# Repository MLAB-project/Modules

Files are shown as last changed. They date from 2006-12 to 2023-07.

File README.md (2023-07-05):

# MLAB hardware modules main repository

The MLAB Project was created to develop an universal kit to support hobbyist and professionals in the construction of simple or more complicated devices and instruments (robots, automation systems, testing kits and so on). It is primarily intended for engineers and scientists and it is in continuous development since 2003.

**This repository is archived because its contents have been split into separate repositories in the [MLAB-modules](https://github.com/mlab-modules/) organization. The development of new [MLAB](https://www.mlab.cz) components is still in progress and development has not been suspended. You can read about the reasons of the repository split on the [Discussions thread](https://github.com/orgs/MLAB-project/discussions/1).**

This repository is only a component of the [complete MLAB system](http://www.mlab.cz/)

## Modules

The principle of [Modular LABoratory](http://www.mlab.cz) is based on decomposition of complex systems into smaller cells or bricks (in MLAB called [modules](http://wiki.mlab.cz/doku.php?id=en:moduly)) such as communication interfaces, operational amplifiers, CPU modules, FPGA programmers and many other. Over years of development, [tenths of modules have been created](https://github.com/mlab-modules) - for easier orientation they are sorted into categories which are the first-level folders of this repository. Many modules are included as [repository submodules](https://git-scm.com/book/en/v2/Git-Tools-Submodules) in this parent repository. 



When creating modules, great emphasis is put on the quality of design and construction. The results can, therefore, meet the standards of even the most demanding users from the community of researchers, experimenters and innovators.

## How to start using MLAB

Further information can be found on [MLAB Wiki](http://wiki.mlab.cz/).

There is also a [Mailing list](https://groups.google.com/forum/#!forum/mlab-users) available for users and developers.

## Compatibility

Thanks to careful design, most of the modules are dimensionally and electrically compatible with many other products. Examples include the Arduino platform, the Merkur construction set, optical tables and DIN switchboard systems.

## Applications

See the [list of designs](http://home.mlab.cz/Server/GenIndex/GenIndex.php?path=%2FDesigns&lang=en) for an illustration of the wide spectrum of possible applications.

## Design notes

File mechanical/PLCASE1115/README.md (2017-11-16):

[Czech](./README.cs.md)
<!--- module --->
# PLCASE1115
<!--- Emodule --->

<!--- subtitle --->3D printable plastic case<!--- Esubtitle --->

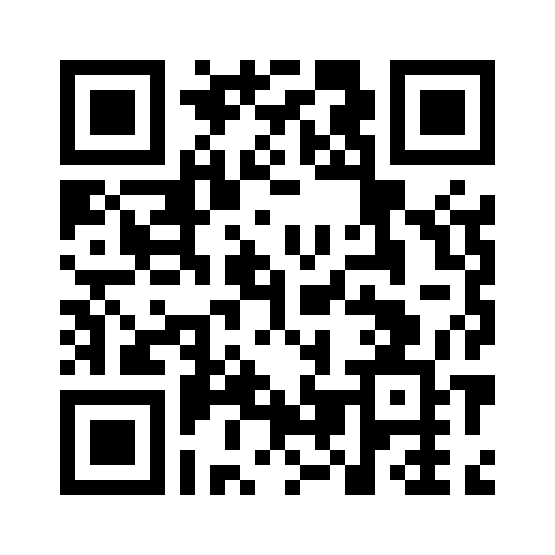
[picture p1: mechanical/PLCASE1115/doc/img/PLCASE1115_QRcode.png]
PLCASE1115


<!--- description --->Basic printable case for the base board with size 11x15 holes. <!--- Edescription --->

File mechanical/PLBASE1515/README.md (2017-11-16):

[Czech](./README.cs.md)
<!--- module --->
# PLBASE1515
<!--- Emodule --->

<!--- subtitle --->3D printable plastic base board<!--- Esubtitle --->

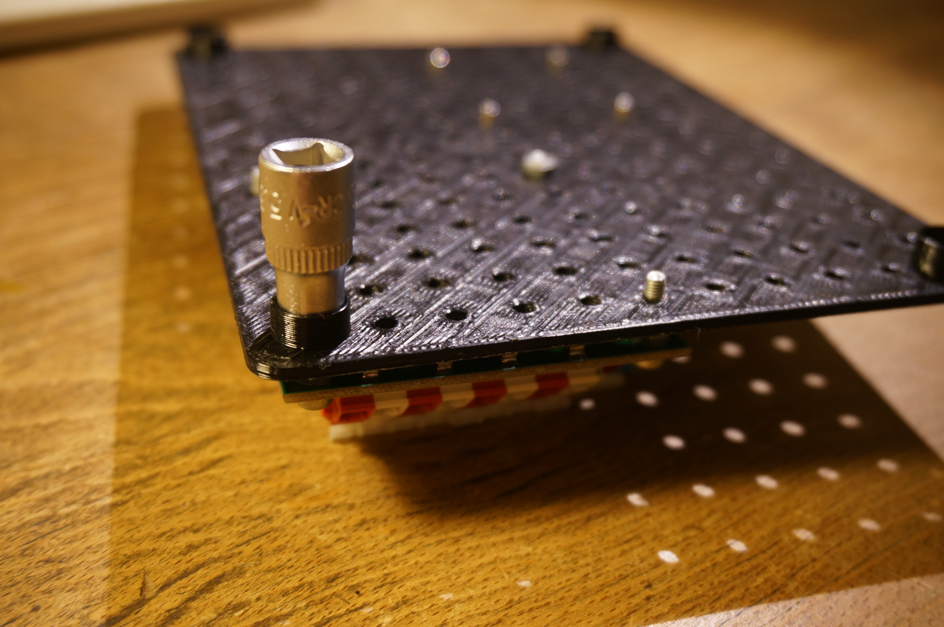
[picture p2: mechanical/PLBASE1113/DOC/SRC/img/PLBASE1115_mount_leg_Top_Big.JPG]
PLBASE1515


<!--- description --->This base board has size 11x15 holes and standard MLAB grid 400mils (10.16mm). It is especially suited for simple measuring instruments and mobile robots constructions. The board can be prited at almost any 3D printer.<!--- Edescription --->

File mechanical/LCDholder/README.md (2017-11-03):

[Czech](./README.cs.md)
<!--- module --->
# LCDholder
<!--- Emodule --->

<!--- subtitle --->3D printable LCD 16x2 holder for MLAB base boards<!--- Esubtitle --->

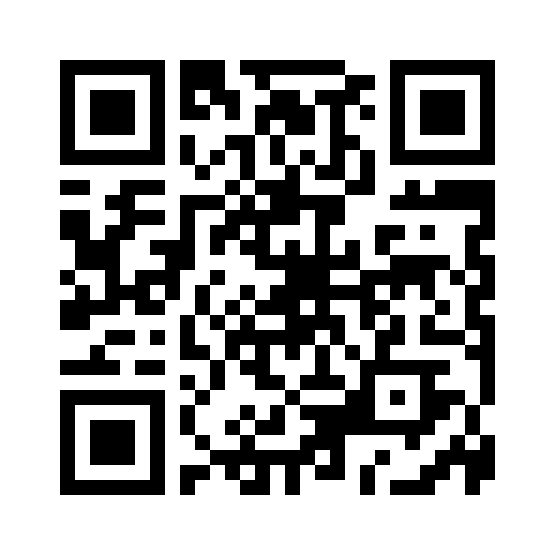
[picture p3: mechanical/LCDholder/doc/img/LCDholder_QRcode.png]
LCDholder


<!--- description --->The hodlder can be prited at almost any 3D printer.<!--- Edescription --->

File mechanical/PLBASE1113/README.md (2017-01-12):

<!--- PrjInfo ---> <!--- Please remove this line after manually editing --->
<!--- 00a56be08b96043df9e37d6aff7b6990 --->
<!--- Created:20170112-18:22: ---> 
<!--- Author:Mlab: ---> 
<!--- AuthorEmail:mlab@mlab.cz: ---> 
<!--- Tags:imported: ---> 
<!--- Ust:[End]: ---> 
<!--- Name:PLBASE1115: --->
#PLBASE1115 
<!--- LongName --->
3D printable plastic base board
<!--- ELongName ---> 

<!--- Lead --->
This base board has size 11x15 holes and standard MLAB grid 400mils (10.16mm). It is especially suited for simple measuring instruments and mobile robots constructions. The board can be prited at almost any 3D printer.
<!--- ELead ---> 

LeadImg 

<!--- Description --->
<!--- EDescription --->
<!--- Content --->
<!--- EContent --->

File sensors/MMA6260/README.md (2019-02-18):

<!--- PrjInfo ---> <!--- Please remove this line after manually editing --->
<!--- 00a56be08b96043df9e37d6aff7b6990 --->
<!--- Created:2019-02-18 14:38:43.239192: ---> 
<!--- Author:: ---> 
<!--- AuthorEmail:: ---> 
<!--- Tags:: ---> 
<!--- Ust:: ---> 
<!--- Label --->
<!--- ELabel ---> 
<!--- Name:MMA6260: --->
# MMA6260
<!--- LongName --->
## Simple 2axis analog accelerometer sensor
<!--- ELongName ---> 

<!--- Lead --->

<!--- ELead ---> 

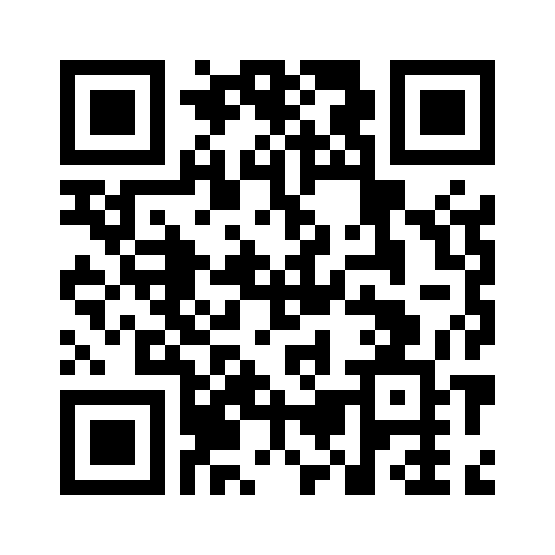
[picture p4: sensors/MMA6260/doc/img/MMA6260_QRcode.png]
MMA6260
 

<!--- Description --->
<!--- EDescription --->
<!--- Content --->
<!--- EContent --->
<sub><sup> Generated with [MLABweb](https://github.com/MLAB-project/MLABweb). (2019-02-18)</sup></sub>

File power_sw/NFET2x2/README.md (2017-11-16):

[Czech](./README.cs.md)
<!--- module --->
# NFET2x2
<!--- Emodule --->

<!--- subtitle --->2x2NFET Power Driver <!--- Esubtitle --->

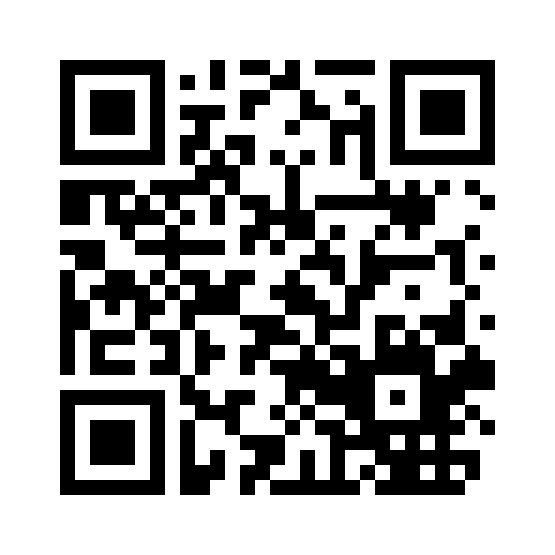
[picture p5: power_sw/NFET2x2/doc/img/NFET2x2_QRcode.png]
NFET2x2


<!--- description --->There are 4 NFETs switching to earth. Inductive load is allowed.<!--- Edescription --->

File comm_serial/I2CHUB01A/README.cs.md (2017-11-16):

[English](./README.md)
<!--- module --->
# I2CHUB01A
<!--- Emodule --->

<!--- subtitle ---> Hub pro sběrnici I2C (TWI) <!--- Esubtitle --->

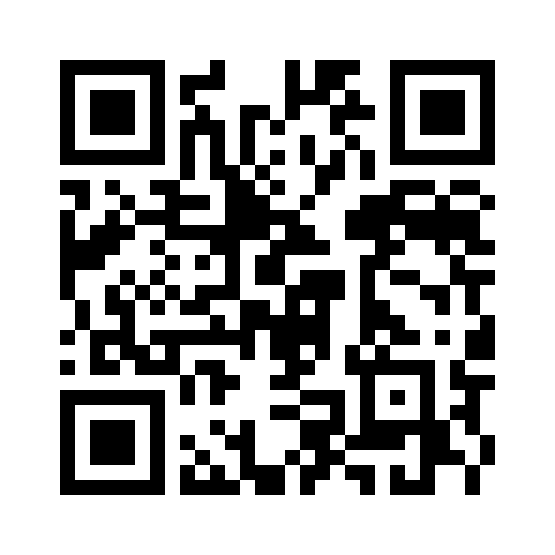
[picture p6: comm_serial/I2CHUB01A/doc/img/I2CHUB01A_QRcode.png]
I2CHUB01A


<!--- description ---> Umožňuje propojení většího počtu I2C zařízení. Neobsahuje žádnou konfigurovatelnou logiku.<!--- Edescription --->

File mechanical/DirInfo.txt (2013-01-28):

//
// Toto je popisný soubor pro popis obsahu adresáře
//

[InfoShortDescription.en]
  Mechanical

[InfoShortDescription.cs]
  Mechanické části
  
[InfoLongDescription.en]
  Universal boxes, base plates and other mechanical accessories.

[InfoLongDescription.cs]
  Univerzální krabičky, základní desky a další mechanické příslušenství.

[SortPreferences]

[End]

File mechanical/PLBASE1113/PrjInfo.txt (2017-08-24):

[InfoShortDescription.en]
3D printable plastic base board

[InfoShortDescription.cs]
3D tisknutelná základní deska

[InfoLongDescription.en]
This base board has size 11x15 holes and standard MLAB grid 400mils (10.16mm). It is especially suited for simple measuring instruments and mobile robots constructions. The board can be prited at almost any 3D printer.

[InfoLongDescription.cs]
Základní deska má 11x15 děr se standardní MLAB roztečí 400mils (10.16mm). Je vhodná pro malé konstrukce, jako jsou jednoduché meřící přístroje nebo základní mobilní roboti. Je tisknutelná téměř na každé 3D tiskárně.

[InfoBuyUST]

[End]

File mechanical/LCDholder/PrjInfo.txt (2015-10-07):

[InfoShortDescription.en]
3D printable LCD 16x2 holder for MLAB base boards

[InfoShortDescription.cs]
3D tisknutelný držák LCD 16x2 pro MLAB základní desky

[InfoLongDescription.en]
The hodlder can be prited at almost any 3D printer.

[InfoLongDescription.cs]
Držák je tisknutelný téměř na každé 3D tiskárně.

[InfoBuyUST]

[End]

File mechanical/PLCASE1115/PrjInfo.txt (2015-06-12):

[InfoShortDescription.en]
3D printable plastic case

[InfoShortDescription.cs]
3D tisknutelná krabička 

[InfoLongDescription.en]
Basic printable case for the base board with size 11x15 holes. 

[InfoLongDescription.cs]
Jednoduchá tisknutelná krabička na základní desku rozměru 11x15 děr.

[InfoBuyUST]

[End]

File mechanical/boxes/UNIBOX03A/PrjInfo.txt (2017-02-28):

[InfoShortDescription.en]
Permanent device housing box

[InfoShortDescription.cs]
Krabička pro permanentní konstrukce

[InfoLongDescription.en]
Universal metal module housing box with interchangeable front and back panels. Useful for housing construction of devices created from MLAB modules. With a pair of sidewalls printable 3D printer. Dimensions 220x160x51.5 mm. 

[InfoLongDescription.cs]
Univerzální kovová krabička pro zakrytování permanentních konstrukcí z modulů MLAB. S dvojicí tisknutelných bočnic na 3D tiskárně. Rozměry 220x160x51.5 mm.  

[End]

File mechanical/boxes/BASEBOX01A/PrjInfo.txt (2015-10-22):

[InfoShortDescription.en]
3D printable device housing box

[InfoShortDescription.cs]
3D tisknutelná krabička pro permanentní konstrukce

[InfoLongDescription.en]
The printed plastic parts are sandwiched between standard hole-grid plates which makes the enclosure very rigid. The box sides can be easily customized for individual project needs, or separately exchanged during an instrument development.

[InfoLongDescription.cs]
Univerzální krabička tisknutelná 3D tiskárnou pro zakrytování permanentních konstrukcí z modulů MLAB.  

[End]

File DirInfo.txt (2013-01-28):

//
// Toto je popisný soubor pro popis obsahu adresáře
//

[InfoShortDescription.en]
  Overview of MLAB Modules

[InfoShortDescription.cs]
  Přehled modulů MLAB
  
[InfoLongDescription.en]
  You can find an overview of MLAB Modules here. They are organised
  to groups by their function.
  
[InfoLongDescription.cs]
  Moduly jsou univerzální "kostky" do stavebnice MLAB. Protože jich je
  hodně, jsou dále rozčleněny po skupinách.

[SortPreferences]
  AVR
  ARM
  PIC
  CommIR
  CommRF
  CommSerial
  Clock
  TDC
  PowerSupply
  PowerSW
  H_Bridge
  Sensors
  HumanInterfaces
  Measuring
  Memory
  Audio
  OpAmps
  ADconverters
  Universal
  Mechanical

[End]

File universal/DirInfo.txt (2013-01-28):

//
// Toto je popisný soubor pro popis obsahu adresáře
//

[InfoShortDescription.en]
  Universal PCBs

[InfoShortDescription.cs]
  Univerzální desky
  
[InfoLongDescription.en]
  Universal soldering circuit boards and more.

[InfoLongDescription.cs]
  Univerzální pájecí plošné spoje a další.

[SortPreferences]

[End]

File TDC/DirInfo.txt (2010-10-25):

//
// Toto je popisný soubor pro popis obsahu adresáře
//

[InfoShortDescription.en]
  Time to Digital Converters

[InfoShortDescription.cs]
  Časově digitální převodníky
  
[InfoLongDescription.en]
  Modules for experimentation with time interval signals in digital systems. e.g. LASER ranging.

[InfoLongDescription.cs]
  Moduly pro digitalizaci časových intervalů. Hodí se pro experimenty, jako je například LASERové měření vzdálenosti.

[SortPreferences]

[End]

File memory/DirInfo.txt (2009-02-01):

//
// Toto je popisný soubor pro popis obsahu adresáře
//

[InfoShortDescription.en]
  Storage devices

[InfoShortDescription.cs]
  Paměťové prvky
  
[InfoLongDescription.en]
  Memory and data storage modules.

[InfoLongDescription.cs]
  Moduly určené k uchovávání dat.

[SortPreferences]

[End]

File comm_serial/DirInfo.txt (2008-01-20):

//
// Toto je popisný soubor pro popis obsahu adresáře
//

[InfoShortDescription.en]
  Serial communication

[InfoShortDescription.cs]
  Sériová komunikace
  
[InfoLongDescription.en]
  Serial communication includes ordinary RS232 and 
  USB, I2C and so on.
  
[InfoLongDescription.cs]
  Sériová komunikace zahrnuje přenos dat po RS232, ale 
  i přenos pomocí USB, I2C a podobně.

[SortPreferences]

[End]

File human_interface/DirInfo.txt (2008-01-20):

//
// Toto je popisný soubor pro popis obsahu adresáře
//

[InfoShortDescription.en]
 Human Interface Modules

[InfoShortDescription.cs]
  Moduly pro interakci s uživatelem
  
[InfoLongDescription.en]
  Modules for interaction with a user. Displays, indicators,
  switches, push buttons and so on.

[InfoLongDescription.cs]
  Jedná se o moduly displejů, indikátorů a vstupů od uživatele.
  Tlačítka, spínače a podobně.

[SortPreferences]

[End]

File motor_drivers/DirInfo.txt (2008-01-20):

//
// Toto je popisný soubor pro popis obsahu adresáře
//

[InfoShortDescription.en]
  H-Bridge Modules

[InfoShortDescription.cs]
  Moduly H-můstků
  
[InfoLongDescription.en]
  Modules for bipolar switching, mainly used for motor driving.

[InfoLongDescription.cs]
  Moduly umožňující bipolární spínání napětí, zejména pro 
  účely řízení motorů.

[SortPreferences]

[End]

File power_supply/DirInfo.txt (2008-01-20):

//
// Toto je popisný soubor pro popis obsahu adresáře
//

[InfoShortDescription.en]
  Power Supply

[InfoShortDescription.cs]
  Napájecí zdroje
  
[InfoLongDescription.en]
  You can find here power supplies, stabilisers and battery
  circuits.
  
[InfoLongDescription.cs]
  Zde jsou napájecí zdroje, stabilizátory a obvody s bateriemi.

[SortPreferences]

[End]

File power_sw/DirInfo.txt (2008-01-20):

//
// Toto je popisný soubor pro popis obsahu adresáře
//

[InfoShortDescription.en]
  Power Switches

[InfoShortDescription.cs]
  Výkonové spínače
  
[InfoLongDescription.en]
  Power Switches for switching of bigger voltages and currents
  which exceeded processor's capabilities.

[InfoLongDescription.cs]
  Výkonové spínače pro spínání proudů a napětí, které přesahují 
  možnosti samotných procesorů.

[SortPreferences]

[End]

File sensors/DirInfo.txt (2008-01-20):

//
// Toto je popisný soubor pro popis obsahu adresáře
//

[InfoShortDescription.en]
  Sensors

[InfoShortDescription.cs]
  Senzory
  
[InfoLongDescription.en]
  Sensors, mainly for robotics and measurement of the environment.

[InfoLongDescription.cs]
  Senzory, hlavně pro robotiku a měření prostředí.

[SortPreferences]

[End]

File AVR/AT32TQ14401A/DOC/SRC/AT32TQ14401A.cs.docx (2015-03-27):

Modul pro mikrokontroléry Atmel AVR32 řady AT32UC3A

Jakub Kákona

## Modul obsahuje potřebné součástky pro provoz mikrokontroléru Atmel AVR32 řady AT32UC3A.

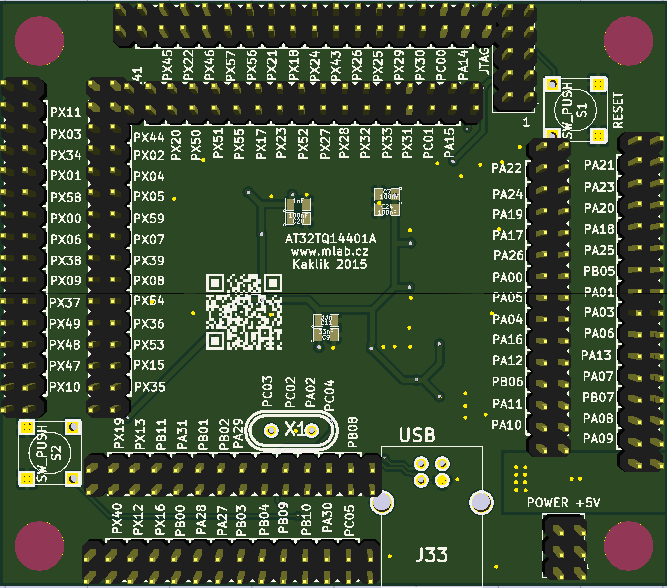
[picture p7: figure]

# 1. Technické parametry

Parametr | Hodnota | Poznámka
Napájení | 5 V
Rozměry | 80 x 70 x 16 mm | Výška nad základní deskou

# 2. Osazení a oživení

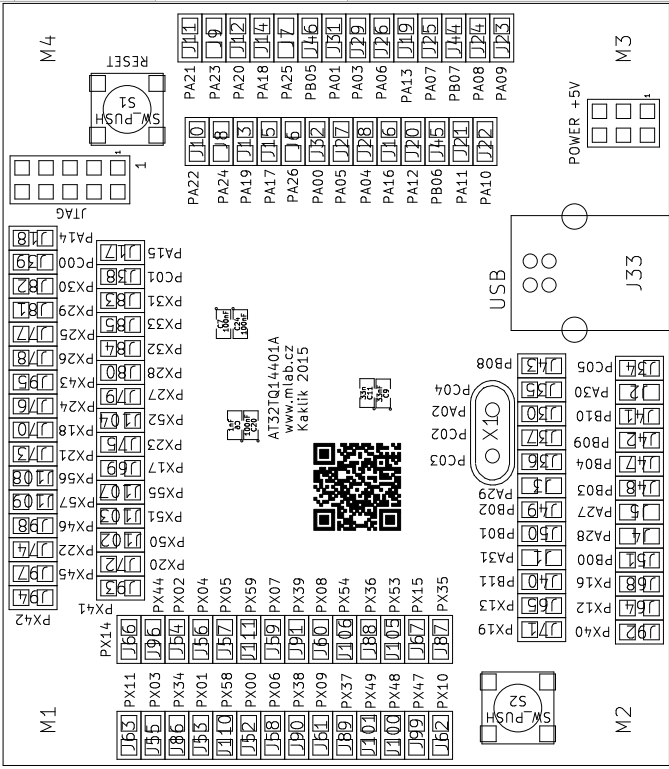
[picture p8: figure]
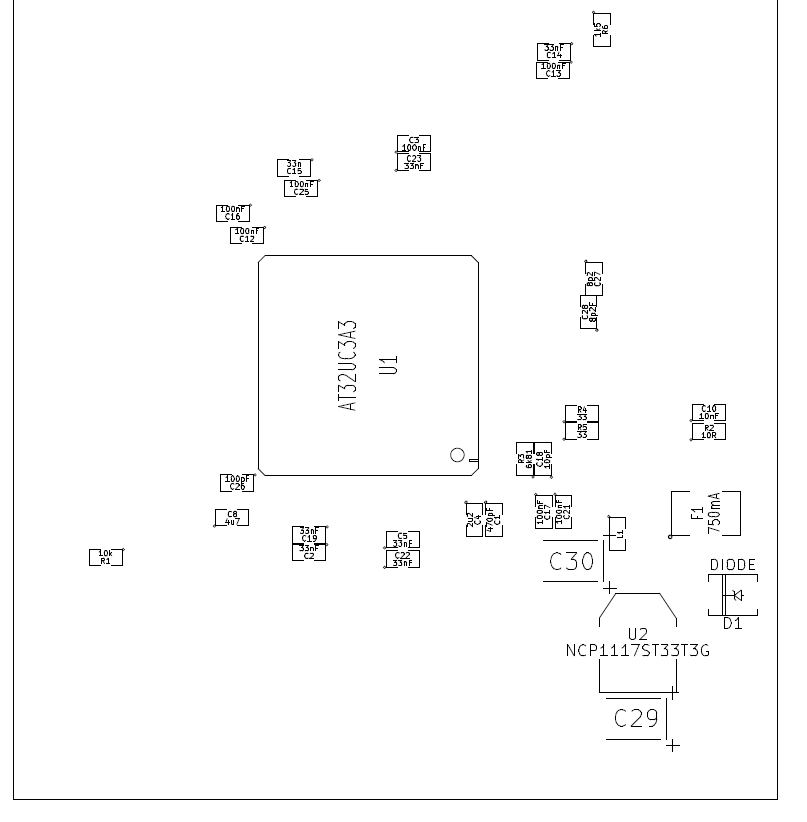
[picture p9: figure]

## 2.1. Osazení

Označení | Množství | Hodnota | Pouzdro
U1 | 1 | AT32UC3A3 | TQFP144
C1 | 1 | 470pF | SM0805
C2,C5,C9,C14,C19,C22,C23 | 7 | 33nF | SM0805
C3,C7,C12,C13,C16,C17,C20,C21,C24,C25 | 10 | 100nF | SM0805
C4 | 1 | 2u2 | SM0805
C6 | 1 | 1nF | SM0805
C8 | 1 | 4u7 | SM0805
C10 | 1 | 10nF | SM0805
C11,C15 | 2 | 33n | SM0805
C18 | 1 | 10pF | SM0805
C26 | 1 | 100pF | SM0805
C27,C28 | 2 | 8p2 | SM0805
F1 | 1 | 750mA | SM1812
J33 | 1 | USB | USB_B
R1 | 1 | 10k | SM0805
R3 | 1 | 6k81 | SM0805
R4,R5 | 2 | 33 | SM0805
R6 | 1 | 1k5 | SM0805
X1 | 1 | 12MHz | Crystal_HC49-U_Vertical
D1 | 1 | DIODE | DO-214AC(SMA)
J1 - J111 | 110 | JUMP_2_CONN | Pin_Header_Straight_2x01
L1 | 1 | BLM21PG300SN1 | SM0805
R2 | 1 | 10R | SM0805
U2 | 1 | NCP1117ST33T3G | SOT223
C29,C30 | 2 | 10uF | TantalC_SizeB_EIA-3528_Reflow
M1,M2,M3,M4 | 4 | HOLE 3mm | MountingHole_3mm
CON1 | 1 | AVR-JTAG-10 | Straight_2x05
J112 | 1 | HEADER_2x03 | Straight_2x03
S1,S2 | 2 | SW_PUSH | SW_PUSH_SMALL

AT32TQ14401A / 2015-03-27 / jacho/ http://www.mlab.cz 3 / 3

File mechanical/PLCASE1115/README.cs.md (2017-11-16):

[English](./README.md)
<!--- module --->
# PLCASE1115
<!--- Emodule --->

<!--- subtitle --->3D tisknutelná krabička <!--- Esubtitle --->

PLCASE1115

<!--- description --->Jednoduchá tisknutelná krabička na základní desku rozměru 11x15 děr.<!--- Edescription --->

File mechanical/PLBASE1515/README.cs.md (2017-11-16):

[English](./README.md)
<!--- module --->
# PLBASE1515
<!--- Emodule --->

<!--- subtitle --->3D tisknutelná základní deska<!--- Esubtitle --->

PLBASE1515

<!--- description --->Základní deska má 11x15 děr se standardní MLAB roztečí 400mils (10.16mm). Je vhodná pro malé konstrukce, jako jsou jednoduché meřící přístroje nebo základní mobilní roboti. Je tisknutelná téměř na každé 3D tiskárně.<!--- Edescription --->

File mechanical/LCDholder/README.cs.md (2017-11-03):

[English](./README.md)
<!--- module --->
# LCDholder
<!--- Emodule --->

<!--- subtitle --->3D tisknutelný držák LCD 16x2 pro MLAB základní desky<!--- Esubtitle --->

LCDholder

<!--- description --->Držák je tisknutelný téměř na každé 3D tiskárně.<!--- Edescription --->

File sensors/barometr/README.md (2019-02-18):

<!--- PrjInfo ---> <!--- Please remove this line after manually editing --->
<!--- 00a56be08b96043df9e37d6aff7b6990 --->
<!--- Created:2019-02-18 14:39:19.248198: ---> 
<!--- Author:: ---> 
<!--- AuthorEmail:: ---> 
<!--- Tags:: ---> 
<!--- Ust:: ---> 
<!--- Label --->
<!--- ELabel ---> 
<!--- Name:barometr: --->
# barometr
<!--- LongName --->
## Barometric sensor
<!--- ELongName ---> 

<!--- Lead --->

<!--- ELead ---> 

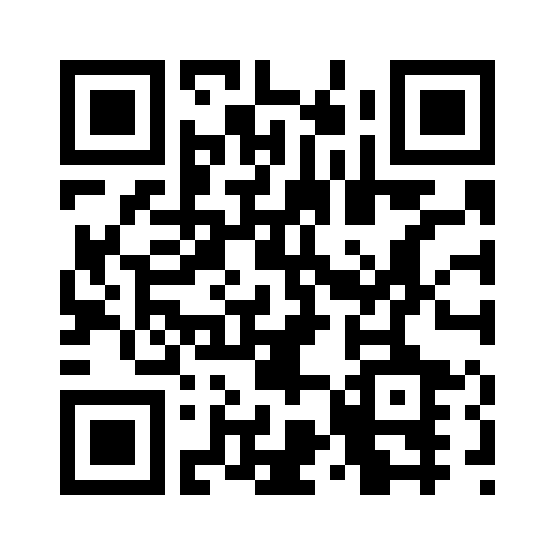
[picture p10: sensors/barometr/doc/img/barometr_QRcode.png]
barometr
 

<!--- Description --->
<!--- EDescription --->
<!--- Content --->
<!--- EContent --->
<sub><sup> Generated with [MLABweb](https://github.com/MLAB-project/MLABweb). (2019-02-18)</sup></sub>

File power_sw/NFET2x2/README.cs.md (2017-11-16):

[English](./README.md)
<!--- module --->
# NFET2x2
<!--- Emodule --->

<!--- subtitle --->2x2NFET výkonový budič<!--- Esubtitle --->

NFET2x2

<!--- description --->Modul slouží jako čtyřnásobný výkonový budič se spínáním dozemě. Spínaná zátěž může mít indukční charakter.<!--- Edescription --->

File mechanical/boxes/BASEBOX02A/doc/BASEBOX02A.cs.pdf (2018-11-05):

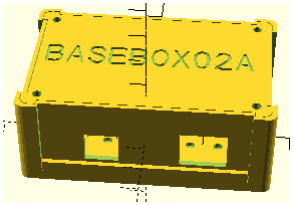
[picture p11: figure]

BASEBOX02A/ jacho / http://www.mlab.cz | 1 / 2

# Univerzální krabička

Jan Chroust

### Univerzální krabička pro trvalé konstrukce, která je tisknutelná na 3D tiskárnách. Krabička se skládá ze tří částí (dno s bokem, vrchní kryt, spodní kryt)

# 1.Technické parametry

Parametr | Hodnota | Poznámka
Rozměr | volitelný
Počet děr | volitelný
Rozteč děr | 10.16 mm

BASEBOX02A/ jacho / http://www.mlab.cz | 2 / 2

# 2.Výroba a použití

## 2.1.Úvodem

Jedná se o univerzální krabičku pro zařízení vycházející z MLAB modulů. Krabička se skládá ze tří částí. Dno krabičky s boky a vrchní kryt jsou potřeba vždy. Spodní kryt je potřeba pouze
v případech, kdy chceme schovat šrouby s matkami, které koukají ze dna boxu.

Rozměry krabičky jsou omezeny pouze vlastnostmi 3D tiskárny. K modifikaci krabičky je potřeba programu OpenSCAD. Tento program je volně ke stažení jak pro Linux, tak pro Windows.

Zdrojový kód boxu byl napsán tak, aby modifikace krabička byla co možná nejjednodušší.

## 2.2.Úprava krabičky

Nejprve je potřeba si nainstalovat program OpenSCAD.

Před zahájením úprav je potřeba si překopírovat celý obsah složky v CAD v SVN MLAB.

Popis stažených souborů a složek. Soubory uložené ve složce configuration nejsou určeny pro běžné uživatele. Soubory ve složce print_data jsou umístěny soubory, které jsou pro generování dat pro tisk. Běžný uživatel by měl pracovat především se soubory assembly, configuration, upravena_bocnice.

2.2.1.Soubor configuration

V tomto souboru se definují parametry boxu. Je dobré začít nastavením právě jich. Jedná se o nastavení rozměru krabičky a tlouštěk stěn atd. Popis je proveden v komentářích přímo v souboru.

2.2.2.Soubor assembly

V tomto souboru se generuje náhled na výsledný vzhled boxu.

### 2.2.3. Soubor uprava_bocnice

Zde je potřeba upravit bočnice boxu, aby měli požadované otvory.

Postupně budou vznikat nové otvory potřebné pro zakomponování modulů MLAB do boxu. Jejich knihovna je umístěna ve složce configuration v souboru otvory.

Je možné si vytvořit i vlastní otvory v rámci knihovny. Model počítá s tím, že počátek je v ose šroubu (osa X) a v úrovni základní děrované desky (osa Z).

V souboru uprava_bocnice je ukázáno použití otvorů z knihovny. Otvory se pohybují vždy se skokem o rozteči děr základní desky na moduly. Není předpokládáno, že by byl modul umístěn mimo otvory v desce.

## 2.3.Použití

Jakákoliv konstrukce dle uvážení.

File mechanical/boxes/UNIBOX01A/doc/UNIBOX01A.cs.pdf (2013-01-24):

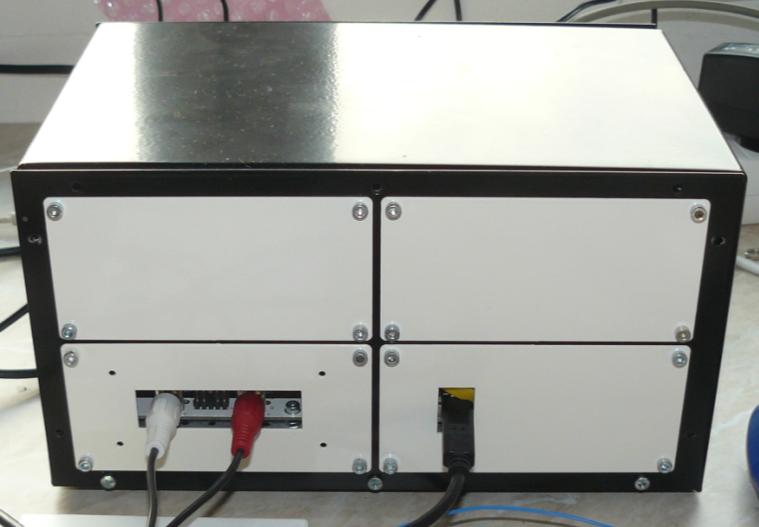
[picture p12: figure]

UNIBOX01A / jacho / 2013-01-24 / http://www.mlab.cz | 1 / 11
UNIBOX01A | MLAB

# Univerzální stavebnicová krabička

Jan Chroust

### Využití modulární stavebnice MLAB roste a už není dostačující umístění pouze na ALBASE (základní desce). Proto byla navržena univerzální krabička, nejenom pro stavebnici MLAB, ale i pro

jakékoli jiné konstrukce. Nejedná se o tradiční univerzální krabičku,

jaká je běžně dostupná v obchodech, ale o krabičku která umožňuje velkou variabilitu sestavení, tak jako sama modulární stavebnice MLAB. Uživatel si může vybrat z velkého množství již hotových čelních komponentů, které jsou připraveny pro montáž často využívaných prvků (tlačítka, potenciometry, konektory, vypínače…) a pro ty co si nevyberou je připraveno univerzální čelíčko, které je

možné si upravit podle své potřeby. Celá konstrukce je z duralu,

### který by měl zajistil odolnost konstrukce a dlouhá léta provozu bez

rezu.

# 1.Technické parametry

Parametr | Hodnota | Poznámka
Vnější rozměr | 250 x 140 x 160 mm

UNIBOX01A | MLAB

# 2. Úvodem

Univerzální stavebnicová krabička je předurčena pro veškeré konstrukce, které potřebují zajistit zvýšenou mechanickou odolnost a lepší vzhled.

UNIBOX01A | MLAB

# 3.Konstrukce

UNIBOX01-BC (Bottom Cover)

Spodní díl krabičky sloužící k uchycení montážní desky.

UNIBOX01-TC (Top Cover)

Horní díl krabičky sloužící k jejímu uzavření.

UNIBOX01-FP (Front Panel)

Přední nebo zadní pohledové čelo, do kterého budou umístěny ovládací prvky.

UNIBOX01-FPxx (Front Panel)

Malá přední nebo zadní čela. Každé hlavním čelo UNIBOX01-FP obsahuje 4ks těchto čel dle libovolného výběru.

UNIBOX01-MD (Mount Desk)

Základní montážní deska určená pro přímou montáž do krabičky.

UNIBOX01-BH (Bottom Holder)

Spodní držák krabičky určený k uchycení celé krabičky na rovnou plochu.

# 4.Dokumentace

## 4.1. UNIBOX01-BC (Bottom Cover)

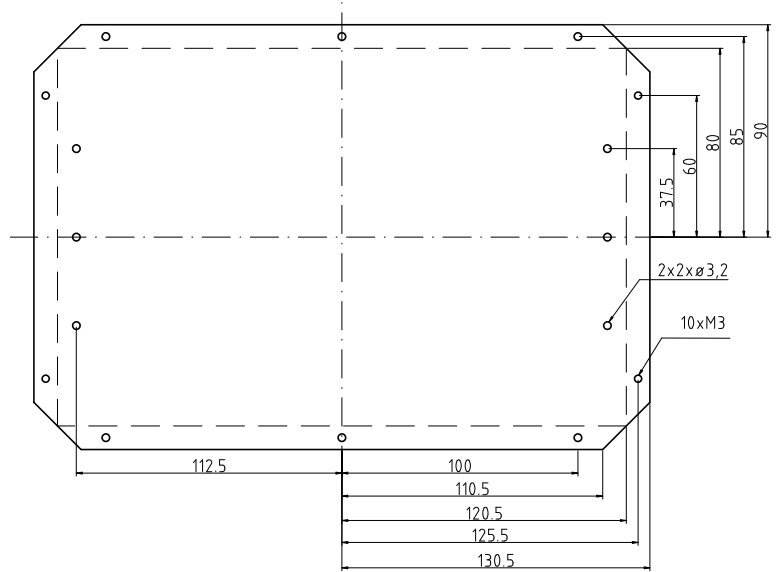
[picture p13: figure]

UNIBOX01A | MLAB

## 4.2.UNIBOX01-TC (Top Cover)

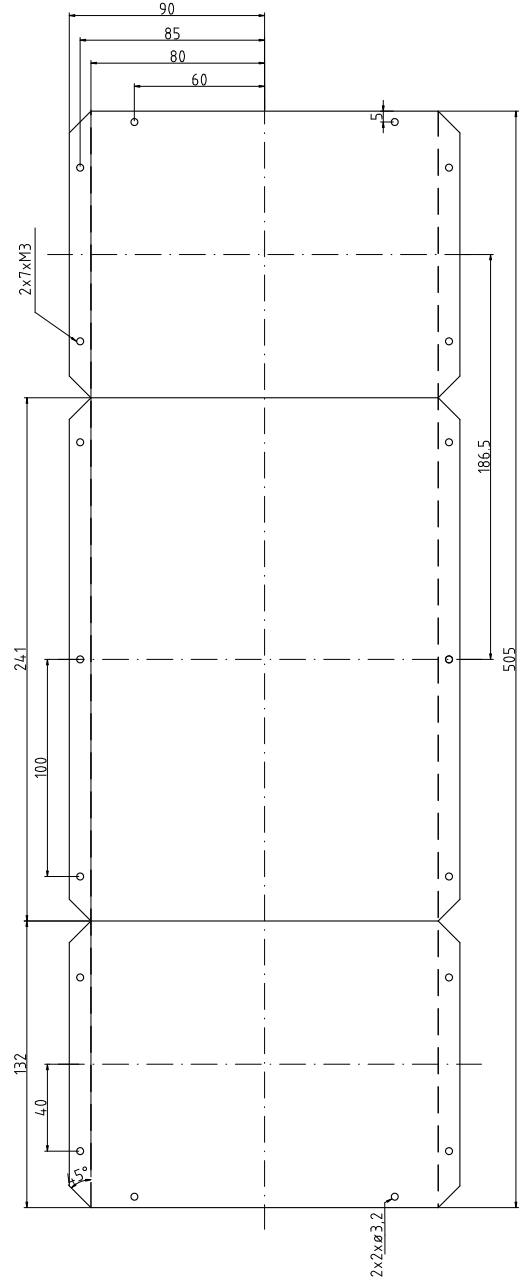
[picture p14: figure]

UNIBOX01A | MLAB

## 4.3.UNIBOX01-FP (Front Panel)

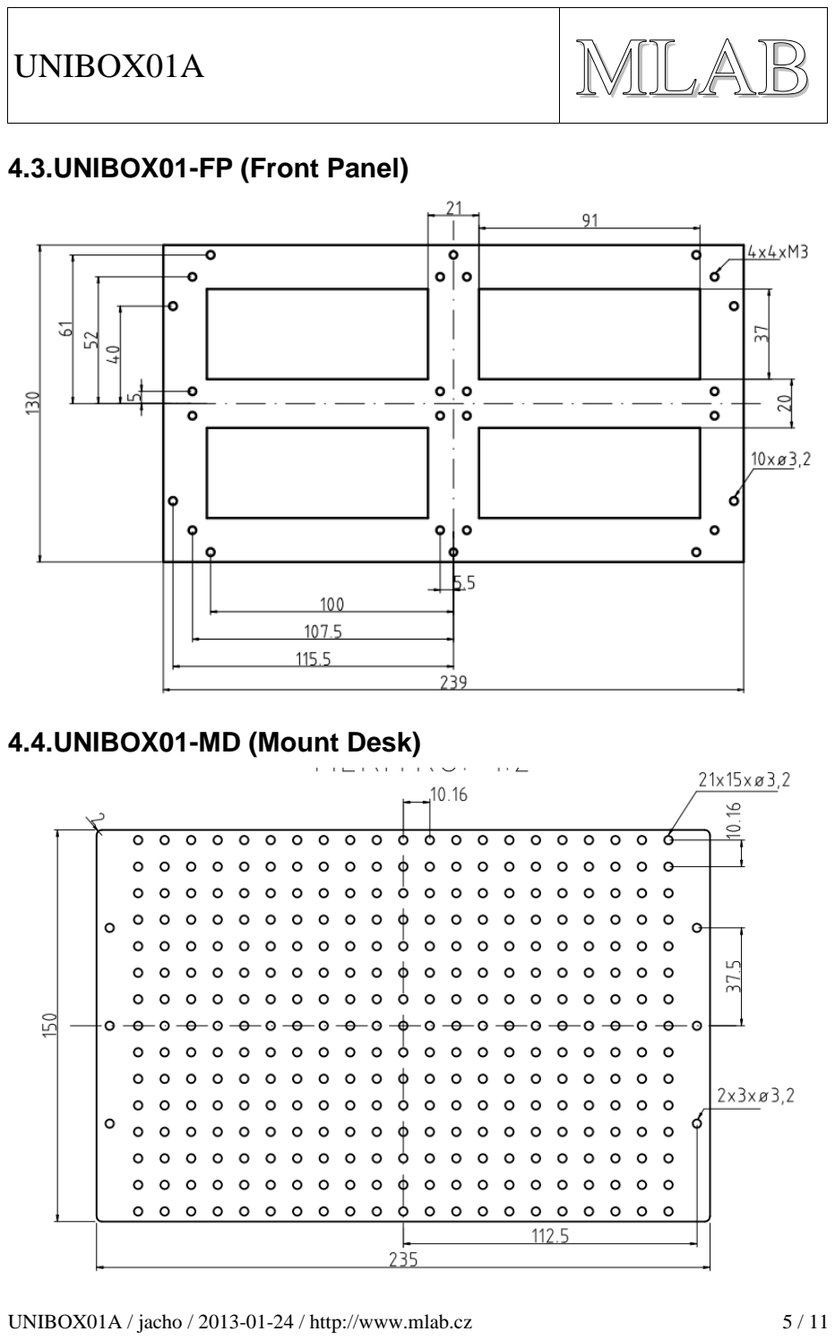
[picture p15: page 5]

## 4.4.UNIBOX01-MD (Mount Desk)

UNIBOX01A | MLAB

## 4.5.UNIBOX01-BH (Bottom Holder)

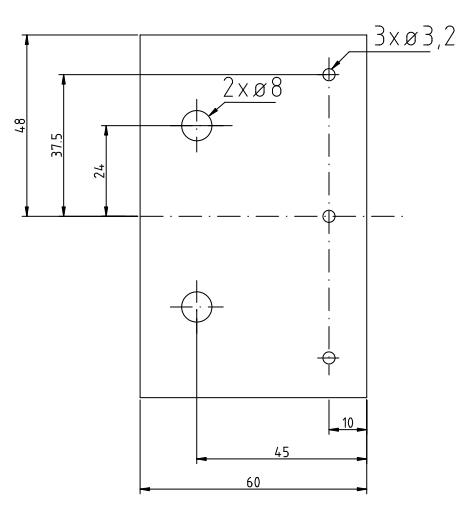
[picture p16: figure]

## 4.6.UNIBOX01-FPxx

Jedná se o malá čelíčka, která se montují na hlavní čelo. Níže jsou uvedené výkresy jednotlivých čelíček, pro snadný výběr. Uvedené využití je informativní a nebrání využit čelíčka pro jakýkoliv jiný účel. Materiál čelíček je dural síly 1mm. Barva je bílá. Není možné vyrábět čelíčka, která by vyhovovala každé realizaci. Naštěstí úprava čelíček dle vlastních potřeb je velmi snadná. Je možné vrtat, vyrážet a pilovat další otvory. V budoucnu budou přibývat další čelíčka, tak snad individuálních úprav bude ubývat.

UNIBOX01A | MLAB

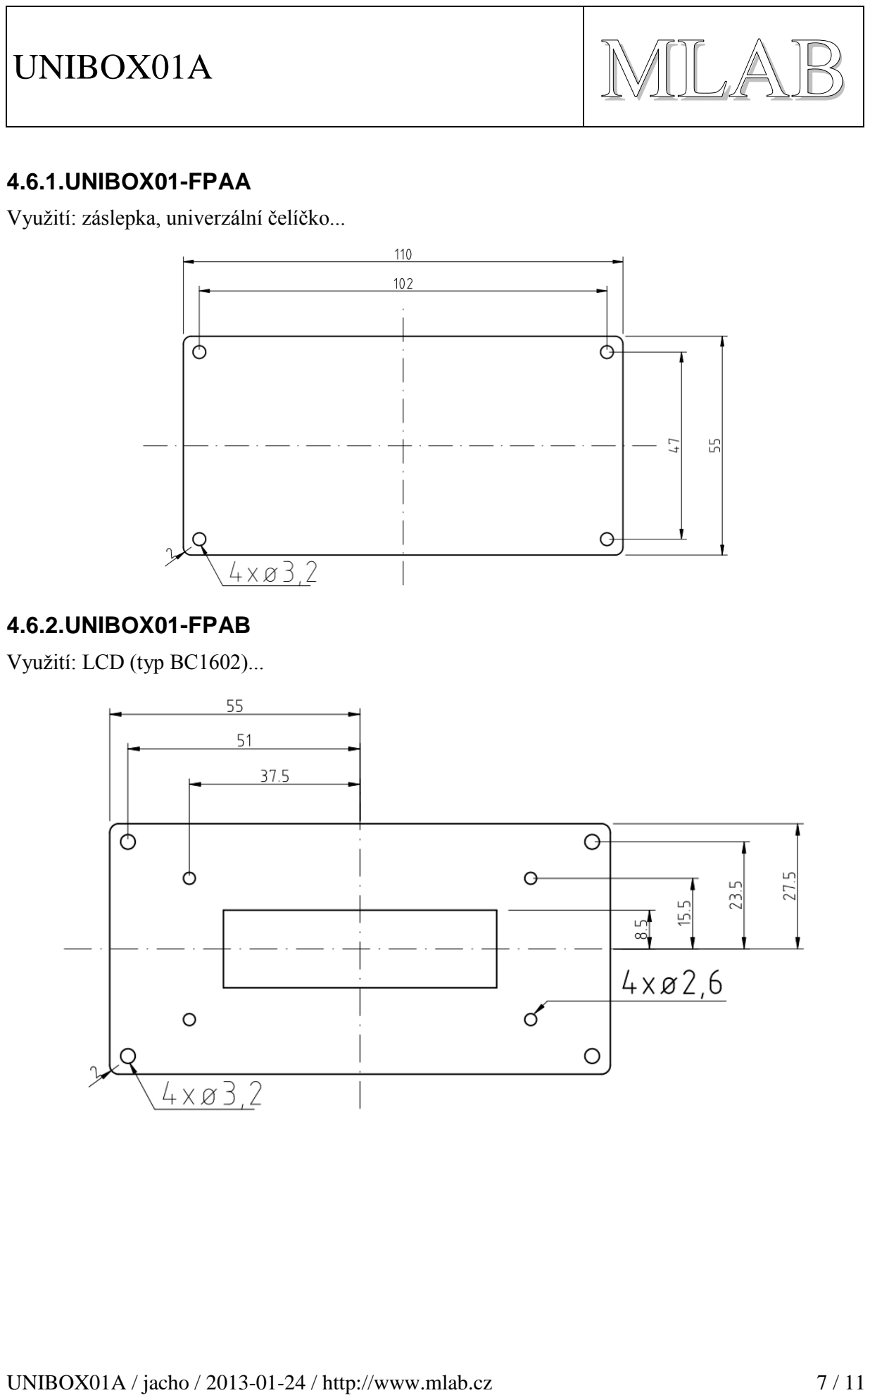
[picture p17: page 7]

4.6.1.UNIBOX01-FPAA

Využití: záslepka, univerzální čelíčko...

4.6.2.UNIBOX01-FPAB

Využití: LCD (typ BC1602)...

UNIBOX01A | MLAB

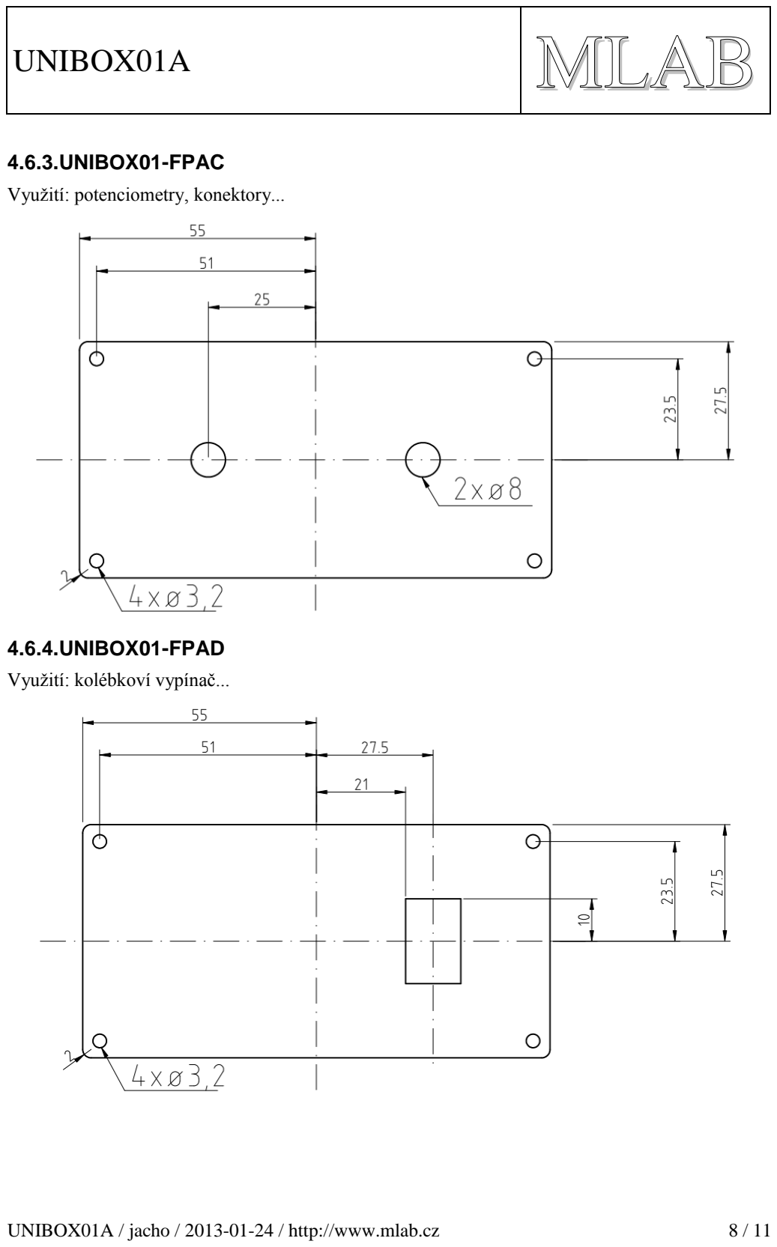
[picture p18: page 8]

4.6.3.UNIBOX01-FPAC

Využití: potenciometry, konektory...

4.6.4.UNIBOX01-FPAD

Využití: kolébkoví vypínač...

UNIBOX01A | MLAB

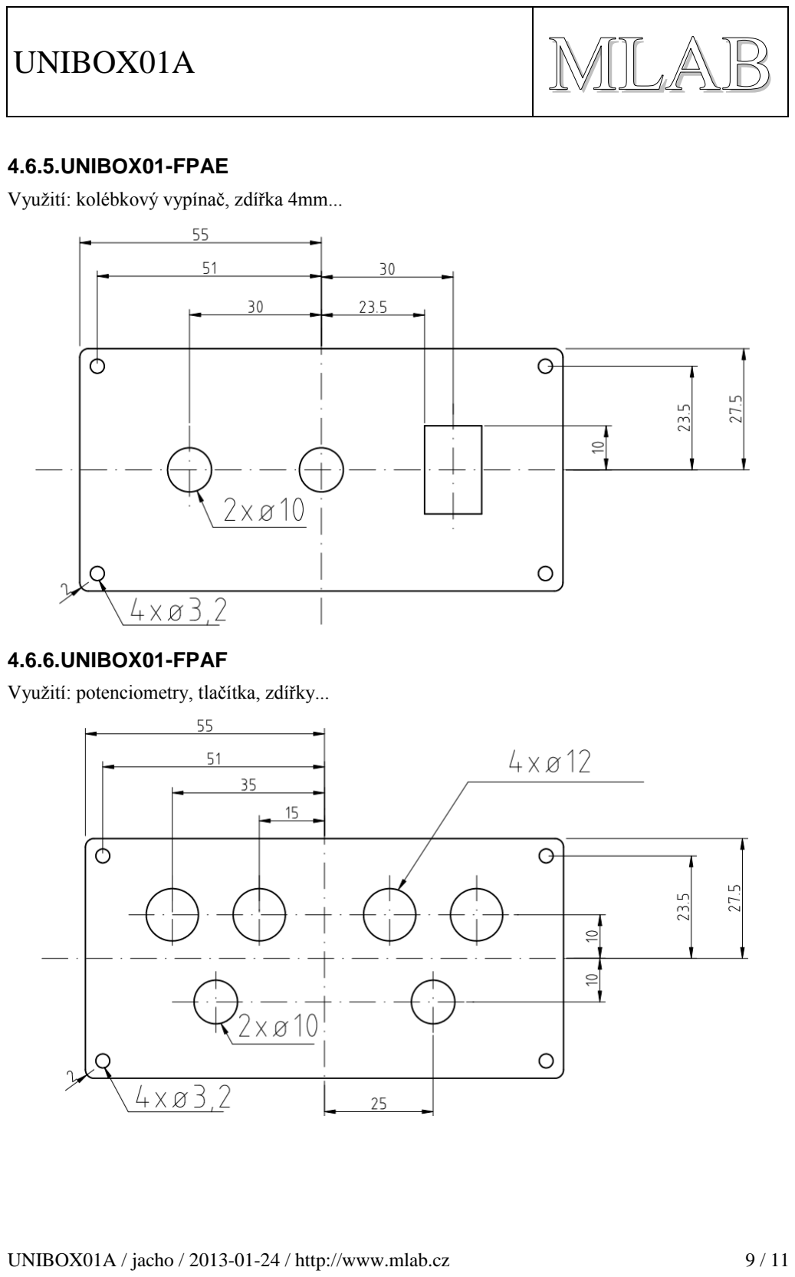
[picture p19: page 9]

4.6.5.UNIBOX01-FPAE

Využití: kolébkový vypínač, zdířka 4mm...

4.6.6.UNIBOX01-FPAF

Využití: potenciometry, tlačítka, zdířky...

UNIBOX01A | MLAB

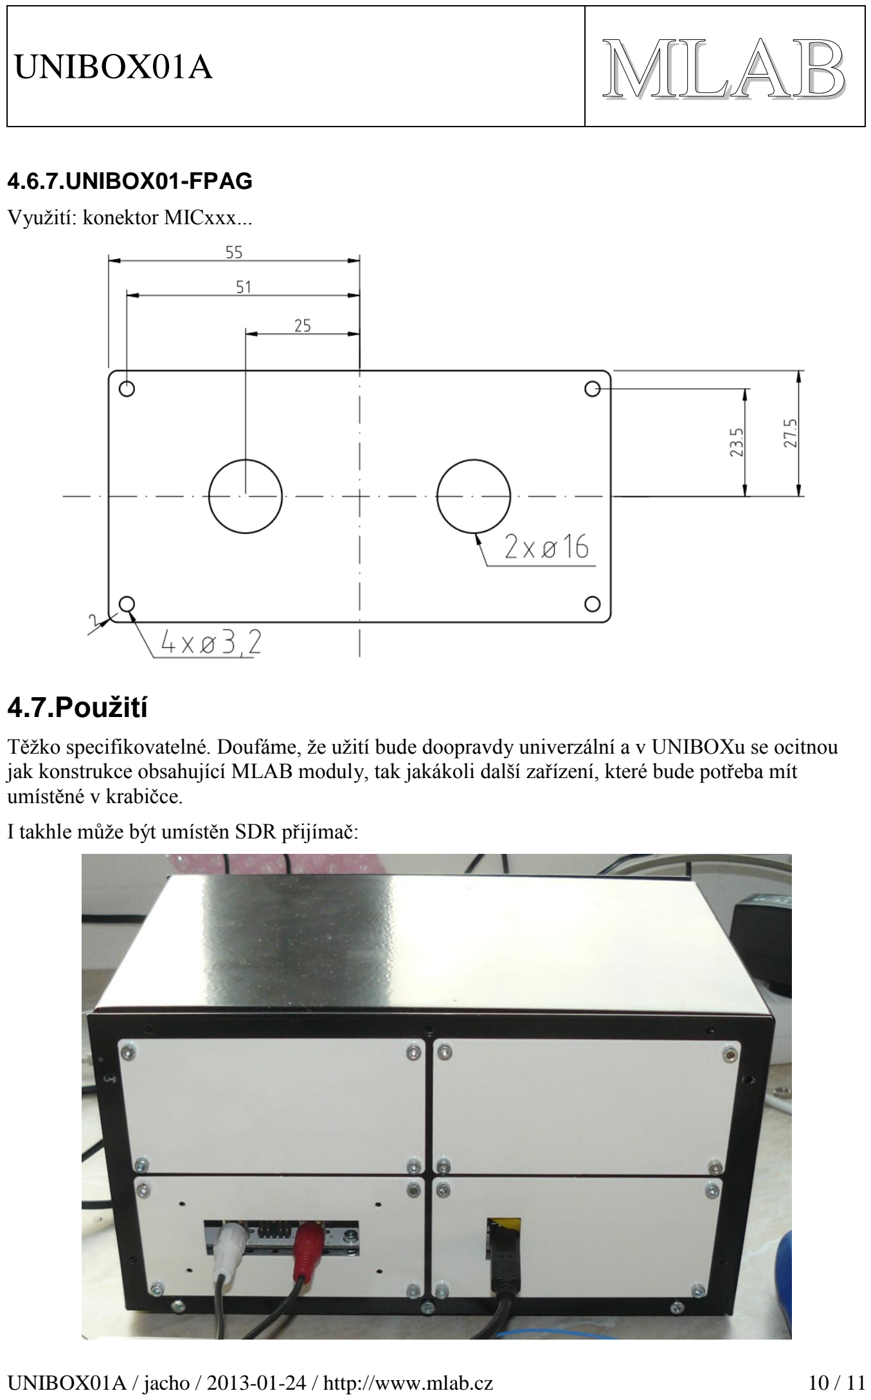
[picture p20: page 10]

4.6.7.UNIBOX01-FPAG

Využití: konektor MICxxx...

## 4.7.Použití

Těžko specifikovatelné. Doufáme, že užití bude doopravdy univerzální a v UNIBOXu se ocitnou jak konstrukce obsahující MLAB moduly, tak jakákoli další zařízení, které bude potřeba mít umístěné v krabičce.

I takhle může být umístěn SDR přijímač:

UNIBOX01A | MLAB

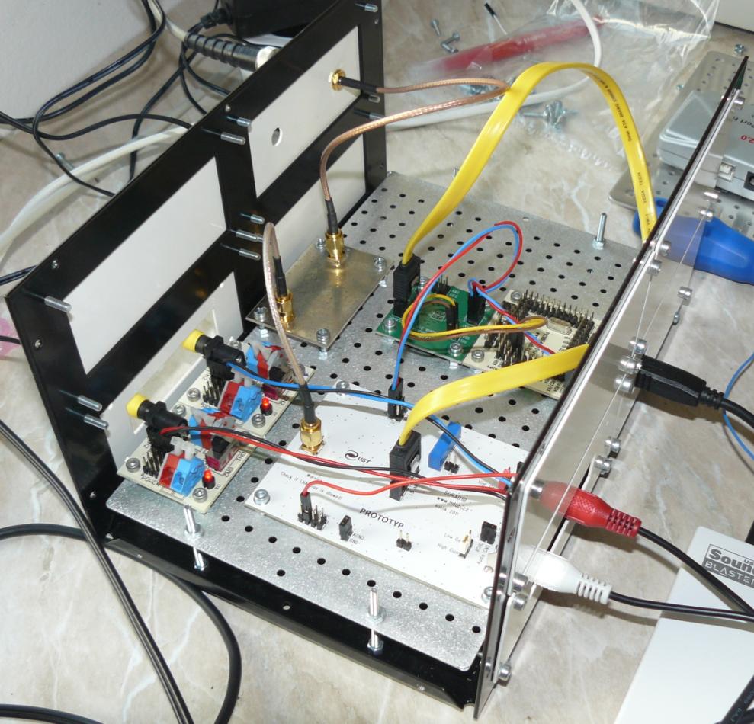
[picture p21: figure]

Také jste využili UNIBOX01? Podělte se s ostatními o Vaše zajímavá uplatnění.

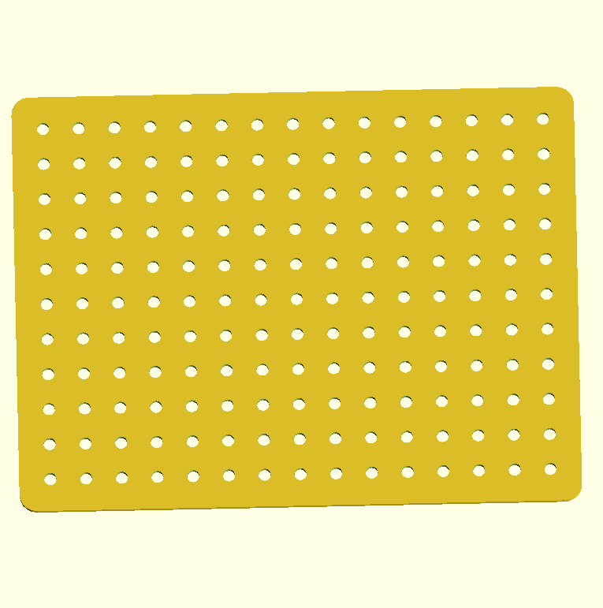
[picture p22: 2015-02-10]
mechanical/PLBASE1113/DOC/SRC/img/PLBASE1115_Top_Big.png

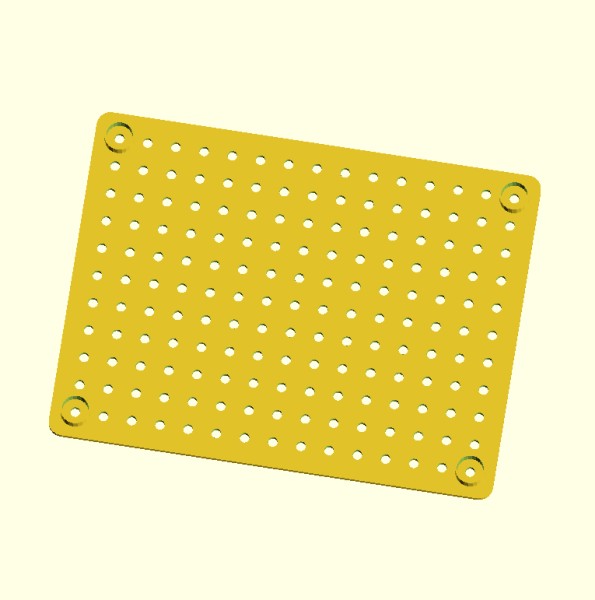
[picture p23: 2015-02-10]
mechanical/PLBASE1113/DOC/img/PLBASE1115_Bottom_Small.jpg

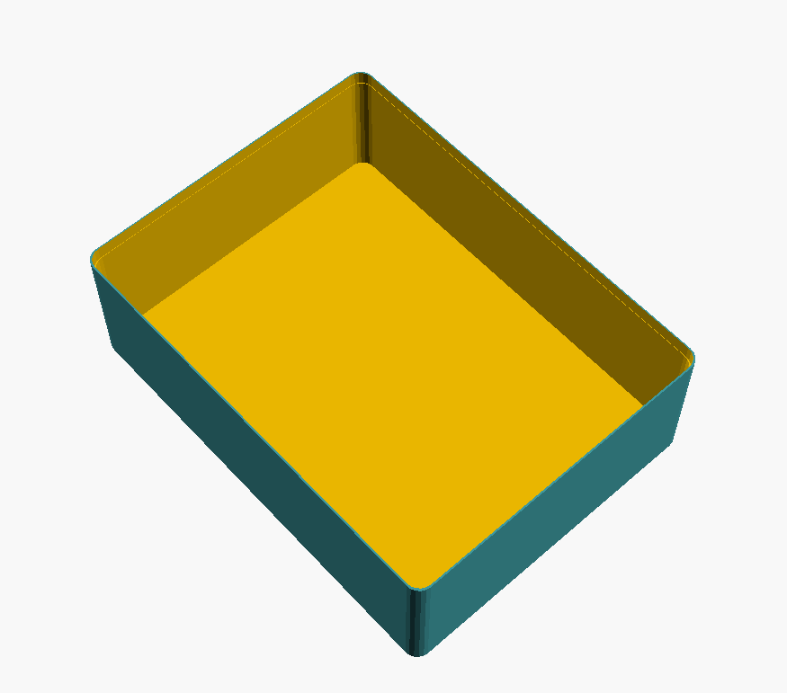
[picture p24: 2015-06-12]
mechanical/PLCASE1115/doc/img/PLCASE1115_big.png

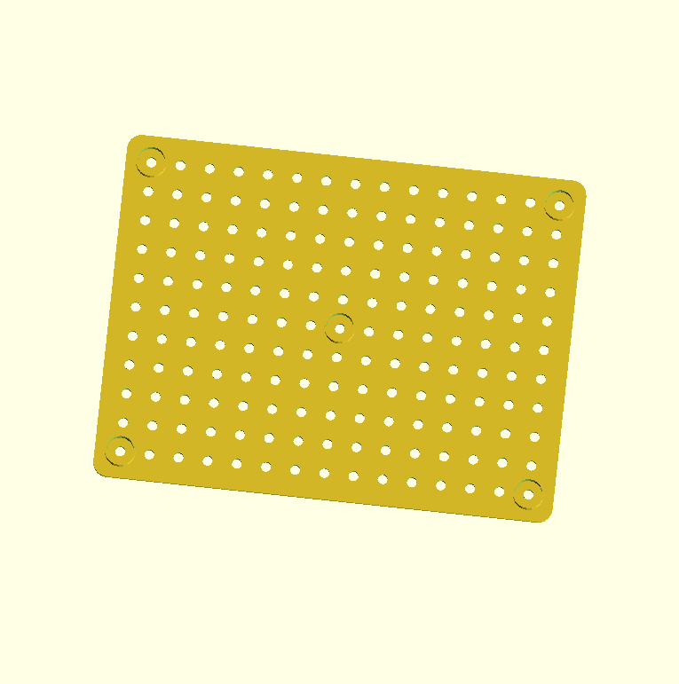
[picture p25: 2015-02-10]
mechanical/PLBASE1113/DOC/SRC/img/PLBASE1115_Bottom_Big.png

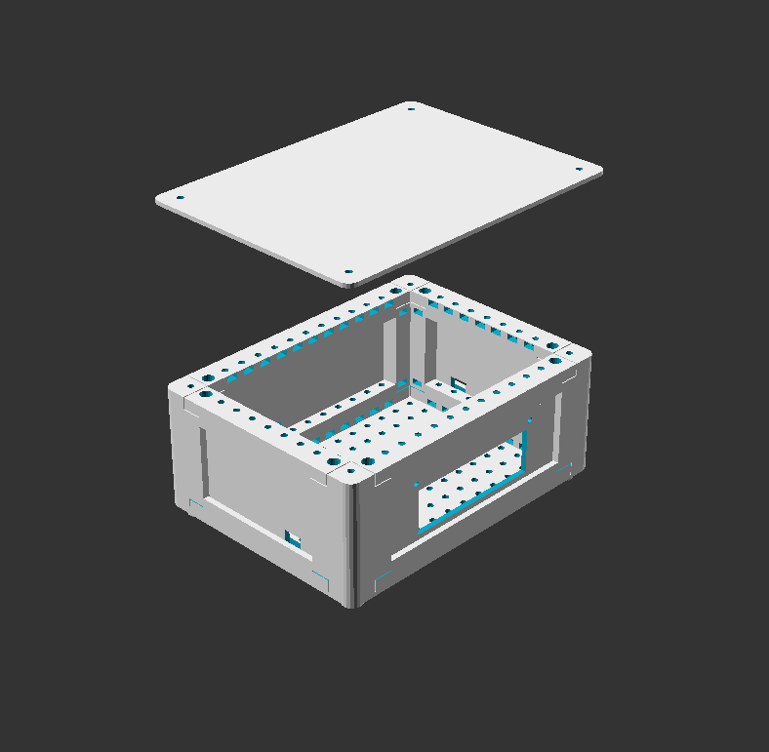
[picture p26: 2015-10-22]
mechanical/boxes/BASEBOX02A/doc/img/Box_view.png

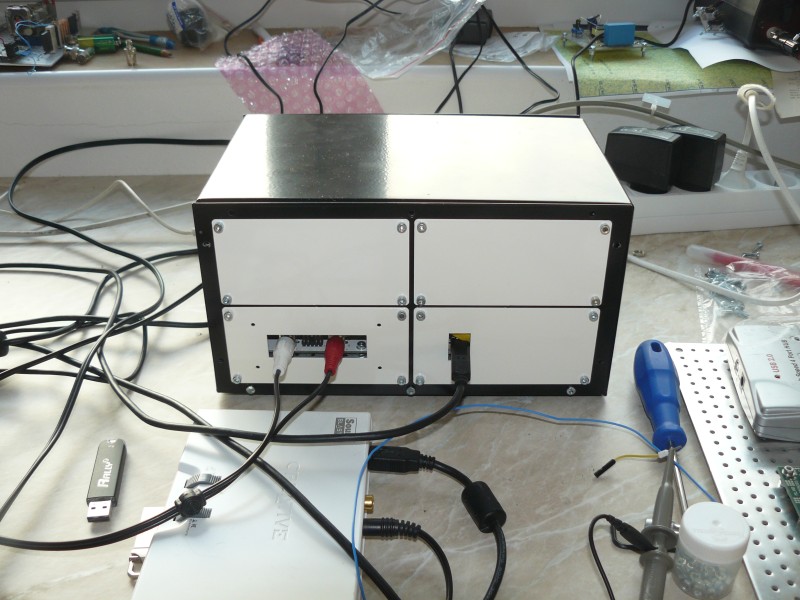
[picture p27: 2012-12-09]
mechanical/boxes/UNIBOX01A/doc/img/UNIBOX01A_small.jpg

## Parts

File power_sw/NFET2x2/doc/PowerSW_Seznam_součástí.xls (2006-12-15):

Power SW
Počet | Reference | Název | Pouzdro | Název GM | Obj. číslo GM | Cena zhruba | Popis
5 | D1 - D5 | 1N5818 | DO41 |  |  | co dům dá | Libovolná spínací nebo shottkiho dioda
1 | J1 | JUMP2X1 | JUMP2X1
1 | J2 | JUMP2X4 | JUMP2X4
4 | J3 - J6 | ARK210/2 | ARK210/2 |  |  | 2.5
2 | Q1, Q2 | SO8_2xNFET_9926 | SO8_2FET |  |  | 14 | Dvojitý NFET s nízkým threshodl (např CEM9926 nebo IRF7301)
4 | R1 - R4 | 47 | R0805
4 | M1 - M4 | HOLE_M3 | HOLE_M3 |  |  |  | Šroubky, podložky a matičky jako u každého modulu

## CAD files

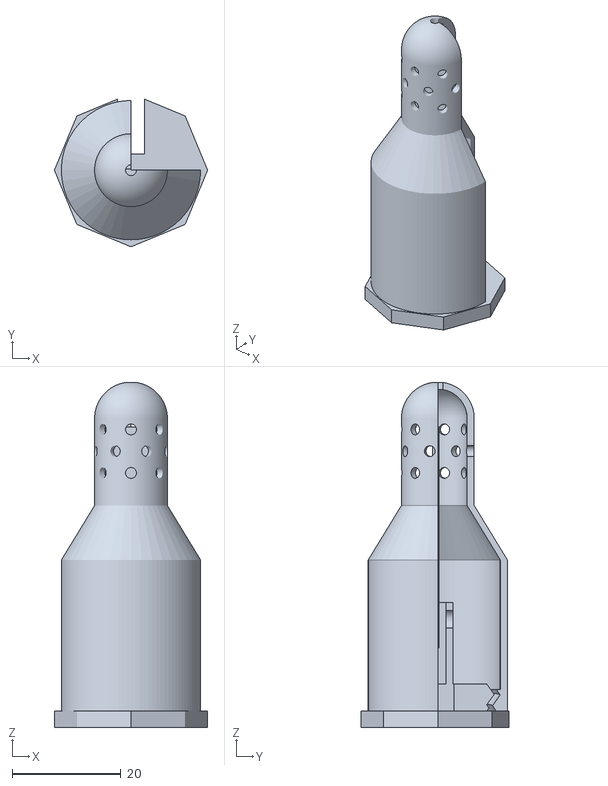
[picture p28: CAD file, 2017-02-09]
mechanical/boxes/SHTBOX01A/amf/SHTBOX01A_assembly.stl
28.2 x 27.2 x 63.5

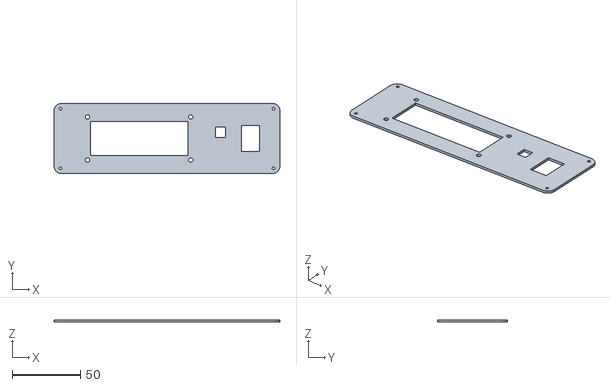
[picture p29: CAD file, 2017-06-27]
mechanical/boxes/UNIBOX03A/cad/print_data/assembly.stl
165.0 x 51.1 x 1.60

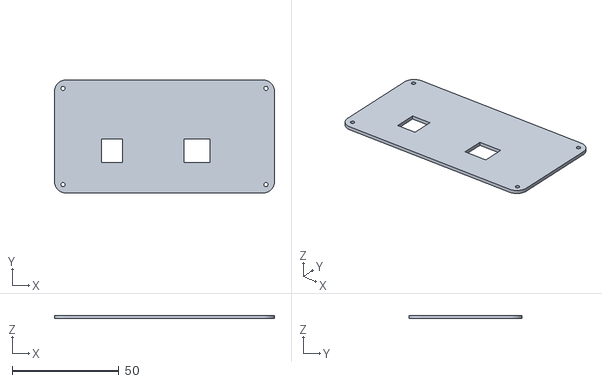
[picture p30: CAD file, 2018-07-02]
mechanical/boxes/UNIBOX04A/cad/print_data/assembly.stl
103.0 x 53.0 x 1.60

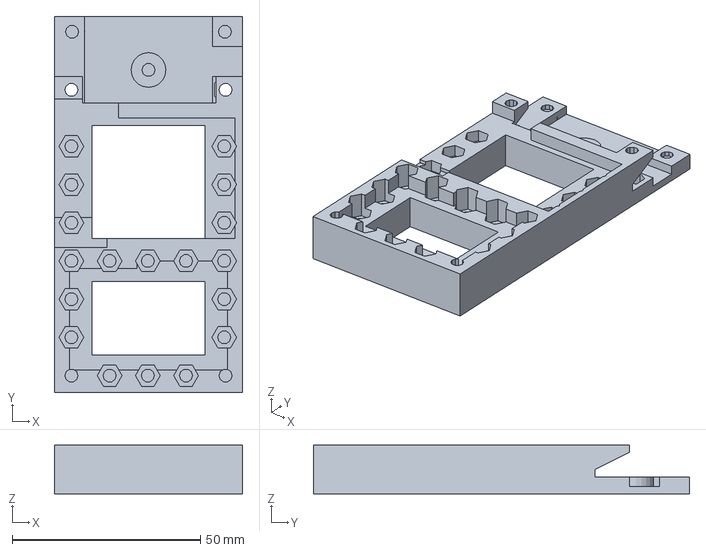
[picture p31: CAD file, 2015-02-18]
ARM/ODROID-U3/CAD/ODROID-U3_breakout_frame.amf
50.0 x 100.0 x 13.0 mm

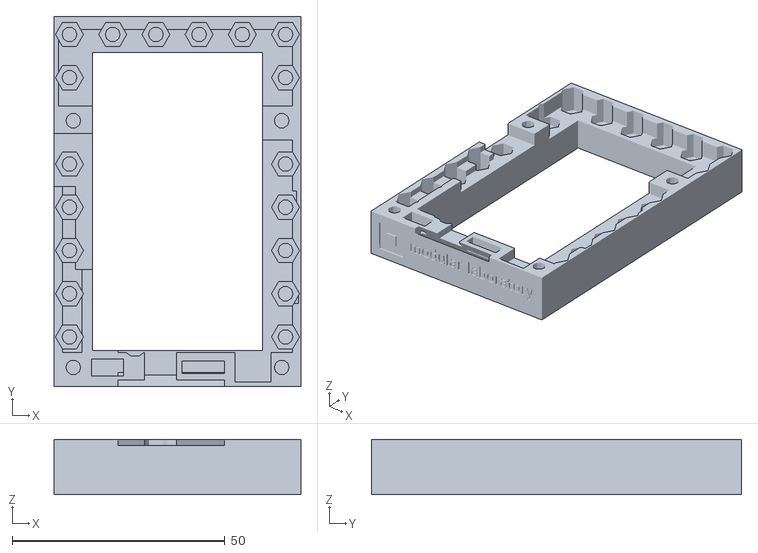
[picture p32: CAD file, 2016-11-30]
MCU_CPU/ARM/ODROID-C1/cad/ODROID-C1+_MLAB_breakout_frame.stl
58.0 x 87.0 x 13.0

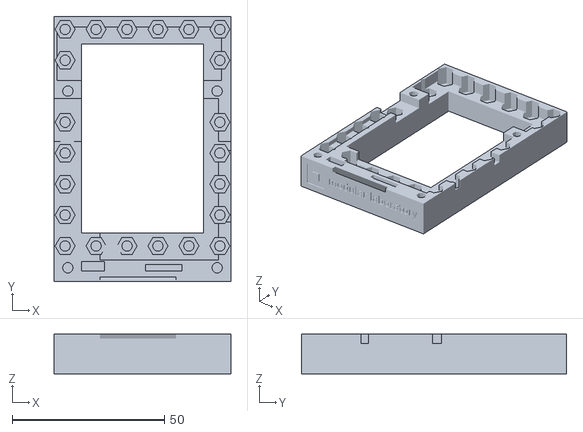
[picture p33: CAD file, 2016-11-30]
MCU_CPU/ARM/ODROID-C2/cad/ODROID-C2_MLAB_breakout_frame.stl
58.0 x 87.0 x 13.0

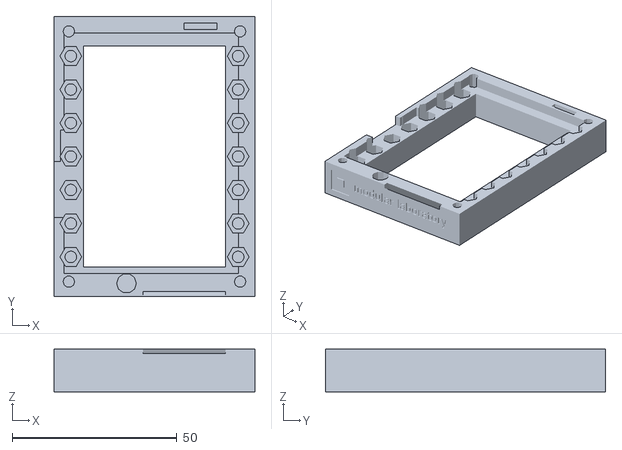
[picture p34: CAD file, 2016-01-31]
MCU_CPU/ARM/ODROID-XU4/cad/ODROID-XU4_MLAB_breakout_frame.stl
61.0 x 85.0 x 13.0

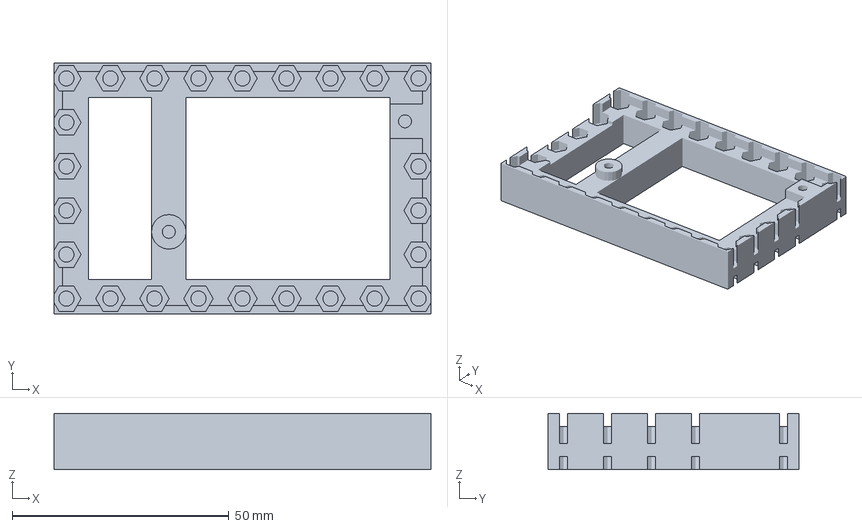
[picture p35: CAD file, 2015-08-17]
MCU_CPU/ARM/Raspberry/RPi/cad/RaspiAB_breakout_frame.amf
87.0 x 58.0 x 13.0 mm

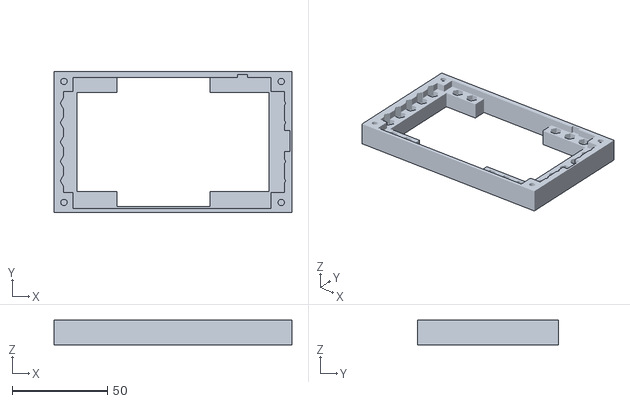
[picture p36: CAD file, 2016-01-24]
MCU_CPU/x86/Galileo/cad/Intel_Galileo_MLAB_breakout_frame.stl
125.0 x 74.0 x 13.0

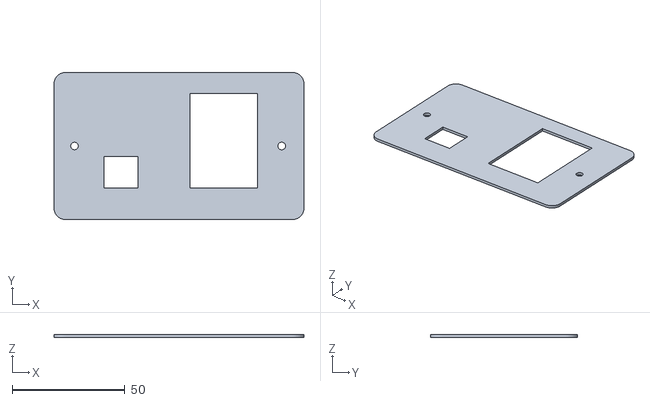
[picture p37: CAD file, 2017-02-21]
mechanical/boxes/AWSBOX01A/amf/AWSBOX01A_D04.stl
111.0 x 65.2 x 1.30

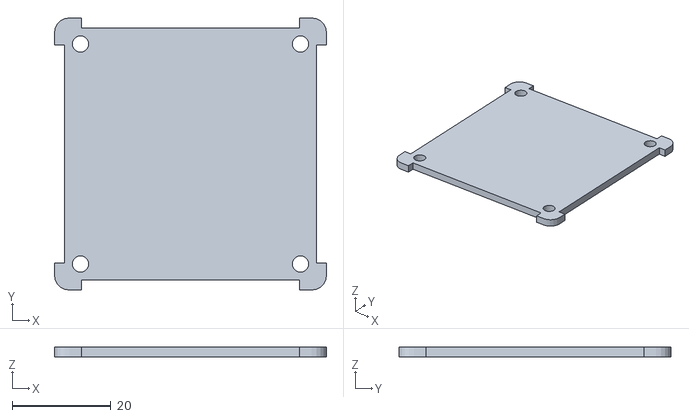
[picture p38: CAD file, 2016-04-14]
mechanical/boxes/BASEBOX02A/amf/BASEBOX02A_PLBASE_top.stl
55.2 x 55.2 x 2.00

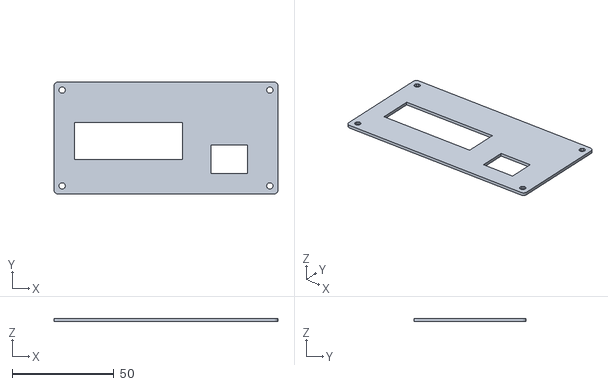
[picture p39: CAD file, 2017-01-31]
mechanical/boxes/UNIBOX01A/amf/small_panel.stl
110.0 x 55.0 x 1.50

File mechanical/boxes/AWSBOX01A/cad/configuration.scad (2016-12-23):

$fn=40; // model faces resolution.

//OBECNE PARAMETRY 
//----------------------------------------------------------------
//----------------------------------------------------------------

//pro PLBASE
pocet_der1=11; //x 11
pocet_der2=6; //ovlivňuje výšku krabičky 6
radidus_hrany=5;
vzdalenost_der=10.16;
vzdalenost_od_okraje=vzdalenost_der/2;
prumer_sroubu=3.4;
tloustka_plbase=2;
prekryti_der=-2;

//WINDGAUGE02A_D02 //uchyt na sloup
D02_sila_materialu=5; //nefunguje
D02_vyska_uchytky=40;
D02_prumer_obruby=27; //3/4 trubka
D02_delka_celeho_uchytu=60;
D02_dotahova_vzdalenost=1.5;
D02_prumer_uchytneho_sroubu=4.2;
D02_sirka_matky=9.2; //pro M4
D02_vyska_matky=3;




D02_vyska_boxu_pod_plbase=6;
D02_vyska_boxu_nad_plbase=50;
D02_zapusteni_spodniho_krytu=10;
D02_sila_materialu=1.2;
D02_dolerance_na_zasunuti=0.8; //tolerance je pro obě strany

drzak_sroubu_hloubka=15;
drzak_sroubu_vyska=10;
matka_vyska=3;

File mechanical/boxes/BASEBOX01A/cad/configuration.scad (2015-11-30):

//Název boxu (zařízení)
box_jmeno="BASEBOX01A";


//ALBASE1115
//------------------------------------------------------------
///*
vzdalenost_der = 10.16; //rozteč děr mezi sebou
radidus_hrany = 5; //radius zaobleni sloupku

//parametry lišty
vzdalenost_od_okraje = 8.88; //vzdalenost stredu upevnovaci diry od kraje desky

//mala hrana
pocet_der1 = 8; //pocet der desky, ponížené o 3

//velka hrana
pocet_der2 = 12; //pocet der desky, ponížené o 3
//*/


//OBECNE PARAMETRY KRABICKY
//------------------------------------------------------------
vyska = 60;  //vyska celeho sloupku, pro zjisteni celkove vysky krabicky je potreba k teto vysce pricist tloustku 2xALBASE, nebo 2xPLBASE

//PLBASE PARAMETRY
//------------------------------------------------------------
tloustka_plbase = 2; //tloustka plbase
prekryti_der=0.3; //sila materiálu, který překrývá díry

//PRIPADNA VYSKA NOZICEK
//------------------------------------------------------------
vyska_nozicky=5;

//Rozmery loga MLAB
//------------------------------------------------------------
logo_vyska=0.2;
logo_sirka=0.2;

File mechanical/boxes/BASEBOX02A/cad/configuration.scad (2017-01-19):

//Název boxu (zařízení)
box_jmeno="BASEBOX02A";

vzdalenost_der = 10.16; //rozteč děr mezi sebou
radidus_hrany = 3; //radius zaobleni sloupku
vzdalenost_od_okraje = 5.2; //vzdalenost stredu upevnovaci diry od kraje desky
pocet_der1 = 10; //pocet děr v ose y
pocet_der2 = 11; //pocet der v ose x



//OBECNE PARAMETRY KRABICKY
//------------------------------------------------------------
//BOCNICE
vyska_bocnice=40;
tloustka_bocnice=3;


//PLBASE PARAMETRY
//------------------------------------------------------------
tloustka_plbase = 2; //tloustka plbase - dna
prekryti_der=0.2; //sila materiálu, který překrývá díry, aby nebyli vidět

plbase_tolerance_horni=0.5; //pro zvětšení tolerance aby tam šlo dát  horní čelíčko


//Rozmery loga MLAB
//------------------------------------------------------------
logo_vyska=0.15;
logo_sirka=0.15;

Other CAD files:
MCU_CPU/ARM/ODROID-U3/cad/ODROID-U3_MLAB_breakout_frame.stl
MCU_CPU/ARM/Raspberry/RPi3/cad/Raspi3_breakout_frame.stl
mechanical/boxes/BASEBOX01A/cad/configuration/text/Letters.dxf
mechanical/boxes/BASEBOX02A/cad/src/text/Letters.dxf
mechanical/boxes/BASEBOX03A/cad/src/text/Letters.dxf
mechanical/boxes/UNIBOX01A/hw/cam_profi/UNIBOX01-MD.dxf
mechanical/boxes/BASEBOX03A/cad/configuration.scad
ARM/ODROID-U3/CAD/Board_support.amf
MCU_CPU/ARM/ODROID-C1/cad/ODROID-C1_MLAB_breakout_frame.amf
MCU_CPU/ARM/ODROID-C1/cad/src/ODROID-C1+_MLAB_breakout_frame.scad
MCU_CPU/ARM/ODROID-C1/cad/src/ODROID-C1_MLAB_breakout_frame.scad
MCU_CPU/ARM/ODROID-C2/cad/src/ODROID-C2_MLAB_breakout_frame.scad
MCU_CPU/ARM/ODROID-U3/cad/ODROID-U3_MLAB_breakout_frame.amf
MCU_CPU/ARM/ODROID-U3/cad/src/ODROID-U3_MLAB_breakout_frame.scad
MCU_CPU/ARM/ODROID-XU4/cad/src/ODROID-XU4_MLAB_breakout_frame.scad
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

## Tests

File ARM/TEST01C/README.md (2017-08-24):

<!--- PrjInfo ---> <!--- Please remove this line after manually editing --->
<!--- 00a56be08b96043df9e37d6aff7b6990 --->
<!--- Created:Time: ---> 
<!--- Author:Mlab: ---> 
<!--- AuthorEmail:mlab@mlab.cz: ---> 
<!--- Tags:imported: ---> 
<!--- Ust:None: ---> 
<!--- Label --->
<!--- ELabel ---> 
<!--- Name:module: --->
#module 
<!--- LongName --->
module description
<!--- ELongName ---> 

<!--- Lead --->
module lead text
<!--- ELead ---> 

LeadImg 

<!--- Description --->
<!--- EDescription --->
<!--- Content --->
<!--- EContent --->

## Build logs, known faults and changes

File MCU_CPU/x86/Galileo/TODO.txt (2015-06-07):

Na Breakout frame chybí dírka na provlečení kablíků pro wifi anténu. Stačí jen po obovdu (na okraji rámečku co přiléhá k desce Galiea) dát občas mezerku tak asi na 2mm x 4mm. Nejlíp 2x na delší straně a 1x na kratší. Ale snadno se to udělá i pilníkem (akorát že vrstvy se při pilování mají tendenci ulomit). Kablík má průměr cca 1.5mm (a jsou dva).

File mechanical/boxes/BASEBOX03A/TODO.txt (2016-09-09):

Ze statistiky 25 vytisknutych krabicek vyplyva, ze lidi tuhle krabicku nedovedou skladat. 
Je potreba, aby kapsy pro matky byly dostupne z delsi strany.  Jeden clovek i navrhoval matice strkat do kapes z vnejsi strany skrz stenu. 
To by byla mozna nejlepsi moznost, protoze by nedochazelo k vypadavani maticek pri montazi vicka. 

-dodělat zakritit dna
-nesimetrycké úchyty na dně
-lištičku na zadržení albase
-pridat ve spodu 1mm jako rezervu na sroubky

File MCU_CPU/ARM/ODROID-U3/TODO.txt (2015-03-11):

Zoptimalizovat tisk prevysu. (zmensit tloustku vrstvy)

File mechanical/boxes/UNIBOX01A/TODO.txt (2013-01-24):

Zakulatit rohy na UNIBOX01-FP (BP)  Duvod je, aby rohy neprecnivaly pres ohnute a kulate okraje. 

UNIBOX01-BH ma byt prohnuty a montazni diry maji byt podlouhle aby bylo mozne vyrovnat torelance vrtanych der. Zakulatit rohy, aby nebyly tak nachylne na poskozeni.. a nebezpecne pri zachazeni.. 

- Predni cela maji ve vetrikalni rovine vetsi mezeru, nez v horizontalni 

Promyslet pouziti narazecich matic. možná matice dát hlavně na namáhané závity.

Promyslet postup namontovani montazni desky a zavity ve spodnim krytu.
Montažní deska by mohla mít zahnuty lem misto použití distančnich sloupků.

Vady 1. serie:

- Na cernych dilech jsou stopy bile barvy
- Chybi zavity
- Na UNIBOX01-TC jseou male bocni diry pro srouby
- celo krabicky UNIBOX01-FP sedi s krytem UNIBOX01-TCpouze na 6ti sroubech z 10ti.  (bocni 4 nesedi)
- Tloustka barvy je nerovnomerna na cele plose krabicky (vevnitr je tlustsi vrstva, nez venku) coz je dusledek spatneho zaveseni pri nanaseni prasku. 
- celo UNIBOX01-FPAG je cerne a ne bile. 
- dil UNIBOX01-FP neni symetricky

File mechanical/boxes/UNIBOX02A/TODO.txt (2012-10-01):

Velikost 130x102X57mm

èela z velke krabicky uvazit moznost cela i z vrchu. 

Do krabicky dát 1/4 velke desky

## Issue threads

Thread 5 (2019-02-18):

Měřící modul napětí a proudu VCAI2C02A

kaklik, 2019-02-18:
Nový měřící modul by měl umožňovat měření proudů v rozsahu 0.1 až 50A a napětí do 50V.

Modul by měl vycházet z existujícího návrhu modulu [VCAI2C01A](http://www.mlab.cz/module/VCAI2C01A), ze kterého může převzít zvolený typ ADC, volbu OZ pro analogové vstupy.

Naopak by měl být rozšířen o [měřící transformátor](https://cz.mouser.com/ProductDetail/838-L01Z050S05) a umožňovat osazení, či použití více alternativních typů transformátorů.

Zapojení konektorů pro připojení I²C a volbu adresy by mělo zůstat zachováno.

kaklik, 2019-02-18:
Měřící vstup pro připojení měřeného napětí by mohl být realizován konektorem [XT-30](https://www.tme.eu/cz/details/xt30pw-m/konektory-dc/amass/).

Zároveň by bylo vhodné, aby měřené napětí nemělo společnou zem se zapojením modulu potažmo se zařízeními připojenými na modul. Z tohoto důvodu je potřeba na vstup použít [izolační zesilovač](https://www.analog.com/media/en/technical-documentation/data-sheets/ADuM3190.pdf) (příklad).

kaklik, 2019-02-18:
@ChroustJan  Nemáš už náhoudou pro THT variantu konektoru XT-30 nakreslený KiCAD footprint?

ChroustJan, 2019-02-19:
Nemám

kaklik, 2019-02-19:
Díky potřebě napájení oddělené části izolačního zesilovače z měřeného zdroje může být měřený rozsah napětí pouze cca 3 až 50V.
Tento limit by ale bylo možné vyřešit zavedením možnosti připojit izolovaný napájecí zdroj, jako je například baterie CR2032.

VCO34, 2019-02-19:
Ten měřící transformátor viz. link je pro 5V 15mA - Pro zjednodušení bude použito i 5V I2C ?, nebo tam bude i externí napájení ?

kaklik, 2019-02-19:
Pokud měřící trasformátor vyžaduje 5V napájení, tak je zřejmě potřeba, aby bylo použito 5V i²C. To je myslím omezení se kterým se dá vydržet.  Ten minulý modul [VCAI2C01A](http://www.mlab.cz/module/VCAI2C01A) to má v podstatě obdobně.
Pokud bude jedinná omezující součáska ten transformátor, tak možná pak někdy půjde najít měřící transformátor, který funguje i na 3.3V.  Teď to ale není potřeba.

kaklik, 2019-03-14:
Myslím,že by alespoň jeden adresní bit ADC měl být konfigurovatelný jumperem.
 - pull-up rezistory na I2C by bylo zřejmě lepší použít 10k, jednak jsou to pouze dva rezistory na PCB jiné hodnoty a potom je zbytečné na modulu mít tak tvrdé pull-upy, když pravděpodobně budou už i na ostatních modulech připojených na sběrnici
 - nejsem si jistý, jestli testpointy na vstupu ADC nejsou náhodou plýtvání místem
 - Měřící transformátor by u napájecího vstupu mohl mít blokovací kondenzátor, neboť má ratiometrický výstup a napájení ADC blokováno je.
 - chybí kondenzátor na Vreg2
 - Mám pochybnosti o tom, že odporový dělič na vstupu umožňuje měřit napětí i od nízkých hodnot. Neboť parametr Input Common-Mode Range začíná na 0.35V. Zřejmě je proto nutné vstupní napětí posunout pomocí VREf výstupu, jak to ostatně i provádějí ve Figure 34. DOSA Module datasheetu.
 - Podobné posunutí hodnoty napětí je zřejmě potřeba udělat i na výstupu, neboť output voltage range je 0.2 až 2.7  V.

kaklik, 2019-03-14:
Myslím si, že vstup ADC CH2- je třeba připojit k REFout výstupu, aby bylo možné využít celý rozsah ADC pro měření výstupního napětí.

EAout2 není potřeba zapojovat a ani k němu nemusí být přivedeny rezistory R7 a R21.

VCO34, 2019-03-15:
@kaklik zapracoval jsem upravy. je to na gitu. Přemýšlím zda má smysl tam mít ty dva vstupní děliče. také jsem tam přidal compensation network co mají v datasheetu

kaklik, 2019-03-15:
Dobře, aby se dalo zjistit, jestli tam ty dva měniče jsou potřeba by bylo vhodné zkusit udělat simulaci té odporové sítě.

VCO34, 2019-03-27:
Nějaké výhrady nápady ? všechny součástky krom LED jsou ze spodní strany

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

ChroustJan, 2019-03-28:
@VCO34 my dáváme LED standardně z druhé strany s tím, že se osadí opačně.  [Pro ilustraci je to vidět zde.](http://mlab.cz/module/LED01A)

Používáme [pouzdro 1206, toto](https://github.com/MLAB-project/kicad-mlab/blob/master/footprints/Mlab_D.pretty/LED_1206.kicad_mod)

VCO34, 2019-03-28:
@ChroustJan @kaklik  commitnul jsem DPS rev1, LED jsem upravil dle podmětu, doplnil popisky atd. Pokud nebude nic jiného můžeme pustit do výroby.

ChroustJan, 2019-03-28:
Koukal jsem na to:
-bylo by dobré doplnit přesnější typ tohoto IO ADUM3190 nebo je jedno která verze se tam dá? [Možnosti](https://cz.mouser.com/Analog-Devices-Inc/Isolation-Amplifiers/ADUM3190-Series/_/N-1yyh4l4Z4fs2kZ1yxyufm)

-tady také dovyplnit typ aby to bylo jasné [MCP3423](https://cz.mouser.com/Search/Refine?Keyword=MCP3423)

-Doplnit typ který budeme osazovat standardně L01ZxxxS05 a pak do schéma dát rozpis variant (stačí v textu), které je tam možné osadit a jaké to má parametry.

-byl nějaký důvod mít R a C v 0603? Protože mi máme spoustu hodnot v 0805:( v 0603 máme malé zásoby.

kaklik, 2019-03-28:
Já bych tam asi navrhoval standardně osazovat tu 100A verzi L01Z100S05.

Jinak ty přesné typy by měly být v poli MFPN, podle návodu tady: https://wiki.mlab.cz/doku.php?id=cs:tools&#schema_-_pojmenovani_soucastek

VCO34, 2019-03-29:
@kaklik  - měřící transformátor má pro všechny rozsahy stejné pouzdro - do pole MFPN přidána varianta 100A
@ChroustJan - ADUM - doplněn, MCP doplněno, transf. typ doplněn do MFPN
- 0603 - používám standardně na všem - jsou malé, levné a ještě dobře osaditelné
- po domluvě s Jakubem K. - nahrazeny 0805

nová verze v gitu

ChroustJan, 2019-04-08:
@VCO34  bylo by možné zařadit tento modul do máster větve? Provedl jsem kontrolu a vytvořil výrobní data.

VCO34, 2019-04-08:
hotovo

ChroustJan, 2019-04-14:
@VCO34 tento týden by měli přijít PCB:) Jen bych se chtěl zeptat, jak se stalo, že ten modul je jen přes 3šrouby? Jakub mi říkal, že jste byli domluvení na 4 šrouby. Nešel nám ten PCB pak složi s ostatními a musel se nechat vyrobit samostatně. V zásadě mi jde o zjištění, zda to byl záměr, nebo došlo ke špatnému pochopení, jak se daný rozměr počítá a bude potřeba návod vylepšit.

VCO34, 2019-04-15:
@ChroustJan @kaklik Hoj, nějak si nevybavuju, že bych to měl jako podmínku, každopádně je možné, že původně byl na 4 a já ho optimalizací z redukoval na 3. Co se týče rozteče děr, vycházím z toho co je na wiki a to 400mil a je jedno kolik děr zaberu. Pokud to tam je napsané tak jsem si toho nevšiml. Měl si se ozvat ještě před výrobou - upravil bych to.

ChroustJan, 2019-04-15:
@VCO vyhodnotili jsme to jako zbytečné, to upravovat a menší je lepší:)

ChroustJan, 2019-04-16:
@VCO34 mám problémy sehnat 40k a 17k nejsou nikde moc skladem. Není možné přepočtení na hodnoty které jde koupit? Ideálně v TME a Mouser.

VCO34, 2019-04-16:
@ChroustJan Hoj, to vypadlo ze simulace - jakou řadu máte ? zkusím to trochu pošolichat.

ChroustJan, 2019-04-16:
@VCO34  jde tam dát cokoliv, co je skladem tady:
https://www.tme.eu/cz/katalog/rezistory-smd-0805_100549/
https://cz.mouser.com/Passive-Components/Resistors/Film-Resistors/Thick-Film-Resistors-SMD/_/N-7gz42?P=1yzmou0

VCO34, 2019-04-18:
@ChroustJan Hoj, tak můžeme nahradit 40.2k a 16.9k (1%) vybíral jsem z E48

ChroustJan, 2019-04-24:
@VCO34  je potřeba dodělat PCB tak, aby si šlo vytisknout osazovací předpis. Tedy vrstvy F.Fab a B.Fab.

VCO34, 2019-04-24:
@ChroustJan  @kaklik  Máš to v masteru - jinak co takhle nějaký checklist před výrobou, který by všechny tyhle dodělávaky zkontroloval ? - já svoje plošnáky osazuju z F.silk nebo je osazuje automat - takže tyhle vrstvy standardně neupravuji. :)

ChroustJan, 2019-04-24:
Checklist aktuálně nemáme. Máme popis v [návodu.](https://wiki.mlab.cz/doku.php?id=cs:rules&s[]=navrhnout&s[]=modul#vrstvy)
Správně by mělo být v F.Silk a B.Silk jen to co se dá nechat vyrobit na PCB. F.Fab a B.Fab by měl sloužit pro dokumentaci. Aktuálně podle této vrstvy osazujeme, když to děláme ručně.

kaklik, 2019-04-29:
Jistá verze checklistu [existuje](https://wiki.mlab.cz/doku.php?id=cs:rules&s%5B%5D=navrhnout&s%5B%5D=modul#check_list_pred_vyrobou) je ve stejném návodu jako posílal @ChroustJan  na konci.

kaklik, 2019-04-29:
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

VCO34, 2019-04-29:
vypadá to dobře - už jste zkoušeli funkčnost ?

kaklik, 2019-04-29:
@VCO34  To čeká na tebe. :D

VCO34, 2019-08-01:
Oki, myslím, že se nám podařilo najít lepší variantu zapojení pro měření napětí na tomto modulu. Zenerovu diodu vyměníme za stabilizátor S1142D500I-E6T1U. Ověřil jsem s ním zapojení a funguje skvěle.

Minimální napětí na vstupu je 3,3V == 0,396V na výstupu izolačního zesilovače.
Pro 50V == 1,404V.
Teplota stabilizátoru při 50V a cca 5min provozu 42,4°C okolí cca 25°C.

Rozdíl vstupu a výstupu isolačního zesilovače je cca 1mV

kaklik, 2020-02-18:
@VCO34  jaké úpravy jsou potřeba, aby se se současnou verzí modulu dalo měřit?
Existuje nějaký fungující?

VCO34, 2020-02-18:
Hoj, bylo třeba vyřešit napájení pro izolační zesilovač, zenerova dioda nefungovala dobře, což jsme vybrali a vyzkoušeli, že funguje jeden z LDO obvodů. též nám tam chyběl 1uF kondík na Vdd2. Ale stejně napětový vstup nefungoval dle tvých představ, já nenašel na tvoje požadavky řešení. Proudová větev fungovala dobře hned, upravil se akorát vstupní dělič na 18k 0,1%
Takže mám tu 4moduly originál, ztoho jeden experimentální na kterém jsem dělal pokusy.

kaklik, 2020-02-18:
Dobře a chystáš se na tom nějak pokračovat?

VCO34, 2020-02-19:
Zásadně nechystám, protože nemám řešení k tvým požadavkům a také jste ho do teď nepotřebovali :)

kaklik, 2020-02-19:
Dobře a mohl by jsi prosím nějak zdokumentovat tu aktuální nejlepší funkčnost, které se podařilo dosáhnout?

VCO34, 2020-02-19:
však píšu výše, čeho jsem dosáhl a co je třeba dořešit, opravit. Zbytek jsou poznámky ve schématu. Více k tomu nemám. Jo vlastně ještě jsem měřil linearitu, tenkrát jsem ti ji posílal do chatu, ale chápu, že to je ztraceno :). Ted bude celkem kumšt to pullnout do gitu. Poslední verzi mám samozřejmě u sebe.

roman-dvorak, 2023-07-05:
Ahoj, lze tohle issue prosím nějak dovyřešit?

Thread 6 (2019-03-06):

COILSW01A

kaklik, 2019-03-06:
- V potisku chybí označení napájecích svorek a svorek pro připojení cívky
- Je nešikovné, že ovládací hřebínek nedodržuje konvenci a nemá dvojitý pin pro EN a dvojitý pin pro GND.

VCO34, 2019-10-11:
Hodnoty součástek neodpovídají popisu ve schématu "Rpeak a Rhold for 3A". Hodnota Rsense je příliš malá. Hodnota Rpeak a Rhold jsou na max - což znamená nejmenší možný reakční a hold proud. Viz. datasheet.

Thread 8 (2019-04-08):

Držák kabelů k desce ALBASE

kaklik, 2019-04-08:
Je potřeba tištěný díl pro uchycení kabelů různých průměrů na desce ALBASE.  Jeho účelem je umožňit připojení tlustých špatně ohebných kabelů k modulům MLAB.

Typické využití takového vývodu je u měřících stanic této konstrukce:

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

Kde vlevé části obrázku vede tlustý kabel s průměrem 10mm, který by měl být přichycený k základní desce před tím, než bude připojen k modulu.

Konstrukce držáku může vycházet z [existujícího modelu](https://github.com/ThunderFly-aerospace/TF-R1/blob/master/CAD/src/cable_clamp.scad) pro uchycení kabelů ke startovací desce.
Využití tohoto modelu je výhodné, neboť již řeší parametričnost počtu kabelů a jejich průměrů.

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

Je pouze nutné tento úchyt upravit tak, aby jej bylo možné přišroubovat na tento okraj [modulární desky ALBASE](https://github.com/MLAB-project/Modules/blob/master/mechanical/ALBASE1521/hw/cam_ama/ALBASE1521.pdf):

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

Model by měl být umístěn ve složce desky, ke které má pasovat.
https://github.com/MLAB-project/Modules/tree/master/mechanical/ALBASE1521/hw

roman-dvorak, 2019-06-17:
Držák by měl fungovat tak, že se definuje vzdálenost a průměr připevňovacích šrubů.

Jednotlivé vodiče budou definovány polem, který bude obsahovat pole s průměry jednotlivých vodičů. Skupina vodičů bude následně pod jedním protikusem přidělaným pomocí dvou šroubů ve správném rastru.

Definice pak bude moct vypadat následovně:
```
wires = [[10, 10, 10, 5]];   // 4 vodiče pod jedním protikusem
wires = [[10, 10], [5, 4, 4]]; // 2 protikusy. První bude držet dvojici 10 mm kabelů. Další bude mít 3 tečí kabely
wires = [[10], [5], [5], [3]]; // 4 kabely. Každý bude samostatně připevněný.
```

Vygenerovaný STL soubor musí obsahovat základní díl, tak i všechny příchytky vedle sebe. Tak, aby to bylo možné vytisknout vše najednou.

Příchytky musí být možné generovat samostatně - to samé platí o základním dílu.

JakubMares96, 2019-06-28:
Ahoj, mám dotaz, jaké šrouby se použijí pro připojování jednotlivých kabelových modulů? Budou to šrouby M3 se šestihrannou hlavou a čtvercovou matičkou? Pro připojení k desce ALBASE bude M3 s válcovou hlavou a šestihrannou matkou?

Zde je pracovní verze s těmito parametry wires =  [[2,8,5],[5,20],[10,10]];
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

kaklik, 2019-06-28:
Mě přijde rozumné tam všude používat stený typ šroubů tj. M3  DIN 912 - válcová inbus hlava.

JakubMares96, 2019-07-01:
@kaklik @ChroustJan
Zde je nejaktuálnější podoba.
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

Closed 2019-08-02.

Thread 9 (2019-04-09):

Distanční sloupek pro desku ALBASE

kaklik, 2019-04-09:
V některých aplikacích je vhodná montáž více desek ALBASE nad sebe.
Příkladem jsou [detekční stanice sítě Bolidozor](https://github.com/bolidozor/RMDS).

V současné době jsou desky spojovány použitím závitových tyčí M5 řezaných na délku 120mm.
Každá deska je pak na závitovou tyč uchycena dvojicí matic a podložek.
Toto řešení je však výrobně nepraktické, neboť vyžaduje precizní začištění každého řezu závitové tyče, aby bylo možné matici na závit nasadit.

Zlepšením může být použití 3D tištěného sloupku. Do kterého se vloží klasické šestihranné matice M5 a desky se připevní šrouby.

Podoba sloupku by zřejmě měla, taková jak je na následujícím obrázku.

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

Zde je šestihranný sloupek, který má průměr na 13 klíč pro podržení při šroubování.  Uprostřed sloupku je šestihranná dutina, která je symetricky na dvou stranách otevřena.
Sloupek je konstruován tak, aby umožnil tisk jak na stojato, tak i při položení na otevřenou stranu ještiúhelníku.

Pro tisk na stojato jsou konce do kterých pasují matky opatřeny šikmým náběhem, aby nedocházelo k tisku vodorovného převisu. Strop kapsy na matku je navíc zaslepen jednou vrstvou materiálu, aby před tiskem díry byl nejdřív otvor pro matku zaslepen mostem.
Jedna vrstva materiálu v díře pro šroub se propíche šroubem během montáže.

Otvor na matici musí být mírně kónický, aby matice neměla tendenci vypadnout při vyšroubování šroubu.

Délka sloupku bude hlavním parametrem modelu.

ChroustJan, 2019-04-12:
@kaklik neměla by ta kapsa na matku být z boku? Tak jak to děláme u krabiček? Podle mě se tam bude pěkně blbě vkládat a bude nám vypadávat při montáži. Případně je to potřeba více rozkreslit. Není to úplně jasné:(

JakubMares96, 2019-05-28:
Po schůzce s @kaklik jsem udělal návrh distančního sloupku #9, viz:
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
Mohl bych poprosit o radu kam a pod jakým názvem to nahrát na git?
Prosím o názor a připomínky.

kaklik, 2019-05-29:
Patří to do [tohoto souboru](https://github.com/MLAB-project/Modules/blob/master/mechanical/ALBASE1521/cad/src/888_1001.scad).

Kóty se dají vytvářet i v modelech openscadu, je zbytečné kreslit nákres v jiném nástroji. http://www.cannymachines.com/entries/9/openscad_dimensioned_drawings

kaklik, 2019-05-29:
Taky by se hodilo odebrat zbytečný materiál ve vnitřní části sloupku.  Zde může být odečten klidně šestihran odpovídající minimálně průměru matice.
Prosté odečtení ale způsobí že matice bude bez šroubu zapadávat do sloupku, což je nežádoucí stav.

kaklik, 2021-11-12:
Vyřešeno hliníkovými distančními sloupky.

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

Closed 2021-11-12.

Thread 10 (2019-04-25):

WINDGAUGE03A - Tolerance rozměrů krytu

kaklik, 2019-04-25:
Draft verze kapkovitého krytu se vytiskne v pořádku.

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

Plošný spoj pohodlně pasuje do krytu

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

Kapkovitý kryt, ale nejde nasadit na spodní část

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

JanKott, 2019-04-26:
Opravil jsem přičítání parametru R03_global_clearance tak, že se přičítá jen do výřezu ve víčku, nikoliv všude kde se počítá s velikostí PCB dílů. Aktuálně to příčítá jen k šířce a výšce PCB. Hloubku jsem zatim nepřidával, protože tam nesedí plastové díly na sebe a navíc předpokládám že by dotažením šroubů mělo dojít k přitažení senzoru na tesnící kroužky.

_______________________________________________________________

commit 28204a6e2ed4a827844ff4992fe4bf1a81f965cc (HEAD -> master, origin/master, origin/HEAD)
Author: Jan Kott <jan.kott.88@gmail.com>
Date:   Thu Apr 25 20:51:42 2019 +0200

    WINDGAUGE03A #10 - Printing tolerance is now added only in the lid cut-out, not on tube platform. Lid cut-out cube size doubled.

kaklik, 2019-04-26:
Ok, vidím, že ta oprava ovlivnila oba díly, jak R03 tak i R04.  To víčko můžu přetisknout hned, protože jeho jemnou variantu ještě vytištěnou nemám. Ale s dílem R03 asi počkám, až bude opraveno víc komplikací.

JanKott, 2019-04-26:
R04 bude ale sedět až se přetiskne R03, protože se ve skutečnosti zmenšila plošina na R03 a R04 zůstala stejná. Mělo by to ale teď jít tisknout ve vyšší kvalitě.
Naíc budu ještě měnit R04 v rámci issue #13 kde vyměnim závity za válce.

kaklik, 2019-05-04:
Aktuální verze krytu po přišroubování při vloženém PCB nedoléhá na spodní část modelu. Důvodem je nízká hloubka otvoru vzhledem k tloušťce PCB. Navíc při tisku dochází k "propadnutí" stropu, které dále snižuje prostor pro PCB.
Na aktuálně vytištěném modelu je po datažení šroubů mezera pod krytem ~ 0.75mm

Closed 2019-09-03.

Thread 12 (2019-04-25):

WINDGAUGE03A - Poloha těžiště

kaklik, 2019-04-25:
K tomu, aby se anemometr mohl volně otáčet je potřeba, aby těžiště bylo přímo nad osou rotace slip-ringu.

Tak jak je naznačeno na tomto obrázku:
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

Aktuálně je příliš těžká zadní část s gridfiny.

Řešením by mohlo být vytvoření kapsy na spodním okraji přední části, do které se vloží závaží.

Potřebný rozsah závaží je přibližně vidět z této fotografie:
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

JanKott, 2019-04-28:
Nerozumim přesně jak si tu kapsu představuješ. Můzeš mi sem prosím přidet nějaký nákres?

kaklik, 2019-04-28:
Ta kapsa by měla být otvor v místě toho obdélníku a měla by pokračovat dovnitř modelu.

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

Cílem je, aby se do kapsy dala vložit takováto závaží.

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

JanKott, 2019-05-03:
Přidal jsem díru pro závaží. Šířka a výška se dají upravit parametry R03_balance_shelf_width a R03_balance_shelf_height. Hloubka je vždy maximální možná.

JanKott, 2020-04-07:
Hele co mi to tu zavíráš, kam si to teď commitnu? :-P

JanKott, 2020-04-07:
Po vyvážení rotačních částí je výsledek tento:
('Assembly COG is:', 0.0, -0.2, 197.63)
('Desired  COG is:', 0, 0, 198)

kaklik, 2020-04-15:
Další pokračování tohoto issue zřejmě je automatické vyvážení.

JanKott, 2020-04-16:
[https://github.com/mlab-modules/WINDGAUGE03/commit/849317cc40f68245581605f89a428111d993d3f9](url)

JanKott, 2020-04-17:
Pro účely anemometru to, zdá se, slouží. Otázka je, jestli to má smysl dál vyvíjet kvuli jiným projektům? Pokud jsou řádově komplikovanější, tak je možné, že to vůbe použít nepůjde.

Prosím @kaklik podívej se na to a napiš jak chceš abych pokračoval.

kaklik, 2020-04-21:
Zkoušel jsem to spustit a dostal jsem tohle:

```
git/MLAB/WINDGAUGE03/cad$ make
# Update dependencies and make no-draft version of model in AMF.
openscad -D "draft = false" -m make -o ../amf/WINDGAUGE_S04.amf -d  ./dep/WINDGAUGE_S04.deps src/WINDGAUGE_S04.scad
# Remove absolute paths in dependencies.
sed -i "s|/media/kaklik/91d64ab1-13dc-4023-87e9-e53e8433a489/git/MLAB/WINDGAUGE03/cad/||"  ./dep/WINDGAUGE_S04.deps
# Sort deps file to keep git changes to minimum.
sort -bf  ./dep/WINDGAUGE_S04.deps -o  ./dep/WINDGAUGE_S04.deps
sed -i 's|[^\]$|& \\|'  ./dep/WINDGAUGE_S04.deps
# Add modifiers to AMF files.
./merge_modifiers.sh -v -a ../amf/WINDGAUGE_S04.amf -s src/WINDGAUGE_S04.scad
./merge_modifiers.sh: 18: ./merge_modifiers.sh: function: not found
./merge_modifiers.sh: 21: ./merge_modifiers.sh: Bad substitution
Makefile:29: recipe for target '../amf/WINDGAUGE_S04.amf' failed
make: *** [../amf/WINDGAUGE_S04.amf] Error 2
/git/MLAB/WINDGAUGE03/cad$
```

Vzhledem k tomu, že make spouštím ze stejné složky, ve které je skript 'merge_modifiers.sh', tak se mi během několika minut nepodařilo zjistit, kde je problém.

```
$ ls -la
total 56
drwxr-xr-x 4 kaklik kaklik 4096 dub 22 00:33 .
drwxr-xr-x 7 kaklik kaklik 4096 dub 19 22:03 ..
-rw-r--r-- 1 kaklik kaklik 4039 dub 18 21:11 assembly.scad
-rw-r--r-- 1 kaklik kaklik 6931 dub 15 16:34 configuration.scad
drwxr-xr-x 2 kaklik kaklik 4096 dub 22 00:33 dep
-rwxr-xr-x 1 kaklik kaklik 9575 dub 18 21:11 get_cog.py
-rw-r--r-- 1 kaklik kaklik 2356 dub 22 00:33 Makefile
-rwxr-xr-x 1 kaklik kaklik 9347 dub 18 21:11 merge_modifiers.sh
drwxr-xr-x 3 kaklik kaklik 4096 dub 15 16:34 src
/git/MLAB/WINDGAUGE03/cad$
```

kaklik, 2020-05-18:
Podle Yagv je otočný díl anemometru zřejmě vyvážený.

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

Po prozkoumání gkódu se však ukazuje, že vyvažovátko vůbec nešetří materiálem. Osa Y je tak v podstatě vyvážena modifikátorem Z.
Ovšem díky tomu, že modifikátor Z je podstatně blíže osy rotace, tak jeho hmota musí být podstatně větší, než kdyby stejná nerovnováha byla vyvážena modifikátorem Y.

Tato skutečnost tak vede k neefektivnímu využití materiálu.

Řešením by zřejmě bylo modifikátor Z buď zrušit, nebo vzhledem k jeho nízké účinnosti na vyvážení Z mu přidělit pouze minimální prioritu.

kaklik, 2020-05-18:
Napadlo mě, jak zvýšit účinnost Z modifikátoru a provedl jsem úpravu jeho polohy a rozměrů.  Takto upravený modifikátor by snad neměl přispívat k vyvážení v ose Y. Tím pádem by tiskový materiál mohl být využit efektivněji.

Closed 2020-05-31.

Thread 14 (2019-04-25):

WINDGAUGE03A - Těsnění přívodů vzduchu

kaklik, 2019-04-25:
Vývody vzduchu ke snímači je potřeba upravit tak, aby konec kónického tvaru obsahoval zub proti kterému se zmáčkne okroužek nasazený na snímač.

Na snímači budou nasazené kroužky rozměru 1.5x1 mm

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

Tyto kroužky by měly zapadnout do zapuštění o tomto tvaru. (nakreslena jedna ze dvou trubic)

Snímač se v důsledku převrácení fotografie zasouvá ze spodní strany - do díry, která má pravoúhlé stěny. Obě díry jsou válcové.

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

JanKott, 2019-05-01:
Upravil jsem díry pro senzory. Díra pro senzory má teď průměr 3.5mm (parametr R03_sensor_diameter) a hloubku 2.5mm (parametr R03_sensor_depth) přechod do vzduchové trubice má 1.5mm (parametr R03_sealing_ring_thickness) a postupně se rozšiřuje na šířku vzduchové trubice (R03_air_tube_diameter).

kaklik, 2019-05-07:
Gumové o-koužky rozmeru 1.5x1 mm doléhají a jsou stlačovány při dotažení PCB.

Closed 2019-05-07.

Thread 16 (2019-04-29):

WINDGAUGE03A - Magnetická varianta montáže

kaklik, 2019-04-29:
Nejspodnější díl nohy by bylo vhodné upravit tak, aby umožňoval montáž na střechu auta magnety zasazenými v otvorech modelu.

Magnety by měly být tři symetricky na okolo středu. Do vytištěného modelu se budou vkládat z vrchní strany. Aby mezi kovovou střechou a magnetem bylo několik vytištěných vstev.  Vytištěné vrstvy by měly snížit riziko pošklábání laku kovovými díly.

ChroustJan, 2019-04-30:
@kaklik  bylo by dobré počítat s tím, že mezi střechu a tištěný díl bude muset přijít nějaká látka (filc). Ty laky se strašně snadno poškrábou.

kaklik, 2019-04-30:
V takovém případě je možná dobré tam spíš použít magnet se šroubem.
https://www.unimagnet.cz/659-HS-13-magneticky-uchyt.html

Důsledkem bude, že magnet bude mít lépe uzavřené magnetické pole. Ale zas může být našroubovaný zespodu. Takže mezi střechou a magnetem bude jen vrstva filcu.

ChroustJan, 2019-04-30:
To by bylo dobré. Ideální by bylo, kdyby ten magnet měl průměr jako samolepící filc pod židle:
https://www.hornbach.cz/shop/Plstena-podlozka-pod-nabytek-Tesa-samolepici-16x/7653785/artikl.html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

kaklik, 2019-05-04:
@ChroustJan  Tohle má úplně zanedbatelný průměr.  Filcovou podložku budeme muset vystřihnout, protože by zřejmě měla být přes celou plochu toho spodního držáku. Tedy přes celou spodní stranu tohoto dílu:
https://github.com/MLAB-project/Modules/blob/master/mechanical/WINDGAUGE03A/amf/P_WINDGAUGE03A_D02.stl

kaklik, 2019-05-04:
[Magnetické úhychy M5](https://www.unimagnet.cz/659-HS-13-magneticky-uchyt.html) by měly být v trojúhelníku okolo středového šroubu (který se bude do dílu montovat pouze v případě fixního uchycení, nebo uchycení na nemagnetický materiál).

Středový šroub M6 by měl mít šestihranné zapuštění pro hlavu, aby jej při dotahování nebylo potřeba džet klíčem.

Matice M5 šroubů od magnetů by měly být taktéž částečně zapuštěny.  Magnety ze spodní strany budou zapuštěny úplně a do modelu se zašroubují tak, že budou namagnetovány na tyčku, nebo hlavu roubu, se kterou se bude otáček pro dotažení do zapuštěné matice.

Výsledné konstrukční řešení je zachyceno na následujícím obrázku:

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

JanKott, 2019-05-05:
1) Jsem přepsal názvy proměnných do angličtiny a trochu jsem upravil odsazení v kódu. Původní proměnné jsem v souboru configuration.scad zachoval s odkazem na nové, kvůli případné kompatibilitě.
2) Zapuštění středové matice jsem přesunul na opačnou (vnitřní) stranu základny.
3) Přidal jsem díry na magnety HS-13 M5 na spodní část s extra rezervou 1.5 x D02_global_clearance kvůli tisku do vzduchu + díry na šroub M5 a kapsy pro zapuštění matek (do půlky jejich výšky) do vnitřní strany základny.

kaklik, 2019-05-07:
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

Ve vytitštěném dílu nevychází tolerance otvoru pro magnet a magnet tam nejde zasunout.

Otvor pro magnet by se hodilo překrýt jednou tištěnou vrstvou materiálu, která se pak po vytištění modelu propíchne. Podstatně to zlepší kvalitu výtisku.  K tomuto účelu je využíván [tento parametr](https://github.com/ThunderFly-aerospace/TF-R1/blob/c42b452ed2c369f34fbee3830a4b5310c39054a7/CAD/parameters.scad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).

kaklik, 2019-05-07:
Asi by taktéž bylo zlepšení, kdyby magnety byly umístěny na větším poloměru.  Podstavec by pak byl stabilnější.

JanKott, 2019-05-07:
Přidal jsem toleranci global_clearance k průměru základny magnetu. Přidal jsem tenkou vrstvu layer_thickness nad základnu magnetu pro zlepšení tisku. Díry na magnet jsem dal co nejblíže k okraji základny tak, aby tam stále šly umístit matky shora.

kaklik, 2019-06-05:
Tolerance otvorů i rozmístění magnetů nyní vyhovuje.

Closed 2019-06-05.

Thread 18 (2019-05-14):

Standardizace metod pro renderování OpenSCAD modelů

kaklik, 2019-05-14:
- Modely je potřeba umět přegenerovávat pomocí Makefile na základě změn na sobě závislých souborů
- STL bude primárně využíváno pro náhledy modelů  (github má pro STL integrovánu relativně kvalitní prohlížečku)
- Vypadá to, že není schůdné slučovat tiskový soubor s modelovým souborem, protože  na tiskový soubor a na zdrojový soubor modelu jsou různé požadavky. (tato záležitost se týká hlavně metadat a tvorby sestav)
- Obrázkové náhledy by bylo lepší generovat z již vygenerovaných tiskových souborů, aby nedocházelo k vícenásobnému renderování
- Soubor sestavy může být složen z vyrenderovaných tiskových souborů, aby se tak podstatně zkrátil čas renderování sestavy.

JanKott, 2019-05-15:
TLDR:
1) Upravil jsem makefile aby generoval jen PRINT (noDRAFT) verze a respektoval závislosti.
2) Soubory bez prefixu P_ jsem nahradil soubory s prefixem P_ a ty pak smazal (takže už jsou jen ty bez prefixu v plném rozlišení)
3) Obrázkové náhledy se generují přímo z již vygenerovaných modelů.
4) Soubor sestavy se skládá přímo z vygenerovaných modelů, ale bude zřejmě třeba to ještě odladit. Aktuálně mi po vyrenderování některé části zmizí a mám problém udělat výřez do modelu.
__________________________________________________________________________________________________________

Long story:
1) Upravil jsem makefile tak, aby respektoval změny v závilsých souborech. Make sám neumí dohledat závislosti, ale většina překladačů toto umožňuje. OpenSCAD není výjimkou, používá se pro to atribut -d. Tímto způsobem jsem tedy nechal vygenerovat soubory se závislostmi pro každý generovaný zdrojový soubor (soubory .deps v nové složce dep). Ty se následně includují v Makefile.
Jako zdroj informací jsem použil https://www.gnu.org/software/make/manual/make.html

2 + 3) Soubory, které se dříve generovaly s prefixem P_ se nyní generují bez prefixu. Všechny zdrojové soubory obsahují parametr draft nastavený na true. V tomto režimu se renderují v nízkém rozlišení (aktuálně nastavuju fn = 20, nahrazuju screw za cylinder a curvedPipe nepoužívám pro odečet) pro práci v grafickém režimu openSCAD.  V režimu draft = false se model renderuje ve vysokém rozlišení a posunutý/otočený do tiskové pozice. Make automaticky přepisuje proměnnou draft (příznakem -D "draft = false"). Všechny soubory s prefixem P_ a celou složku print_data jsem smazal.

4) Upravil jsem makefile tak, že při přegenerování obrázku PNG vytvoří dočasný soubor tmp.scad, který obsahuje pouze příkaz import("../amf/WINDGAUGE_XXX.stl") a ten použije pro vygenerování obrázku. Tím pádem není potřeba znovu renderovat model. Navíc jsem změnil závislost obrázků ze SCAD na STL soubory, ale to je spíše kosmetická změna.

5) Upravil jsem soubor assembly.scad tak, aby používal pouze již vygenerované modely. Tohle budu muset ještě ověřit, protože se mi aktuálně po přerenderování ztratí některé části modelu a mám problém, s generováním průřezů.

kaklik, 2019-05-15:
Pokusil jsem se novou úpravu použít a vypadá to, že je nějaká potíž s absolutními cestami, které zřejmě někde zůstaly.

```
kaklik@popelnice:/media/kaklik/91d64ab1-13dc-4023-87e9-e53e8433a489/git/MLAB/Modules/mechanical/WINDGAUGE03A/cad$ make
make: *** No rule to make target '/Users/jkt/playground/OpenSCAD/kaklik/Modules/mechanical/WINDGAUGE03A/cad/src/lib/copyFunctions.scad', needed by '../amf/WINDGAUGE_R05.stl'.  Stop.
kaklik@popelnice:/media/kaklik/91d64ab1-13dc-4023-87e9-e53e8433a489/git/MLAB/Modules/mechanical/WINDGAUGE03A/cad$

```

JanKott, 2019-05-15:
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

Jé, na to jsem zapomněl. Opravim to ručně a pak doplnim nějakej skript, kterej to vždycky opraví.

JanKott, 2019-05-15:
Opraveno. Je otázka, kde všude ještě chceš abych to měnil?
Našel jsem ještě 2 Makefile, které pracují se *.scad soubory:
./Modules/mechanical/AWSCREEN01A/cad/Makefile
./Modules/mechanical/WINDGAUGE02A/cad/print_data/Makefile

kaklik, 2019-05-15:
Já si myslím, že by se na tenhle systém mělo přejít všude. Protože je to změna, ktrá by mohla značně zpřehlednit i jiné mnohem rozsáhlejší návrhy.

Teď jsem si ale zkoušel v aktualizovaném repozitáři spustit make.  Trochu mě překvapilo, že změny, které git vidí jsou rozsáhlejší než bych očekával.  Konkrétně to vypadá takhle:

	$ git status
	On branch master
	Your branch is up to date with 'origin/master'.

	Changes not staged for commit:

	  (use "git add <file>..." to update what will be committed)

	  (use "git checkout -- <file>..." to discard changes in working directory)

	modified:   ../amf/WINDGAUGE_R03.stl
	modified:   dep/WINDGAUGE_D02.deps
	modified:   dep/WINDGAUGE_R01.deps
	modified:   dep/WINDGAUGE_R03.deps
	modified:   dep/WINDGAUGE_R04.deps
	modified:   dep/WINDGAUGE_R05.deps
	modified:   dep/WINDGAUGE_R06.deps
	modified:   dep/WINDGAUGE_S01.deps
	modified:   dep/WINDGAUGE_S03.deps
	modified:   dep/WINDGAUGE_S04.deps
	modified:   ../doc/img/WINDGAUGE_D01.png
	modified:   ../doc/img/WINDGAUGE_D02.png
	modified:   ../doc/img/WINDGAUGE_R01.png
	modified:   ../doc/img/WINDGAUGE_R03.png
	modified:   ../doc/img/WINDGAUGE_R04.png
	modified:   ../doc/img/WINDGAUGE_R05.png
	modified:   ../doc/img/WINDGAUGE_R06.png
	modified:   ../doc/img/WINDGAUGE_S01.png
	modified:   ../doc/img/WINDGAUGE_S03.png
	modified:   ../doc/img/WINDGAUGE_S04.png

Přitom bych očekával, že jak soubory .deps, tak i soubory .png budou vygenerovány jako identické. Tj. git nepozná změnu. Je ale možné, že to souvisí s nějakým obsahem časových razítek, nebo něčím podobný nezajímavým.  Pro změnu  ../amf/WINDGAUGE_R03.stl ale nemám vysvětlení vůbec.

roman-dvorak, 2019-05-15:
Nebylo by dobré tento Makefile přesunout do vlastního repozitáře a na všechny další místa, kde se bude používat, importovat jen submodul? Už se používá na docela dosti místech :)

Nebo vymyslet nějaký jiný způsob, jak udržovat tento makefile aktuální skrze více repozitářů a umístění.

kaklik, 2019-05-15:
@roman-dvorak  Tenhle makefile je dost novinka. Takže se používá zatím u WINDGAUGE03A.  Pak bych samozřejmě chtěl, aby se používal i na více místech. Spíš než submodul s makefile je asi lepší zvážit submodul ze složky lib a do této složky přesunout i parametry některých obecněji používaných součástek, jako jsou třeba šrouby a matice.

kaklik, 2019-05-15:
@JanKott  tak diff na ten deps soubor dopadne takhle:

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

vypadá to, že se to liší pořadím.

JanKott, 2019-05-16:
Přidal jsem sortování *.deps souborů. OpenSCAD ovšem vygeneruje poslední záznam bez escapovaného konce řádku (bez zpětného lomítka) a ten se pak může dostat doprostřed. Proto jsem navíc přidal, že se zpětné lomítko doplní na řádek, na kterém chybí.

kaklik, 2020-04-15:
> Nebylo by dobré tento Makefile přesunout do vlastního repozitáře a na všechny další místa, kde se bude používat, importovat jen submodul? Už se používá na docela dosti místech :)
>
> Nebo vymyslet nějaký jiný způsob, jak udržovat tento makefile aktuální skrze více repozitářů a umístění.

Tohle je již aktuální záležitost.

@JanKott  z makefilu, který tu vznikl je odvozen i úplně [nový makefile](https://github.com/ThunderFly-aerospace/TF-G2/blob/master/utils/Makefile), který už [používá processor3D](https://github.com/ThunderFly-aerospace/processor3D)  a obsahuje přípravu pro automatické zpracování modelů.

roman-dvorak, 2020-04-15:
@JanKott nedokázal bys udělat nějaký AMFsorter? Je tam stejný problém jako u STL. Že pokud se vygenerují dva AMF soubory tak se liší. A pak to dělá problém GITu. Což je předevšim problém u toho automatického generování výrobních souborů.

roman-dvorak, 2020-04-15:
Navrhoval bych ten makefile přesunout do toho repozitáře [OpenSCAD_stdlib](https://github.com/ThunderFly-aerospace/Openscad_stdlib)

kaklik, 2020-04-15:
> @JanKott nedokázal bys udělat nějaký AMFsorter? Je tam stejný problém jako u STL. Že pokud se vygenerují dva AMF soubory tak se liší. A pak to dělá problém GITu. Což je předevšim problém u toho automatického generování výrobních souborů.

Roman myslí AMF alternativu tohoto: https://pypi.org/project/stlsort/

Po zběžném prohledání webu se mi nepodařilo najít alternativu pro AMF.

kaklik, 2020-04-15:
> Navrhoval bych ten makefile přesunout do toho repozitáře [OpenSCAD_stdlib](https://github.com/ThunderFly-aerospace/Openscad_stdlib)

Nad tím jsem taky přemýšlel. Ale nevím jak ten make nějak rozumně spouštět, aby se nemuselo lézt kdoví jak hluboko do toho projektu. Nějakým bashovým skriptem?

JanKott, 2020-04-16:
@roman-dvorak Já tohle nepozoruju. Vygeneroval jsem si 5x WINDGAUGE_R05.amf a všechny jsou stejné. Můžeš mi dát příklad kde se ti to děje?

JanKott, 2020-04-16:
> > Navrhoval bych ten makefile přesunout do toho repozitáře [OpenSCAD_stdlib](https://github.com/ThunderFly-aerospace/Openscad_stdlib)
>
> Nad tím jsem taky přemýšlel. Ale nevím jak ten make nějak rozumně spouštět, aby se nemuselo lézt kdoví jak hluboko do toho projektu. Nějakým bashovým skriptem?

Pořád nerozumim v čem je problém. Zkoušel jsem si například toto na anemometru - přesunul jsem makefile uplně mimo WINDGAUGE složky a zavolal make s cestou
:
`jkt@ntb:~/playground/OpenSCAD/kaklik/WINDGAUGE03/cad> make --dry-run --always-make -f ../../makefile_folder/Makefile`

JanKott, 2020-04-16:
> Navrhoval bych ten makefile přesunout do toho repozitáře [OpenSCAD_stdlib](https://github.com/ThunderFly-aerospace/Openscad_stdlib)

@roman-dvorak Jinak to asi nebude složitý, to bude hezká pythoní úloha ;-)

načteme soubor, vertexy si uložíme do listu listů:
>>> a = [[-70, 0, 0], [-69, 3, 5], [-69, 2, 7], [-69, 2, 3], [4,5,6]]
zjistíme pořadí:
>>> [b[0] for b in sorted(enumerate(a),key=lambda i:i[1])]
[0, 3, 2, 1, 4]

A pak to podle toho sesortíme.

Otázka zůstává - je to opravdu potřeba? Mě to připadá už sesortěný (používám OpenSCAD 2020.02.16.nightly (git 5696d07))

kaklik, 2020-04-16:
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

Ano, ale tady je problém, že ten příkaz je závislý na tom projektu. Což je hodně nepříjemný pro dokumentaci, neboť to vyžaduje, aby si uživatel sám upravil ten příkaz podle toho, jak to zrovna má.

kaklik, 2020-04-16:
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

Je možný že se to týká jen rozdílných verzí openscad. Vytvořil jsem na to nové issue https://github.com/ThunderFly-aerospace/Openscad_stdlib/issues/3

Taktéž jsem vytvořil nové issue na tu záležitost s makefile: https://github.com/ThunderFly-aerospace/Openscad_stdlib/issues/2

kaklik, 2020-04-16:
Tohle issue začalo vypadat poměrně chaoticky, navíc není zřejmě úplně vhodně umístěno. Vytvořil jsem proto nová issue obsahující zde nevyřešené záležitosti v [repozitáři s knihovnami](https://github.com/ThunderFly-aerospace/Openscad_stdlib/issues).

Closed 2020-04-16.

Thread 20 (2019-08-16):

Schéma k I2CADC02A nenajde knihovny

povik, 2019-08-16:
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

kaklik, 2019-08-16:
Tohle ale není problém jen tohoto schéma ale celého způsobu se zacházením KiCADu s knihovnami.
Ten projekt by bylo potřeba přeuložit s novými knihovnami, aby to zas fungovalo.

Closed 2019-08-16.

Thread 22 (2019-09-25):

PROGLOG01A

povik, 2019-09-25:
PROGLOG01A by měl být modul malého hradlového pole ICE40UP5K od Lattice. Pozoruhodné na tomto poli je, že lze programovat open-source nástroji.

povik, 2019-09-25:
Ve schématu je třeba ještě alespoň

- určit velikost flash paměti
- zajistit hranu na RESET pinu po připojení napájení, a asi přidat resetovací tlačítko
- rozmyslet zapojení programovacího hřebínku
- zajistit nástup napájení ve správném pořadí

K poslednímu mám otázku: Čím spínat 3V3 napájení, které je z vnější přivedeno k modulu a které má na hradlovém poli nastoupit až po regulovaných 1V2? Jak zajistit minimální úbytek?

kaklik, 2019-09-25:
Možná by ti mohlo pomoci řešení [tohoto modulu](https://github.com/MLAB-project/Modules/blob/master/power_supply/BATPOWER05A/hw/sch_pcb/BATPOWER05A.pdf) který kreslil @ChroustJan.

Další možnost jsou [power sequencers](http://www.ti.com/power-management/sequencers/overview.html#), nebo [powerpath controllers](https://www.analog.com/en/products/monitor-control-protection/powerpath-ideal-diodes-load-switches.html#)

kaklik, 2020-10-24:
Tohle mi přijde jako již vyřešené.

Closed 2020-10-24.

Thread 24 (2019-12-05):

AWSCREEN01A - optimalizace tisku

kaklik, 2019-12-05:
Úchyt pro senzor má nevhodnou tloušťku stěny, která nevychází na počet perimetrů.

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

Kulatý oblouk krytu pro konektor, není pro tisk úplně nejlepší. Vhodný by byl například lichoběžník, nebo trojúhelník. Takhle je v horní části klenby problém s kvalitou tisku mostu a model je náročný na chlazení.

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

Closed 2023-07-05.

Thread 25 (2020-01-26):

ISM01A - Chybí rezistor na bázi tranzistoru Q1 a Q2

kaklik, 2020-01-26:
Tranzistory Q1 a Q2, které ovládají LED D2 a D3, nemají na bázi rezistor, který by omezoval vstupní proud.
Díky tomu je možné tranzistory velmi snadno zničit připojením napájecího zdroje na jejich vstupní hřebínek.

kaklik, 2020-06-11:
Přesunuto do: https://github.com/mlab-modules/ISM01/issues/1

Closed 2020-06-11.

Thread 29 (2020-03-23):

WINDGAUGE03A - umístění rezervní délky kablíků

kaklik, 2020-03-23:
Rezervní délku kablíků, která vzniká kvůli celkové montáži je potřeba umístit okolo PCB se senzory anemometru. Přibližně takto:

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

Díky tomu je však potřeba upravit horní kryt tak, aby mezi výstupkem na kterém leží PCB a kapkovým krytem byla mezera do které se vodiče umístí.

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

Closed 2020-03-25.

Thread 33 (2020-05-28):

GPS01C - revize

kaklik, 2020-05-28:
@ChroustJan  Prohlížel jsem si nově navržený modul [GPS01C](https://github.com/MLAB-project/Modules/tree/master/sensors/GPS01C) určený pro RTK navigaci.

Nerozumím několika záležitostem:

1. Jak má fungovat toto zapojení:
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
Přijde mi, že zenerova dioda tam nemá prakticky žádnou jinou funkci než, jako standardní dioda, která zabraňuje tomu, aby se kondenzátor vybil do napájení +3V3.

1. V téhle části se mi zdá, že je tam jeden z napájecích konektorů navíc:
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
Není mi zároveň jasná funkce přepínacího jumperu napájení. Očekával bych, že modul je buď napájen z USB, nebo z externího zdroje. Myslím že nedává smysl, aby byl napájen z externího zdroje a zároveň připojen na USB. Předchozí modul GPS01B rozlišoval stav, napájeno z USB a vypnuto USB na tomto modulu nevidím žádný snímací pin, který by to umožňoval rozlišit.
Pokud ale ubrání jednoho hřebínku nevede ke zmenšení, nebo zjednodušený modulu, tak to asi není potřebné řešit.

Neměl by se modul jmenovat spíše GPS02A? Když používá dost jinou řadu uBlox čipů?

ChroustJan, 2020-05-29:
1. Chápeš to dobře. Vzal jsem to z předchozího modulu. Podle mě jsme jí tam dali kvůli tomu že jí máme skladem a měla možná menší úbytek než M4 a byla menší.

2. Modul umí odpojit USB. Je to hřebínkem USBON na PCB. Já to v zásadě udělal zas jak u předchozí verze. A je možné že to nikdy nevyužíváme a je to zbytečné. Nevím zda může nastat stav, že by jsme měli zastrčené USB a chtěli to napájet z hřebínku.

U názvu jsem vycházel z toho, že je to náhrada předchozího.

roman-dvorak, 2020-05-29:
> Myslím že nedává smysl, aby byl napájen z externího zdroje a zároveň připojen na USB.

Tak tohle si úplně nemyslím. Protože třeba při posledním testu jsme zpozorovali, že je možné, že nějaké USB zařízení bylo odpojeno kvůli napájení. Byl tam asi problém, že zřejmě modem bere více než o sobě říká. Ale tento problém by šlo také vyřešit tím, že do GPS by se přivedlo externí napájení a USB by fungovalo.

kaklik, 2020-05-29:
> > Myslím že nedává smysl, aby byl napájen z externího zdroje a zároveň připojen na USB.
>
> Tak tohle si úplně nemyslím. Protože třeba při posledním testu jsme zpozorovali, že je možné, že nějaké USB zařízení bylo odpojeno kvůli napájení. Byl tam asi problém, že zřejmě modem bere více než o sobě říká. Ale tento problém by šlo také vyřešit tím, že do GPS by se přivedlo externí napájení a USB by fungovalo.

Ano, ale USB nemůže fungovat dobře, pokud tam existují zařízení, která si říkají o nepravdivý odběr.
Takže tohle je potřeba řešit na úrovni modemu, nikoliv externím napájením jiných zařízení.  Tohle je velmi specifický případ a neměl by nastávat.

kaklik, 2020-05-29:
>     1. Chápeš to dobře. Vzal jsem to z předchozího modulu. Podle mě jsme jí tam dali kvůli tomu že jí máme skladem a měla možná menší úbytek než M4 a byla menší.

Z hlediska napěťového úbytku je tam myslím vhodné zvolit nějakou shottkyho diodu.
Třeba tohle vypadá použitelně: https://www.vishay.com/docs/85510/bas85.pdf (pokud nevadí to kulatý pouzdro)

>
>     2. Modul umí odpojit USB. Je to hřebínkem USBON na PCB. Já to v zásadě udělal zas jak u předchozí verze. A je možné že to nikdy nevyužíváme a je to zbytečné. Nevím zda může nastat stav, že by jsme měli zastrčené USB a chtěli to napájet z hřebínku.

Já si myslím, že by taková situace neměla nastat.  Záležitost, kterou zmiňuje Roman musíme vyřešit na modemu, nikoliv na GPS.

>
>
> U názvu jsem vycházel z toho, že je to náhrada předchozího.

Náhrada to je, ale není to oprava návrhu, je to funkčně jiný modul. Z toho důvodu se má změnit to číslo, nikoliv písmeno.

ChroustJan, 2020-06-01:
Přejmenoval jsem modul na 02A. Provedu ještě nějaké kontroly, ale jinak je modul ve výrobním stavu.

Closed 2020-06-03.

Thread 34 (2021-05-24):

MCX connectors fragility

kaklik, 2021-05-24:
The new [MCX connectors](https://www.rfsupplier.com/u_file/1612/products/08/4016e72257.) used to connect modules instead of SMA are prone to break in case of inappropriate inserting in [PCB mount connector](https://www.elecbee.com/4302-large_default/mcx-connector-pcb-mount-straight-jack-through-hole.jpg).

The cause of damage is the sharp edge on the top of PCB connector cylinder. This sharp edge cut-out
 springs on offset inserted cable connector.

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

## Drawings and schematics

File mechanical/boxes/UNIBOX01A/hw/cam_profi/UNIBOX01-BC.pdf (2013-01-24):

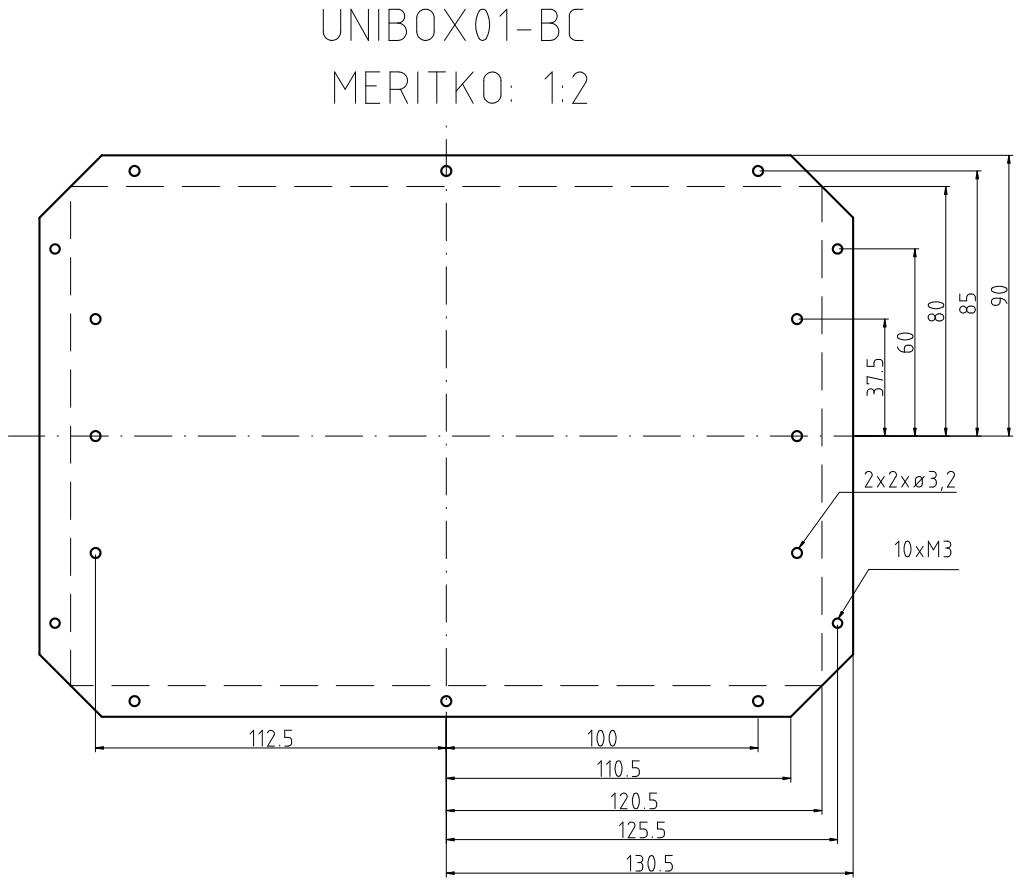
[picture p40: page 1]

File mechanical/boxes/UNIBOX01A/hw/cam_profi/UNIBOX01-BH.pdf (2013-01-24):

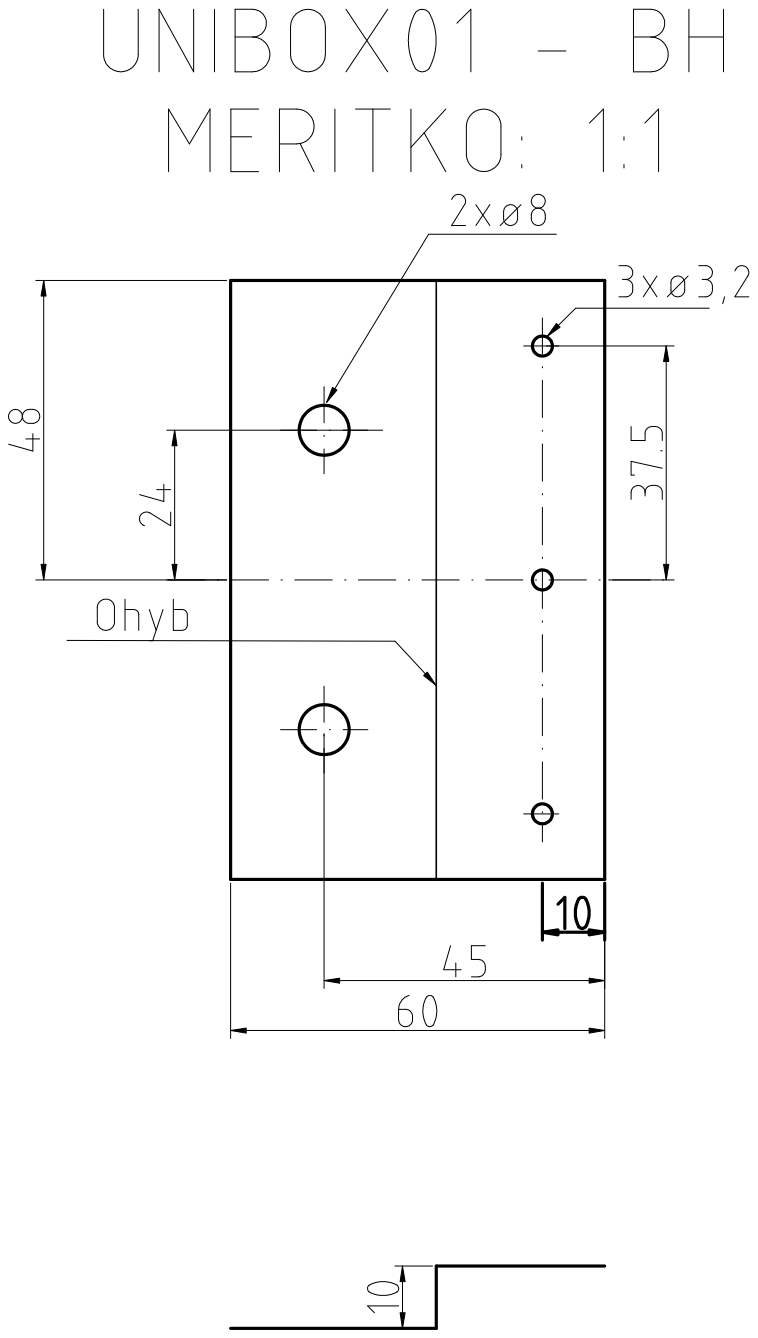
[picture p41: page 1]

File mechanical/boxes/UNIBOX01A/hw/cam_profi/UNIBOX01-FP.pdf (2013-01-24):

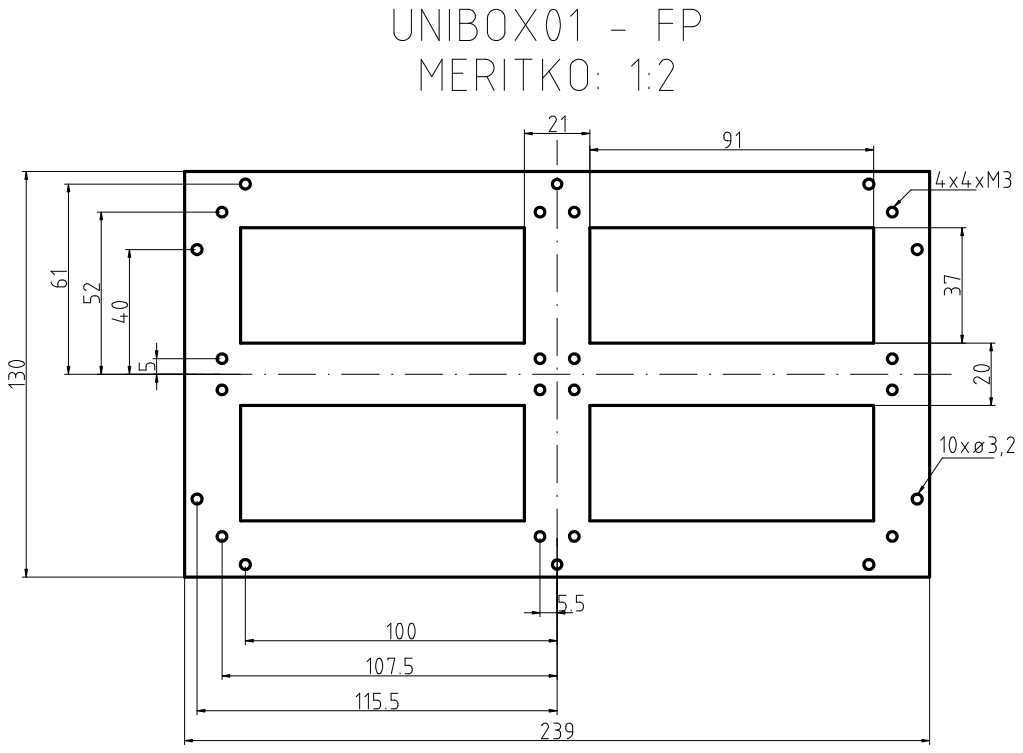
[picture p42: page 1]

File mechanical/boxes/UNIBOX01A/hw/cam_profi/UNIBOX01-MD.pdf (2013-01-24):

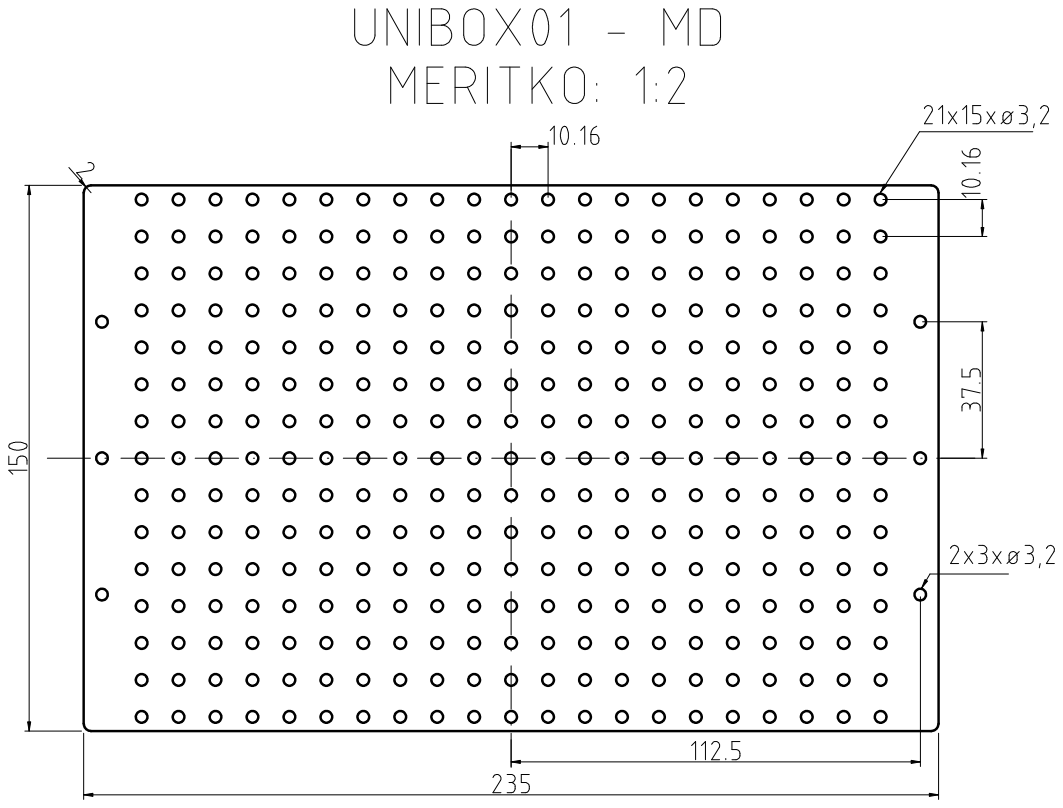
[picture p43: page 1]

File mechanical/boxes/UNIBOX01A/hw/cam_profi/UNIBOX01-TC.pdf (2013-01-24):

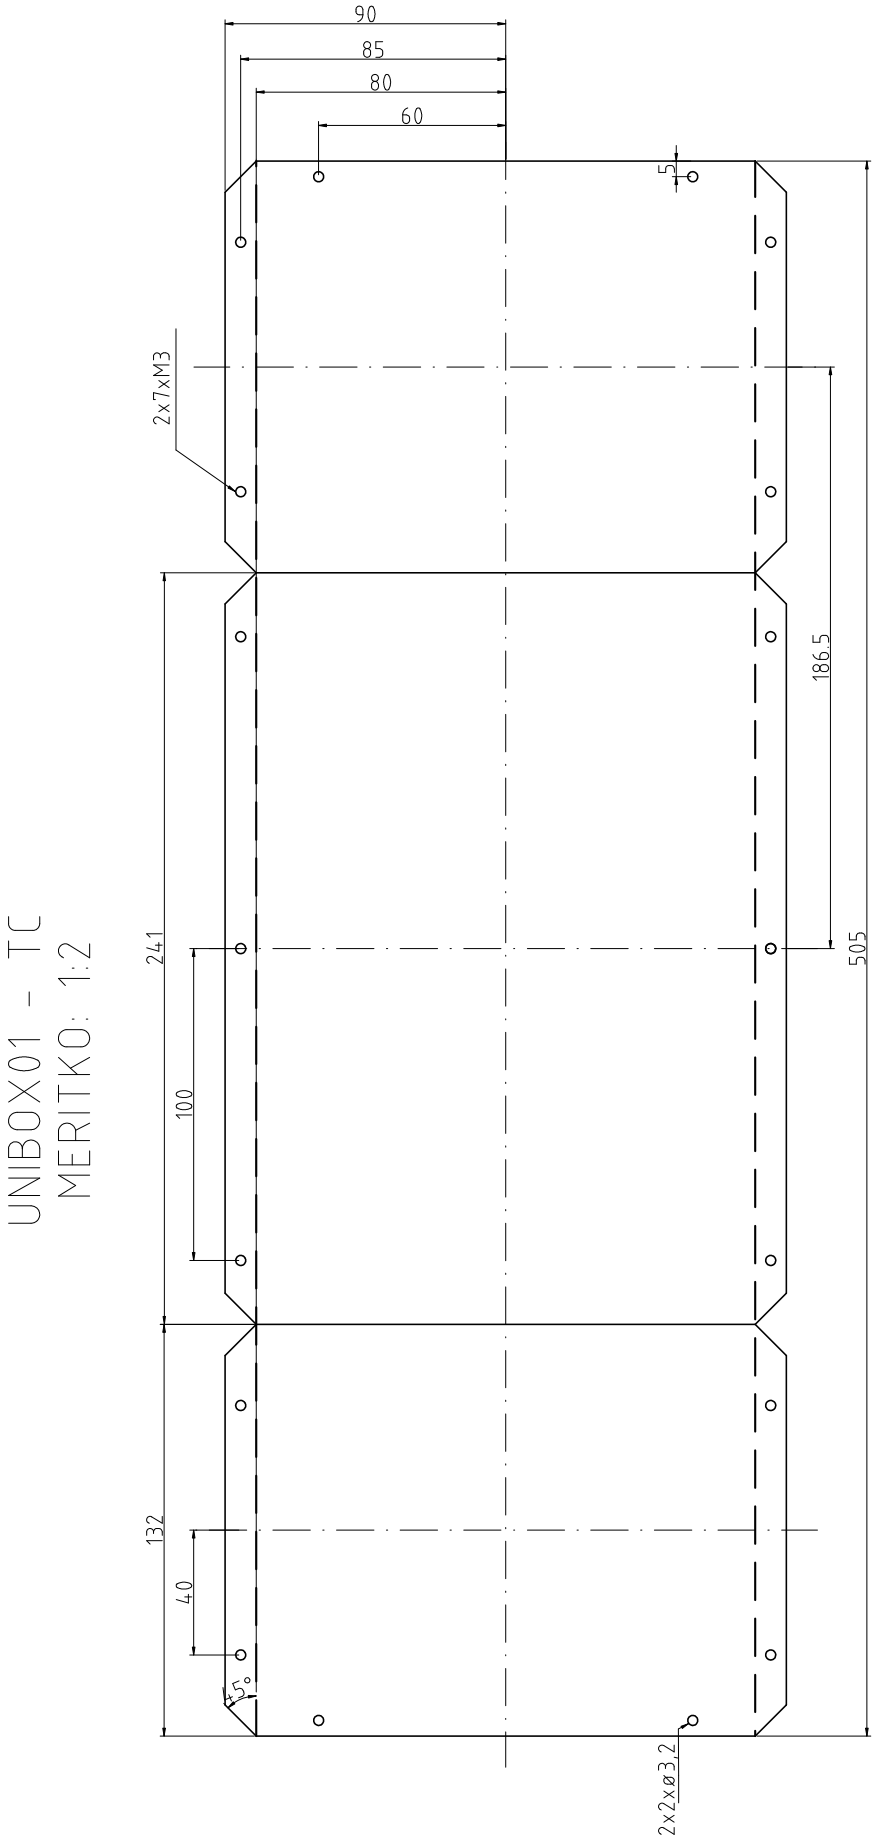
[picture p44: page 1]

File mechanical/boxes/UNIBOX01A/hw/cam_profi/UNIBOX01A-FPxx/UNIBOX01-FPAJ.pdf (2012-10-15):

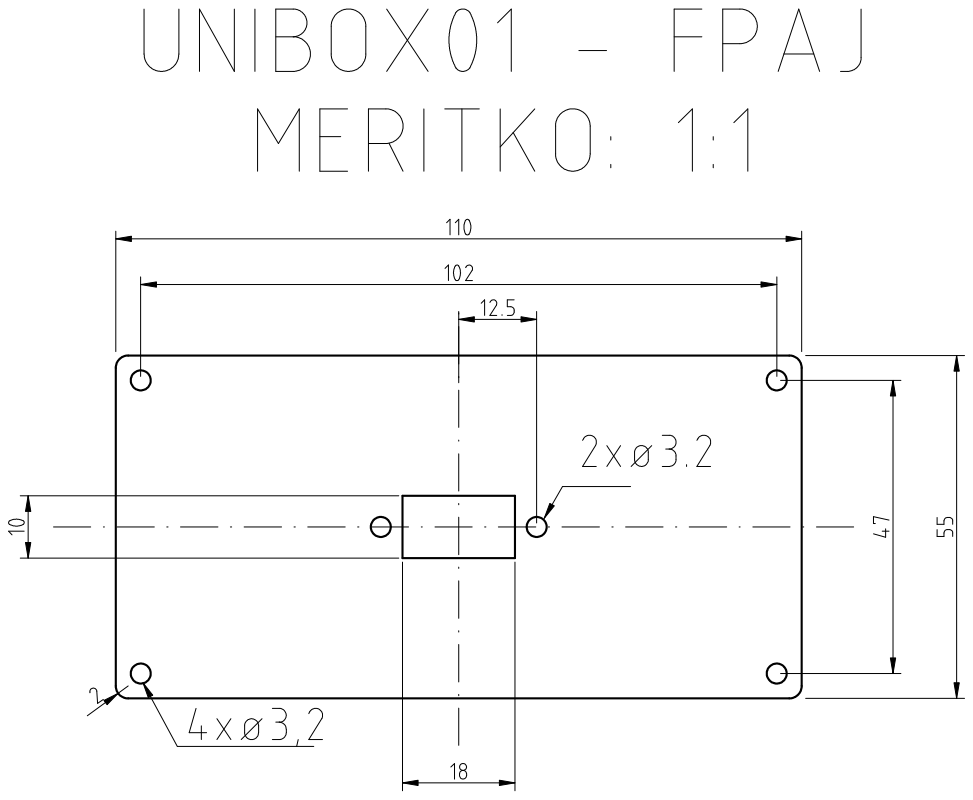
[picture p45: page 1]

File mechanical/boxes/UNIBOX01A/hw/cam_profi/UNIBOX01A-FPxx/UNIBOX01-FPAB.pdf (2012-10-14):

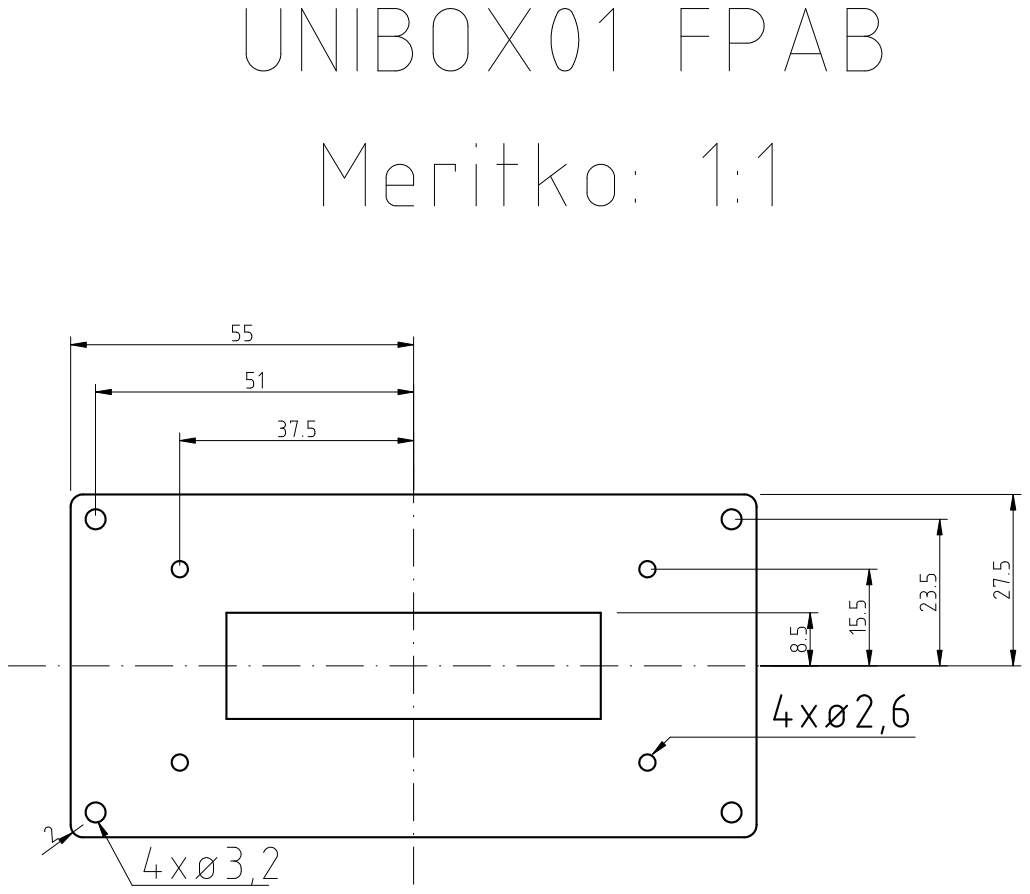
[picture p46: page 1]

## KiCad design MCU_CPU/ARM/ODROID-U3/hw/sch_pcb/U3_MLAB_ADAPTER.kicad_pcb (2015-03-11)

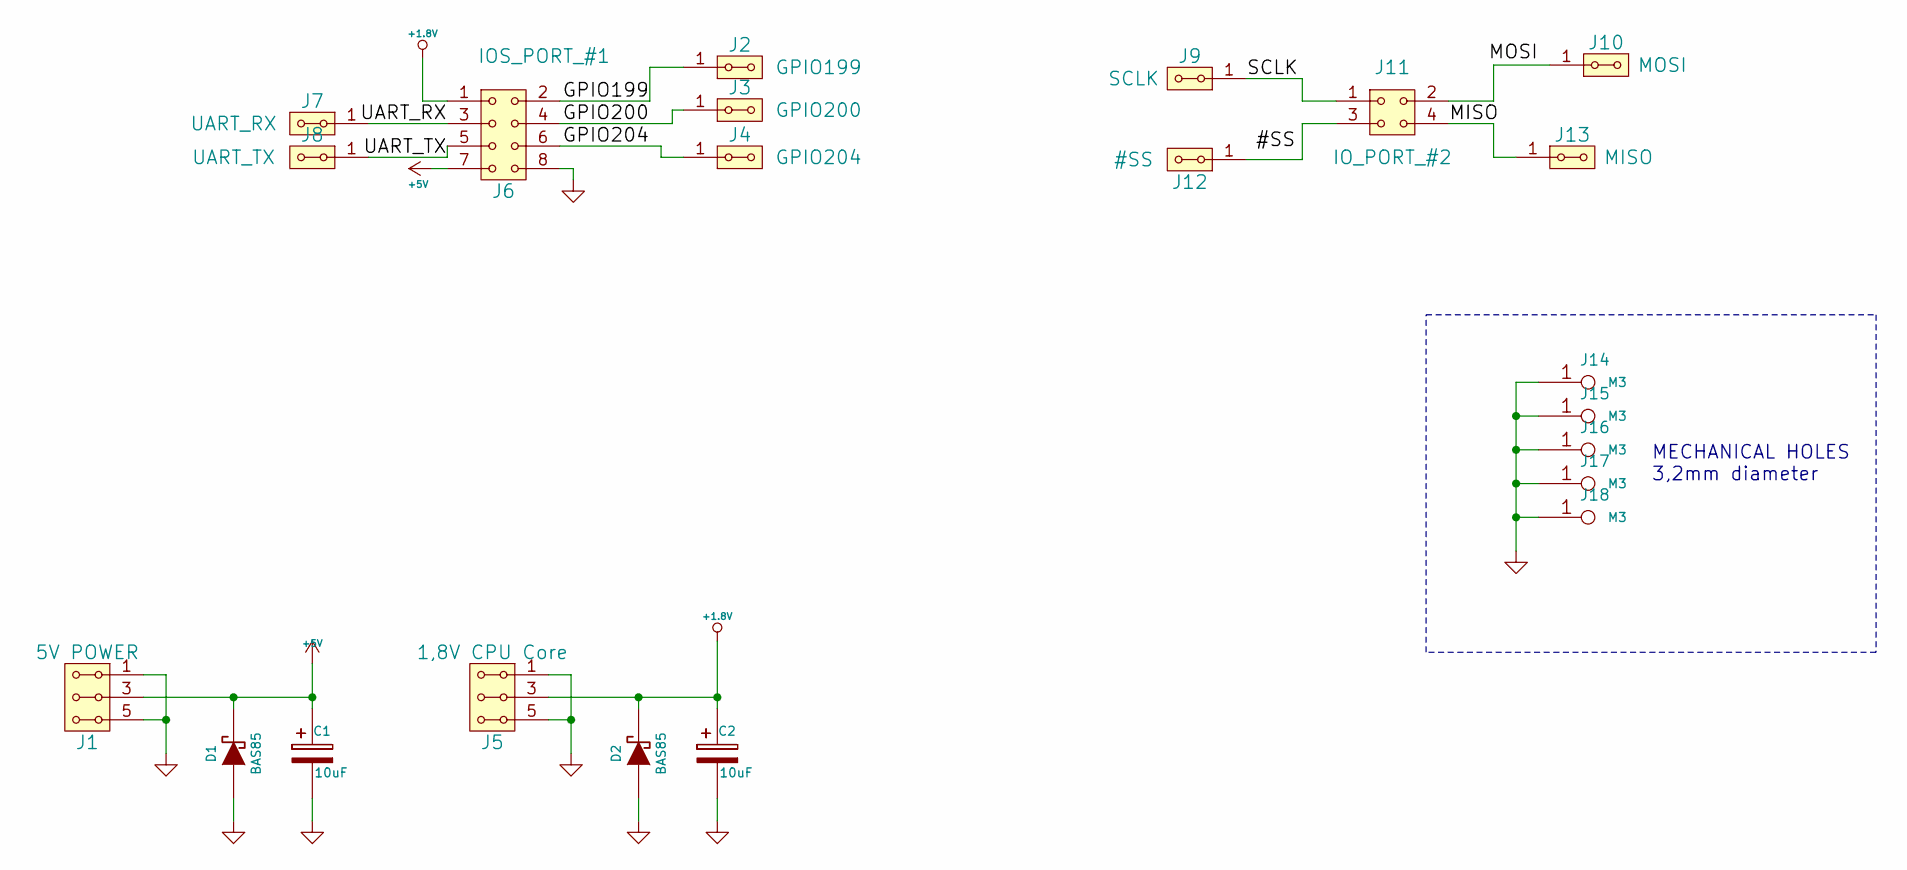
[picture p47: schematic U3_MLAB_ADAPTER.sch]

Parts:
C1, C2: 10uF; TantalC_SizeB_EIA-3528_Reflow
D1: BAS85; Diode-SMA_Standard
D2: BAS85; Diode-MiniMELF_Standard
J1: 5V POWER; Straight_2x03
J2: GPIO199; Pin_Header_Straight_2x01
J3: GPIO200; Pin_Header_Straight_2x01
J4: GPIO204; Pin_Header_Straight_2x01
J5: 1,8V CPU Core; Straight_2x03
J6: IOS_PORT_#1; 2mm_Pin_Header_Straight_2x04
J7: UART_RX; Pin_Header_Straight_2x01
J8: UART_TX; Pin_Header_Straight_2x01
J9: SCLK; Pin_Header_Straight_2x01
J10: MOSI; Pin_Header_Straight_2x01
J11: IO_PORT_#2; 2mm_Pin_Header_Straight_2x02
J12: #SS; Pin_Header_Straight_2x01
J13: MISO; Pin_Header_Straight_2x01
J14, J15, J16, J17, J18: M3; MountingHole_3mm

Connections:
+1.8V: C2.1, D2.2 (K), J5.3, J5.4, J6.1
+5V: C1.1, D1.2 (K), J1.3, J1.4, J6.7
/GPIO199: J2.1, J2.2, J6.2
/GPIO200: J3.1, J3.2, J6.4
/GPIO204: J4.1, J4.2, J6.6
/MISO: J11.4, J13.1, J13.2
/SCLK: J9.1, J9.2, J11.1
/UART_RX: J6.3, J7.1, J7.2
/UART_TX: J6.5, J8.1, J8.2
GND: C1.2, C2.2, D1.1 (A), D2.1 (A), J1.1, J1.2, J1.5, J1.6, J5.1, J5.2, J5.5, J5.6, J6.8, J14.1, J15.1, J16.1, J17.1, J18.1
unnamed: J10.1, J10.2, J11.2
unnamed: J11.3, J12.1, J12.2

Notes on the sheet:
MECHANICAL HOLES 3,2mm diameter

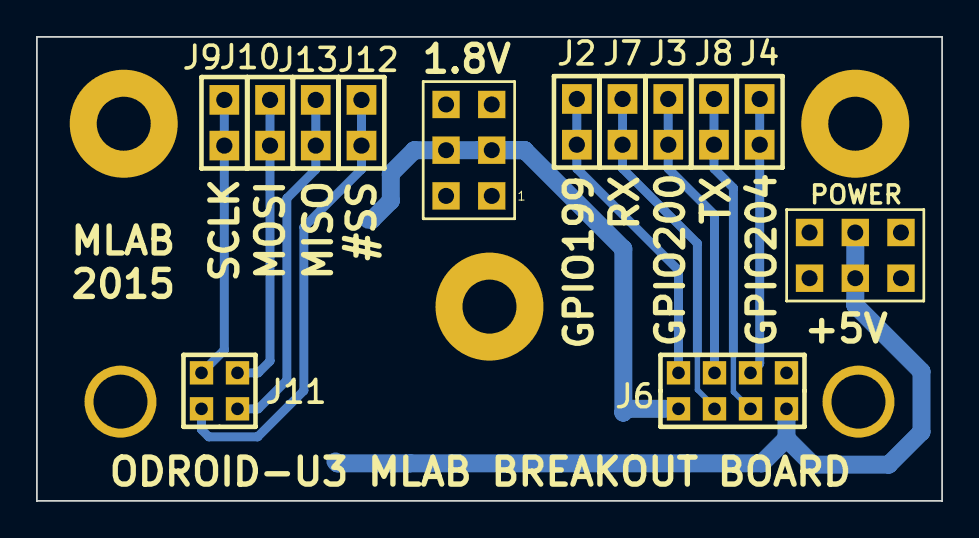
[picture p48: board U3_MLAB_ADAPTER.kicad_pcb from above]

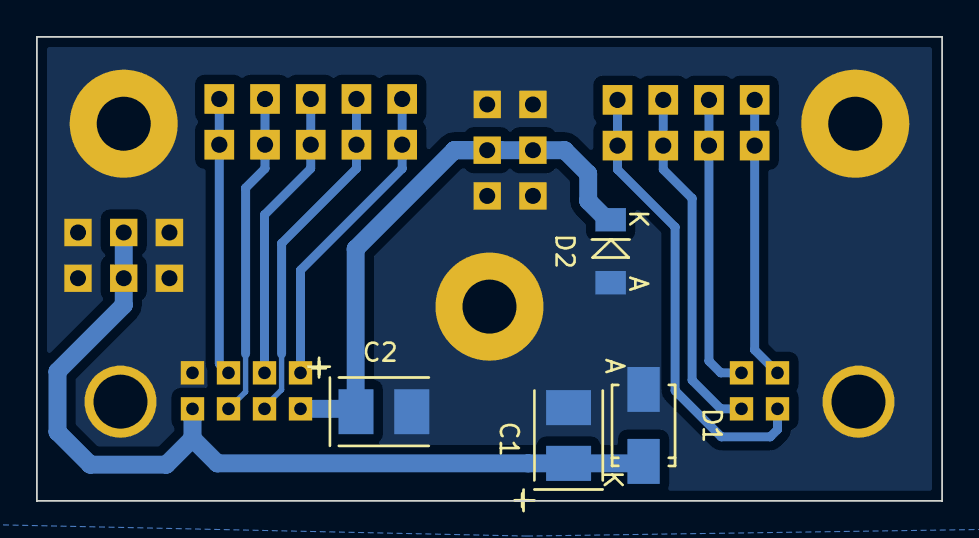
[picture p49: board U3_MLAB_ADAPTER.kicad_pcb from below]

Board: 2 copper layers, 50.3 x 25.8 mm, 22 parts (4 on the bottom side), 12 nets.

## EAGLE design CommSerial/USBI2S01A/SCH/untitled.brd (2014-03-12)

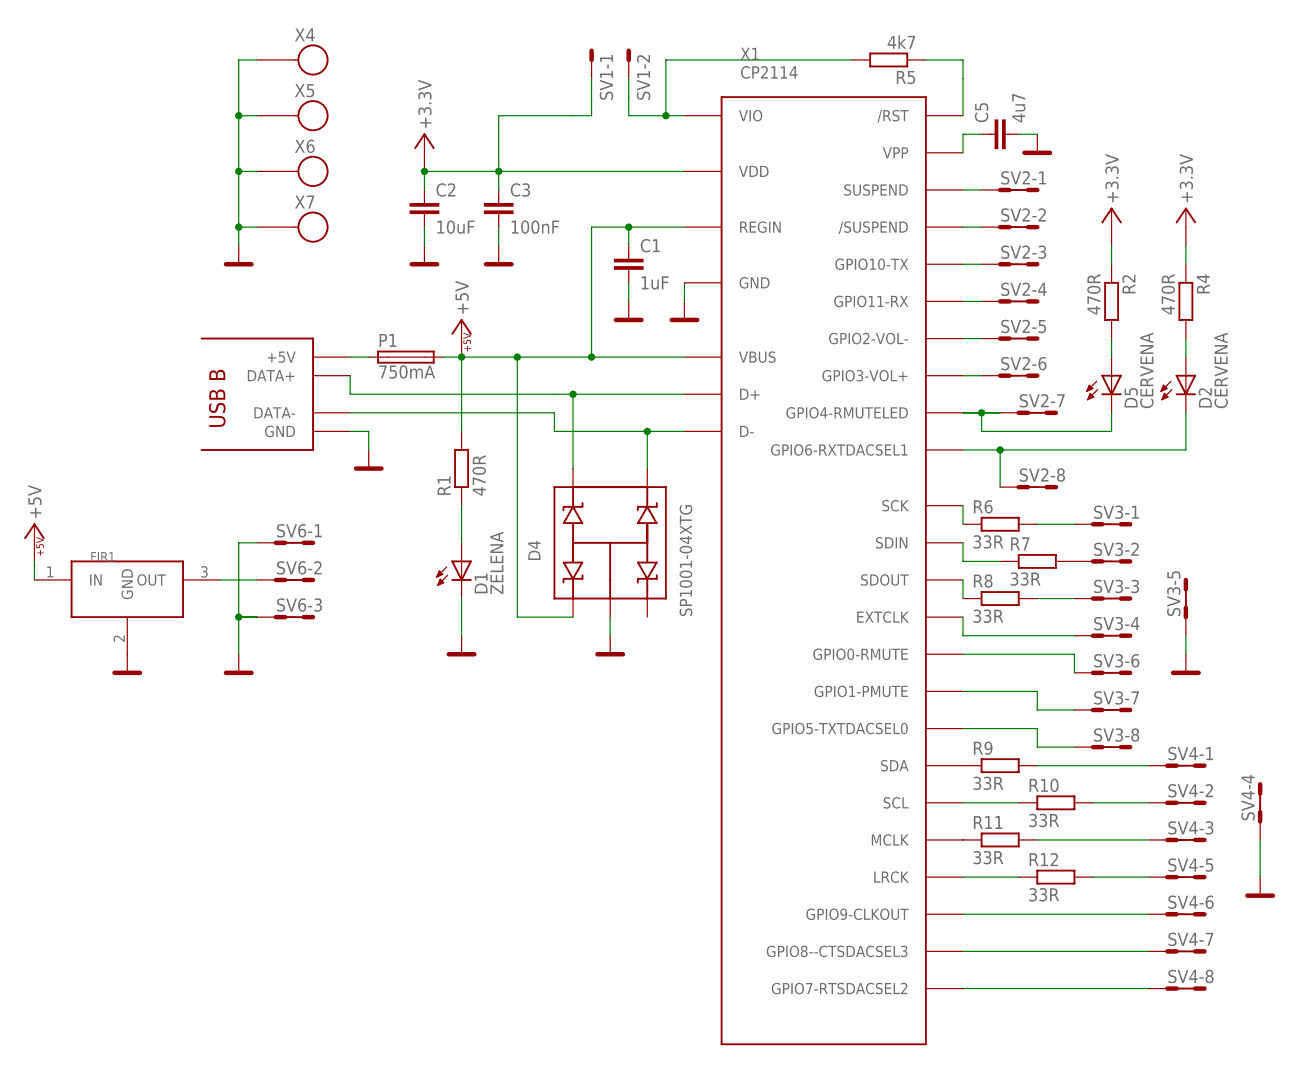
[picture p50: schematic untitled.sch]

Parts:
C1: 1uF; C0805
C2: 10uF; C0805
C3: 100nF; C0805
C5: 4u7; C0805
D1: ZELENA; 1206_2
D2, D5: CERVENA; 1206_2
D4: SP1001-04XTG; SOT553
FIR1: FILTR0805; F0805
P1: 750mA; 1812
R1, R2, R4: 470R; 0805
R5: 4k7; 0805
R6, R7, R8, R9, R10, R11, R12: 33R; 0805
SV1: MA02-1
SV2, SV3, SV4: MA08-2
SV6: MA03-2
X1: CP2114; QFN-32
X3: USB_B
X4, X5, X6, X7: SROUB3M

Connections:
+3.3V: C2.1, C3.1, R2.1, R4.1, SV1.1, X1.7 (VDD)
+5V: C1.1, D4.1, FIR1.1 (IN), P1.2, R1.2, X1.8 (REGIN), X1.9 (VBUS)
/SUSPEND: SV2.3, SV2.4, X1.17 (/SUSPEND)
EXTCLK: SV3.7, SV3.8, X1.31 (EXTCLK)
GND: C1.2, C2.2, C3.2, C5.2, D1.K (C), D4.2, FIR1.2 (GND), SV3.9, SV3.10, SV4.7, SV4.8, SV6.1, SV6.2, SV6.5, SV6.6, X1.3 (GND), X1.EXP (GND), X3.4 (GND), X3.GND, X3.GND2 (GND), X4.P$1, X5.P$1, X6.P$1, X7.P$1
GP0: SV3.11, SV3.12, X1.30 (GPIO0-RMUTE)
GP1: SV3.13, SV3.14, X1.29 (GPIO1-PMUTE)
GP2: SV2.9, SV2.10, X1.14 (GPIO2-VOL-)
GP3: SV2.11, SV2.12, X1.13 (GPIO3-VOL+)
GP4: D5.K (C), SV2.13, SV2.14, X1.12 (GPIO4-RMUTELED)
GP5: SV3.15, SV3.16, X1.28 (GPIO5-TXTDACSEL0)
GP6: D2.K (C), SV2.15, SV2.16, X1.11 (GPIO6-RXTDACSEL1)
GP7: SV4.15, SV4.16, X1.19 (GPIO7-RTSDACSEL2)
GP08: SV4.13, SV4.14, X1.20 (GPIO8--CTSDACSEL3)
GP9: SV4.11, SV4.12, X1.22 (GPIO9-CLKOUT)
GP10: SV2.5, SV2.6, X1.16 (GPIO10-TX)
GP11: SV2.7, SV2.8, X1.15 (GPIO11-RX)
LRCK: R12.2, SV4.9, SV4.10
MCLK: R11.2, SV4.5, SV4.6
unnamed: D4.5, X1.4 (D+), X3.3 (DATA+)
unnamed: D4.4, X1.5 (D-), X3.2 (DATA-)
unnamed: FIR1.3 (OUT), SV6.3, SV6.4
unnamed: C5.1, X1.21 (VPP)
unnamed: P1.1, X3.1 (+5V)
unnamed: D1.A, R1.1
unnamed: D5.A, R2.2
unnamed: D2.A, R4.2
unnamed: R5.1, X1.10 (/RST)
unnamed: R8.1, X1.32 (SDOUT)
unnamed: R7.1, X1.1 (SDIN)
unnamed: R6.1, X1.2 (SCK)
unnamed: R9.1, X1.27 (SDA)
unnamed: R10.1, X1.26 (SCL)
unnamed: R11.1, X1.25 (MCLK)
unnamed: R12.1, X1.23 (LRCK)
SCK: R6.2, SV3.1, SV3.2
SCL: R10.2, SV4.3, SV4.4
SDA: R9.2, SV4.1, SV4.2
SDIN: R7.2, SV3.3, SV3.4
SDOUT: R8.2, SV3.5, SV3.6
SUSPEND: SV2.1, SV2.2, X1.18 (SUSPEND)
VIO: R5.2, SV1.2, X1.6 (VIO)

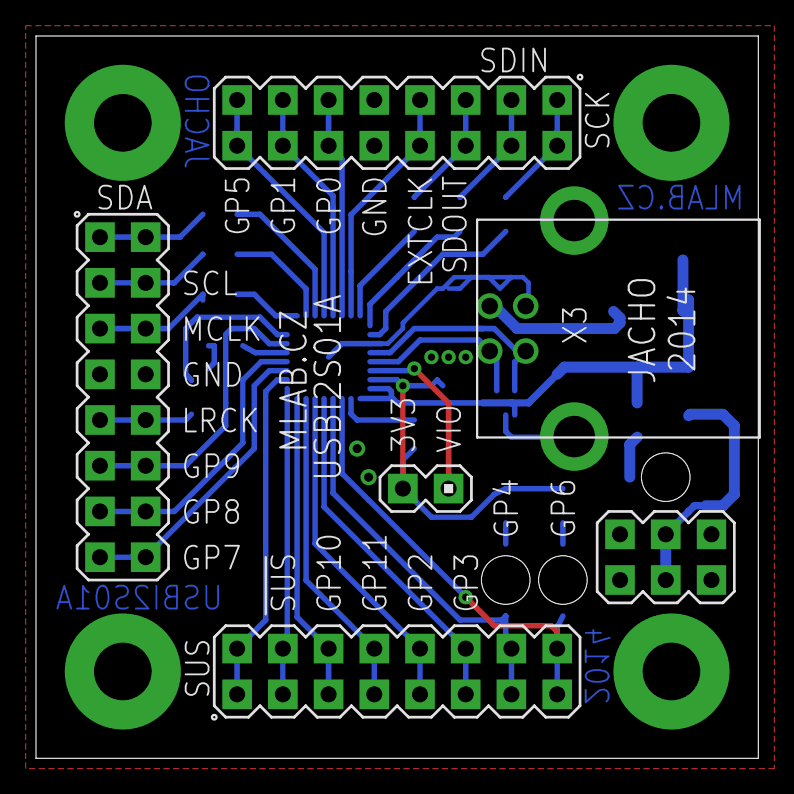
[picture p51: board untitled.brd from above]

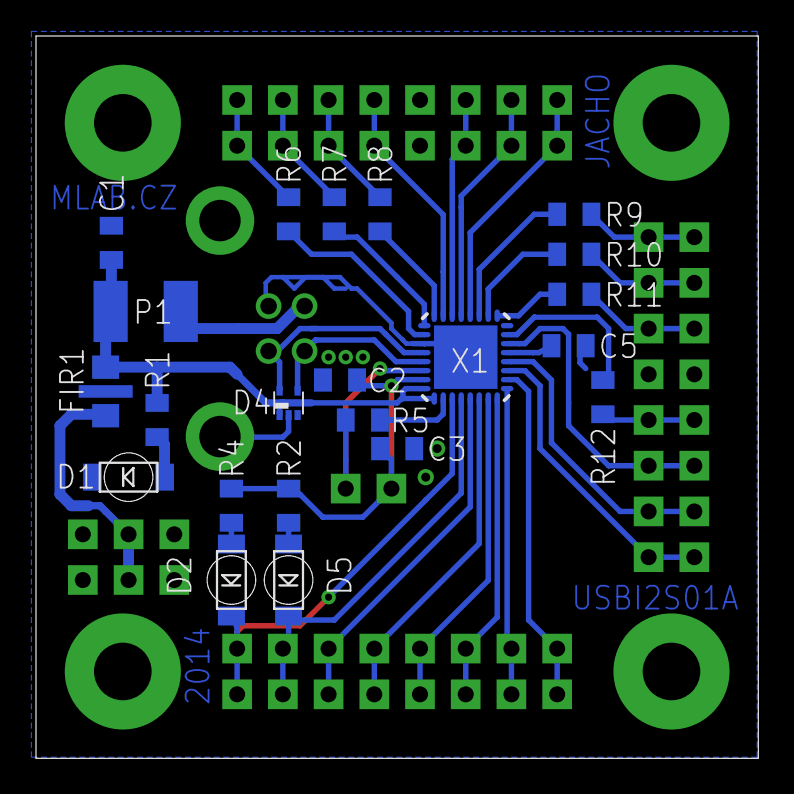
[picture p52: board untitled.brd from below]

Board: 2 copper layers, 40.1 x 40.1 mm, 32 parts (22 on the bottom side), 42 nets.

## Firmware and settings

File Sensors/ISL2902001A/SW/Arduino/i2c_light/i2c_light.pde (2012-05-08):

// I2C Light Sensor

#include <Wire.h>
#include  <math.h>

#define address 0x44 // A0 = L
#define SENSE_VIS 0
#define SENSE_IR  1

#define LIGHT_AUTORANGE  0
#define LIGHT_RANGE1  1
#define LIGHT_RANGE2  2
#define LIGHT_RANGE3  3
#define LIGHT_RANGE4  4


void setup()
{
  Wire.begin(); // join i2c bus (address optional for master)
  // I2C pins PC4 - , PC5 - 
  //
  pinMode(3, OUTPUT);  // LED pro blikani, aby bylo videt, ze to neco dela
  pinMode(5, OUTPUT);  // LED pro blikani, aby bylo videt, ze to neco dela
  Serial.begin(9600);  // Zmerena intenzita osvetleni se bude vypisovat na seriovou linku
}

int data = 0;
int light_sensor_setup;

void led_blink()
{
   digitalWrite(3, HIGH);   // set the LED on
   delay(500);
   digitalWrite(3, LOW);    // set the LED off
   delay(500);
}


int set_light_sensor(int mode)
{
int command;
  
  switch (mode)
  {
    case SENSE_VIS:
    {
       command=0b11000000;      // setup (eye light sensing; one time measurement; measurement range 1)
       break;
    }

    case SENSE_IR:
    {
       command=0b11100000;      // setup (eye light sensing; measurement range 2 [4000 lx])
       break;
    }
   
    default:
     return 3;   
  }

  // Setup device
  Wire.beginTransmission(address); 
  Wire.send(0x00);            // sends address
  Wire.send(command);      // setup (eye light sensing; one time measurement; measurement range 1)
  Wire.endTransmission();     // stop transmitting
  
  
   //  Connect to device and set register address
  Wire.beginTransmission(address); 
  Wire.send(0x00);            // sends address (command register)
  Wire.endTransmission();     // stop transmitting
  
  //  verify written command byte
  Wire.beginTransmission(address);  
  Wire.requestFrom(address, 1);
  if (command != Wire.receive())
  { 
    return 4;  
    Serial.print(data, BIN);
  }
  Wire.endTransmission();     // stop transmitting
  light_sensor_setup=command;
}

float get_light_measurement()
{
int ret=0;

   //  Connect to device and set register address
   Wire.beginTransmission(address); 
   Wire.send(0x01);            // sends address of LSB reagister 
   Wire.endTransmission();     // stop transmitting
   
   //  Connect to device and request one byte
   Wire.beginTransmission(address);
   Wire.requestFrom(address, 1);
   ret = Wire.receive();
   Wire.endTransmission();     // stop transmitting
   
   //  Connect to device and set register address
   Wire.beginTransmission(address);
   Wire.send(0x02);            // sends address of MSB register
   Wire.endTransmission();     // stop transmitting
   
   //  Connect to device and request one byte
   Wire.beginTransmission(address);
   Wire.requestFrom(address, 1);
   ret +=256 * Wire.receive();
   Wire.endTransmission();     // stop transmitting

   return (1000.0/pow(2.0,16)*ret);
}

void loop()
{
int lux=0;

   set_light_sensor(SENSE_VIS);  //setup sensor for visible measuring
   led_blink();    // Delay for measurement
   Serial.print("lux=");
   Serial.println(get_light_measurement(),2);

   set_light_sensor(SENSE_IR);  // setup sensor for infrared measuring
   led_blink(); // Delay for measurement
   Serial.print("luxIR="); 
   Serial.println(get_light_measurement(), 2); // data print
}

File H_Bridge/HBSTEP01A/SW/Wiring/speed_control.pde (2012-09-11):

#include <SPI.h>

void command(char* buffer, unsigned int len)
{
  for (int i = 0; i < len; i++) {
    delay(10);
    digitalWrite(SS, 0);
    SPI.transfer(buffer[i]);
    digitalWrite(SS, 1);
  }
}

void goTo(unsigned int pos)
{
  char buffer[4];
  buffer[0] = 0x60;
  buffer[1] = pos >> 16;
  buffer[2] = (pos >> 8) & 0xff;
  buffer[3] = pos & 0xff;
  command(buffer, 4);
}

void setParam(unsigned int reg, unsigned int val, unsigned int len)
{
  char buffer[4];
  buffer[0] = reg;
  
  /* BUG: reg? */
  for (int i = 0; i < len; i++)
    buffer[i + 1] = (reg >> (8 * ((len - 1) - i))) & 0xff;
  
  command(buffer, 1 + len);
}

void setup()
{
  Serial.begin(9600);
  SPI.begin(SPI_MASTER, MSBFIRST, SPI_MODE3, SPI_CLOCK_DIV32);
  
  setParam(5, 0xd0, 2); // ACC
  setParam(6, 0xd0, 2); // DEC
  setParam(7, 0, 2); // MAX_SPEED
}

int readInt()
{
  char line[100];
  int i = 0;
  
  while (true) {
    if (Serial.available()) {
      byte c = Serial.read();
      
      if (c == '\n' || c == '\r') {
        Serial.println();
        line[i] = '\0';
        return atoi(line);
      }
      
      Serial.write(c);
      line[i++] = c;
    }
  }
}

void loop()
{
  int speed = readInt();

  int dir = speed > 0;
  if (!dir)
    speed = -speed;
  
  char buffer[4];
  buffer[0] = 0x50 | dir;
  buffer[1] = (speed >> 16) & 0xff;
  buffer[2] = (speed >> 8) & 0xff;
  buffer[3] = speed & 0xff;
  
  command(buffer, 4);
}

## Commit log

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2017-08-22 Revert "rename cat folder"
    This reverts commit f4aa2827b8baa90f410e4e18c9e75853c76a7b0e.
    [2x3MLAB_frame.scad, 3PHBRIDGE01A.DSN, 3x4MLAB_frame.scad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]
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2017-08-22 rm empty json html files, rename module.json files
    [SERVOHUB01A.json]
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2017-11-19 Correct folder structure
    [PCRD03A.kicad_pcb, PCRD03A.sch, charge_amp.sch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]
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2017-11-20 corrected pinout for OPA314
    [PCRD03A.kicad_pcb, PCRD03A.sch, charge_amp.sch]
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2017-11-27 add full names of components, change capacitors footprints
    [PCRD03A-B.Cu.gbr, PCRD03A-B.Mask.gbr, PCRD03A-B.SilkS.gbr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]
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2018-01-04 uSD card footprint adjusted to also accommodate the ATTEND 112J-TDAR-R01 socket
    [STM32F30xRx01A-B.Cu.gbr, STM32F30xRx01A-B.Mask.gbr, STM32F30xRx01A-Edge.Cuts.gbr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]
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2018-01-16 DRC check of schematics. Unconnected pins marked as unconnected.
    [FMC.sch, FMC2DIFF.sch, SATA.sch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]
2018-01-16 Dimensions moved to drawing.user layer. The PCB outlines edited to make a continuous polygon. This is important for automatic board data processing. The new dimensions in inches added.
    [STM32F30xRx01A.kicad_pcb]
2018-01-28 A PDF version of power module schematics plotted.
    [STEPDOWN1A.sch, STEPDOWN2A.sch]
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2018-02-25 Přesun špatně zařazených modulů + oprava v DB MLABwebu.
    [ALBASE1209.dxf, ALBASE2537.dxf, EEPROM02A.csv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]
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2018-03-07 Remove problematic files
    [RPS01A-B.Cu.gbr, RPS01A-B.Mask.gbr, RPS01A-Edge.Cuts.gbr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]
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2018-06-17 RTC03A - pridan schmittuv klopny obvod, pridana LED, pullupy pro adresu
    [RTC03A.kicad_pcb, RTC03A.sch, RTC03A.step]
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2018-08-01 Pridani obvodu pro SSN. Oprava resetu.
    [DATALOGGER01A.kicad_pcb, DATALOGGER01A.sch]
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2018-09-13 Založen nový modul pro řídící desku zařízení s více osami.
    [AXISCONTROL01A.kicad_pcb, AXISCONTROL01A.sch, SCH_PCB.kicad_pcb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]
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2019-01-23 Copy of code from WINDGAUGE01A before creation of new version design begins.
    [P_WINDGAUGE01A_D01.scad, P_WINDGAUGE01A_D02.scad, P_WINDGAUGE01A_R01.scad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]
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2019-02-06 Doplneni grid-fins podle: https://github.com/UniversalScientificTechnologies/AutomaticWeatherStation/issues/1
    [venturi_tube.scad, venturi_tube.stl]
2019-02-07 Pokračování tvorby modelu. Vytvoření tvarového přídavku pro umístění elektroniky. Z issue: https://github.com/UniversalScientificTechnologies/AutomaticWeatherStation/issues/1
    [WINDGAUGE_D01.scad, WINDGAUGE_D02.scad, WINDGAUGE_R01.scad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]
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2019-03-01 Přidání ochranného lemu a testovacího prostupu pro ložisko.
    [venturi_tube.scad, venturi_tube.stl]
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2019-03-15 update schematic by comment kaklik issue #5
    [VCAI2C02A.sch]
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2019-03-29 - doplněné přesné názvy součástek MCP a ADU integrovaného obvodu - doplněno MFPN pro měřící transformátor (100A verze) - změněny pouzdra R a C na 0805
    [VCAI2C02A.kicad_pcb, VCAI2C02A.sch]
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2019-04-03 Updated WindGauge 3A with opening PCB casing, cabling pipeline and Venturi tube windpipes.
    [venturi_tube.scad]
2019-04-04 Fixed WindGauge 3A cabling pipeline and Venturi tube windpipes.
    [venturi_tube.scad]
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2019-04-04 Reworked broken WindGauge 3A cabling pipeline and Venturi tube windpipes.
    [venturi_tube.scad]
2019-04-04 Commented out prototyping cut-out cube from WindGauge 3A.
    [venturi_tube.scad]
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2019-04-09 Editing printig models and files Creating makefile Render printing files
    [P_WINDGAUGE01A_D02.stl, P_WINDGAUGE01A_R01.stl, P_WINDGAUGE01A_R03.stl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]
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2019-04-12 Venturi tube height can be changed by parameter V_h in WindGauge 3A.
    [WINDGAUGE_R03.scad]
2019-04-13 WINDGAUGE03A - Renamed parameters to be more readable. Added parameter global_clearance for fine printer settings. Pressure tubes replaced to vertical position + added parameters R03_sensor_offset an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
    [WINDGAUGE_R03.scad, WINDGAUGE_R04.scad, configuration.scad]
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2019-04-18 correct resistor value R4 to 40.2k, R6 to 16.9k
    [VCAI2C02A.sch]
2019-04-22 WINDGAUGE03A - Updated PCB casing to ease printing. KNOWN ISSUE - Drop shape lid does not cut-out triangular prism. Lid will not fit on model.
    [WINDGAUGE_R03.scad, WINDGAUGE_R04.scad, configuration.scad]
2019-04-23 Fixed polyhedrons and cabling intake.
    [WINDGAUGE_R03.scad]
2019-04-23 WINDGAUGE03A - fixed drop shape TOP cut-out (commented instead of prototyping cut-out cube by mistake).
    [WINDGAUGE_R03.scad]
2019-04-23 WINDGAUGE03A - Added parameter R03_sealing_ring_thickness to account for sealing rings in airtubes.
    [WINDGAUGE_R03.scad, configuration.scad]
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2019-04-24 Fix poor resolution of PCB cover.
    [P_WINDGAUGE03A_R04.scad, P_WINDGAUGE03A_R04.stl]
2019-04-25 WINDGAUGE03A #10 - Printing tolerance is now added only in the lid cut-out, not on tube platform. Lid cut-out cube size doubled.
    [WINDGAUGE_R03.scad, WINDGAUGE_R04.scad, configuration.scad]
2019-04-28 WINDGAUGE03A #13 - Replaced screw holes with bolt holes and nut pockets.
    [P_WINDGAUGE03A_R03.stl, P_WINDGAUGE03A_R04.stl, WINDGAUGE_R03.scad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]
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2019-04-30 WINDGAUGE03A #12 - Small fix for parameter R03_slip_ring_offset to work. Do not exceed [-20:20] or cabling hole will penetrate the tube body.
    [WINDGAUGE_R03.scad, configuration.scad]
2019-04-30 WINDGAUGE03A #13 - Fixed forgotten R03_inner_screw_diameter. Added R03_global_clearance around nuts and bolts.
    [P_WINDGAUGE03A_R03.stl, P_WINDGAUGE03A_R04.stl, WINDGAUGE_R03.scad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]
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2019-05-02 WINDGAUGE03A #15 - Updated venturi tube with fin holders and cut-out. Fixed parameter name R01_vyska_prekryti_statoru in WINDGAUGE_S01.scad.P_WINDGAUGE03A_R03.stl
    [WINDGAUGE_R03.scad, WINDGAUGE_S01.scad, configuration.scad]
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2019-05-03 WINDGAUGE03A #12 - Added cut-out for balance weights. Size can be adjusted by changing parameters R03_balance_shelf_width and R03_balance_shelf_height (depth is set to max - not configurable).
    [WINDGAUGE_R03.scad, configuration.scad]
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2019-05-05 WINDGAUGE03A #10 - Moved PCB cut-out ceiling upwards 0.75 to compensate for printer inaccuracy.
    [P_WINDGAUGE03A_R04.stl, WINDGAUGE_R03.scad]
2019-05-05 WINDGAUGE03A #10 - Changed fixed 0.75mm vertical separation for 1.5xR03_global_clearance.
    [WINDGAUGE_R03.scad]
2019-05-05 WINDGAUGE03A #16 - A little house-cleaning -> no change in model (hopefully :-) ).
    [WINDGAUGE_D02.scad]
2019-05-05 WINDGAUGE03A #16 - Added holes and nut pockets for magnets. Middle base nut pocket moved to the opposite side of base. Renamed configuration parameters (mostly translated to english).
    [P_WINDGAUGE03A_D02.scad, P_WINDGAUGE03A_D02.stl, WINDGAUGE_D02.scad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]
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2019-05-06 WINDGAUGE03A #15 - Fixed bolt holes distance.
    [P_WINDGAUGE03A_R05.stl, WINDGAUGE_R05.scad]
2019-05-06 WINDGAUGE03A #15 - Fixed holder width to fit 12mm bolt.
    [configuration.scad]
2019-05-07 WINDGAUGE03A #16 - Added global_clearance to magnet base diameter. Added thin layer over magnet bolt hole to improve printing. Moved magnet holes closer to the edge of base.
    [P_WINDGAUGE03A_D02.stl, WINDGAUGE_D02.scad, configuration.scad]
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2019-05-11 WINDGAUGE03A #16 - Added draft parametr into the model. If draft = true, model is™ in original position with reduced resolution to achieve short rendering time. If draft = false, model is moved to pr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
    [WINDGAUGE_D02.scad]
2019-05-15 WINDGAUGE03A #18 - Updated Makefile to check dependencies, compile only print versions of models and create PNG images from STL files instead of rendering them again. Created new folder with models d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
    [P_WINDGAUGE03A_D02.scad, P_WINDGAUGE03A_D02.stl, P_WINDGAUGE03A_R01.scad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]
2019-05-16 WINDGAUGE03A #18 - Dependency files are now sorted to avoid false git changes.
    [WINDGAUGE_R03.stl]
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2019-06-13 WINDGAUGE03A #11 - Created cut-out for extra cabling. Changed moreShapes.scad library module torusSlice to use difference instead of intersection for improved performance.
    [WINDGAUGE_R03.scad, WINDGAUGE_R03.stl]
2019-06-13 WINDGAUGE03A #11 - Reverted prototyping changes forgotten in last commit.
    [WINDGAUGE_R03.scad, WINDGAUGE_R03.stl]
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2019-08-02 Vygenerovani souboru pro tisk. FIX: #8
    [888_1001.stl, 888_1002.scad, 888_1002.stl]
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2019-08-16 Preulozeni v nove verzi Kicadu. FIX: #20
    [I2CADC02A.sch]
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2019-09-04 WINDGAUGE03A #21 - Fixed nut/bolt holes for fin holder in non-draft mode.
    [WINDGAUGE_R03.scad, WINDGAUGE_R03.stl]
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2019-09-25 Fix supplies in PROGLOG01A schematics
    [PROGLOG01A.sch]
2019-09-25 Fix supplies in PROGLOG01A schematic
    [PROGLOG01A.sch]
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2019-10-14 Change footprints and make a minor fix
    [PROGLOG01A.sch]
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2019-10-22 Start drawing, make some fixes to schematic
    [PROGLOG01A.kicad_pcb, PROGLOG01A.sch]
2019-10-23 @ChroustJan, překresleno QFHMIX01A. Jediná nesrovnalost je, že se mi nepovedl najít LM1117MP-3.3/NO ale jiný LM1117 z MLAB-knihovny tak zda je totožný?
    [LNA.sch, QFHMIX01A.kicad_pcb, QFHMIX01A.sch]
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2019-11-04 Fix layout issues
    [PROGLOG01A.kicad_pcb]
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2020-01-22 Přegenerování souborů novou verzí OpenSCADu Problém s STL S01 vyřešen ručním vygenerováním AMF.
    [P_AWSCREEN01A_D02.amf, P_AWSCREEN01A_D03.amf, P_AWSCREEN01A_D04.amf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]
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2020-02-11 FIX hole in front of PCB covering drop. start to shift the covering drop from the front of the venturi tube.
    [WINDGAUGE_R03.scad, configuration.scad]
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2020-02-20 Improving the magnetic variant base stability.
    [WINDGAUGE_D02.scad, configuration.scad]
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2020-03-11 Odebrání kapsy pro kabely Odstranění chybně oříznutého výstupku pro PCB Zvětšení průměru nejužší části anemometru.
    [WINDGAUGE_D02.stl, WINDGAUGE_R03.scad, WINDGAUGE_R03.stl]
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2020-03-23 #WINDGAUGE03A #28 - Changed direction of viring tube connection from the bottom to the side.
    [WINDGAUGE_R03.scad, WINDGAUGE_R03.stl]
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2020-03-25 WINDGAUGE03A #29 - Enlarged space between PCB platform and drop cover for viring.
    [WINDGAUGE_R03.scad, WINDGAUGE_R04.stl]
2020-03-26 #WINDGAUGE03A #30 - Increased gap between S01 and R03 parts by 0,4mm. Gap is now 1mm (2*R03_global_clearance) instead of 0,6mm (0,5*S01_sila_materialu)
    [WINDGAUGE_R03.scad]
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2020-10-24 Revert "Merge branch 'master' of github.com:MLAB-project/Modules"
    This reverts commit 8871bd020ee63a46bdabe50dd5ee7a4e5caf6088, reversing
    changes made to cd90d741982699a20ffe23553052a8fbeb6b069f.
    Pokus o zachranu submodulu smazanych commity od @ChroustJan
    [DRILL.DRL, ISM01A-B.Cu.gbr, ISM01A-B.Mask.gbr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]
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2022-02-17 Adding correct submodule for Octal input ADC.
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
